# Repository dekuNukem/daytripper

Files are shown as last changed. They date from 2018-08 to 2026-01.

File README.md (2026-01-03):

# Daytripper: Hide-My-Windows Laser Tripwire

[Buy on Tindie](https://www.tindie.com/products/dekuNukem/daytripper-hide-my-windows-laser-tripwire/) | [Official Discord](https://discord.gg/VM4kbnf) | [Getting Started](quick_start_guide.md)

-----

Do you always slack off on your computer and worry about getting busted?

Not anymore because Daytripper is here to save the day!



Daytripper is a laser tripwire that can, upon triggering:

* Hide all your windows
* Lock your computer
* [Execute a custom script](/advanced_usage.md) to do whatever you want!

## Buy Daytripper on Tindie!

I did a small production run, and you can buy them directly on Tindie:

https://www.tindie.com/products/dekuNukem/daytripper

## How it Works

Daytripper comes in two parts: a Transmitter (TX) and a Receiver (RX).

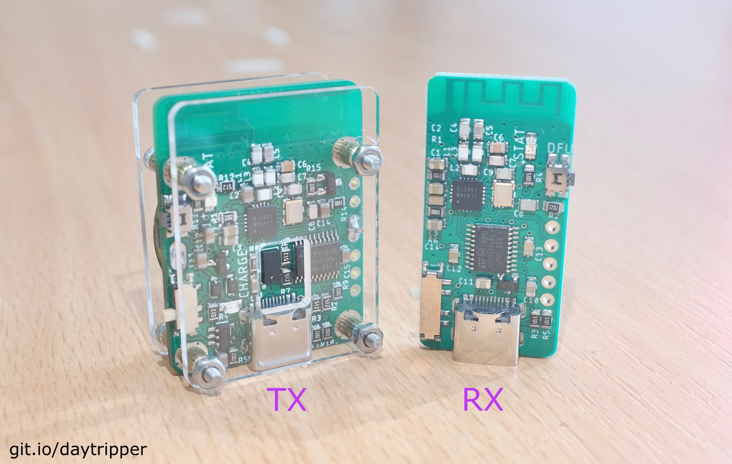
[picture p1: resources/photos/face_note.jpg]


Mount the TX in the path of incoming threat. Plug RX into your computer.

When motion is detected, RX will press `Win + M` and instantly hide what you're doing.

Alternatively, it can also lock your PC or [execute a custom script](/advanced_usage.md).

## Features

Daytripper...

* Can detect motion within 120cm (4 ft).

* Scan rate: 6Hz on battery, 30Hz while powered. Customisable with included software.

* Configurable parameters to suit your particular needs.

* 50-hour battery life, rechargeable via USB-C.

* Works out-of-box with Windows, compatible with all major OSs.

* 100 meter (330 ft) open-air communication range between TX and RX.

* Comes with a magnetic mounting kit.

* See [Quick Start Guide](https://github.com/dekuNukem/daytripper/blob/master/quick_start_guide.md) and [Advanced Usage Guide](https://github.com/dekuNukem/daytripper/blob/master/advanced_usage.md) for more details.

## Getting Started

If you received your Daytripper in kit form, follow this to put it together:

[Kit Assembly Guide](/assembly_guide.md)

For how to use Daytripper, see this:

[Quick Start Guide](/quick_start_guide.md)

For advanced features such as custom actions and adjusting settings, read this:

[Advanced Usage](/advanced_usage.md)

## Specification

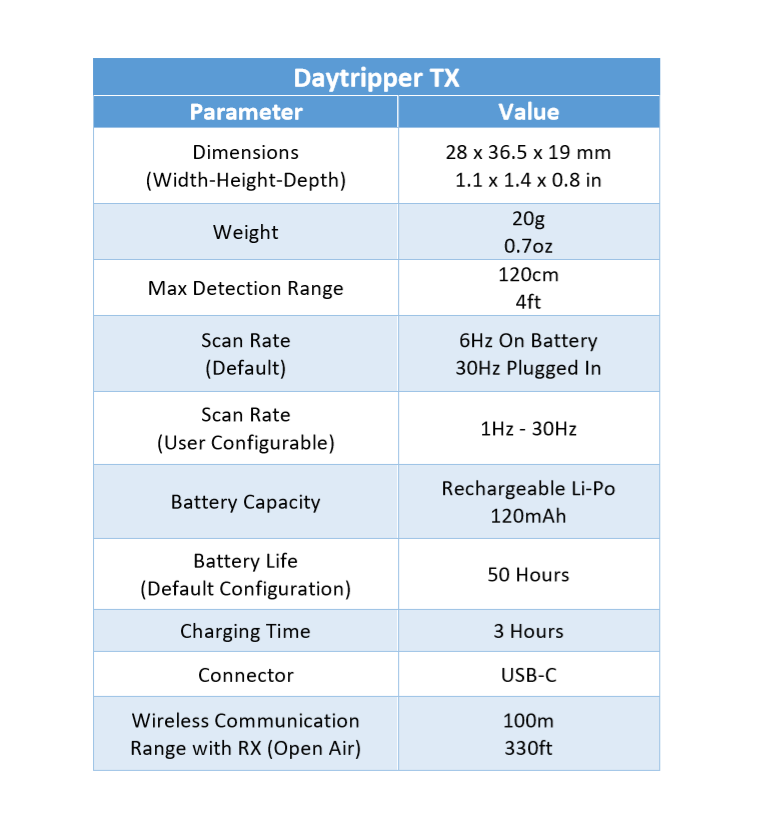
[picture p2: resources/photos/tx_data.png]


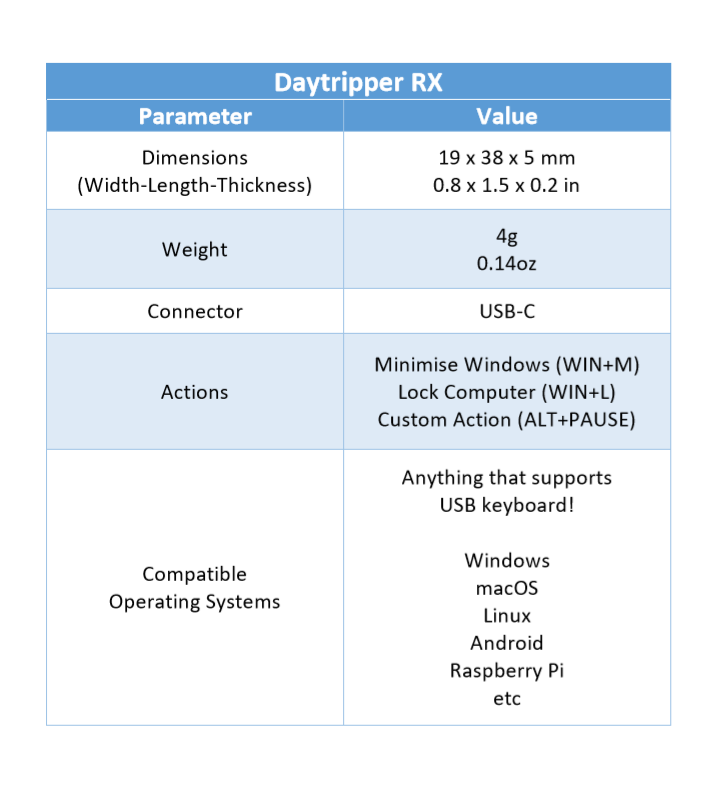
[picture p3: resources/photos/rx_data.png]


## FAQ

### What operating system is supported?

Daytripper works out-of-box with Windows. No driver needed.

It is also compatible with anything that supports USB keyboards, such as Linux, MacOS, Android, and more.

Read [Advanced Usage Guide](/advanced_usage.md) to see how to use it on other systems.

### What is the range of Daytripper?

The laser ToF sensor can detect motion within 120cm (4 ft).

The wireless communication range between TX and RX should be around 100 meters (330 feet) open air. Might be less in indoor environments. 

### Battery life?

Around 50 hours (more than 2 days!) with default configuration.

Can be increased or decreased by adjusting settings.

Rechargeable via USB Type-C connector.

### Can I use it for purposes other than hiding windows?

Yes. It can also lock your computer, or perform a custom action.

See [Advanced Usage Guide](/advanced_usage.md).

## I Want One!

I did a small production run, and you can buy them directly on Tindie:

https://www.tindie.com/products/dekuNukem/daytripper

## Questions or Comments?

Please feel free to [open an issue](https://github.com/dekuNukem/duckypad/issues), ask in the [official Daytripper discord](https://discord.gg/VM4kbnf), DM me on discord `dekuNukem#6998`, or email `dekuNukem`@`gmail`.`com` for inquires.

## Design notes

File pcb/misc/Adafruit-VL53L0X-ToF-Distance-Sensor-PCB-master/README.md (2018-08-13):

# Adafruit-VL53L0X-ToF-Distance-Sensor-PCB
PCB files for the Adafruit VL53L0X ToF Distance Sensor

Format is EagleCAD schematic and board layout

For more details, check out the product page at

  * https://www.adafruit.com/product/3177

Adafruit invests time and resources providing this open source design, 
please support Adafruit and open-source hardware by purchasing 
products from Adafruit!

Designed by Adafruit Industries.  
Creative Commons Attribution, Share-Alike license, check license.txt for more information
All text above must be included in any redistribution

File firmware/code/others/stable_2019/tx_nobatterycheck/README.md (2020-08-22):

This is a slightly modified TX firmware for always-plugged-in applications. 

Changes include:

* 30Hz refresh rate, compared to default 5Hz
* Microcontroller won't enter low-power mode anymore
* Microcontroller doesn't check battery voltage

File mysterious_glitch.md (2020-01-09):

# The Baffling Intermittent Glitch

## Discovery

Recently a few of my customer told me that the daytripper they received didn't work properly after assembled. Once turned on, the LED on the TX unit would breath for a few seconds, then go completely dead and not responding to objects in front of the sensors. 

I initially provided them with free replacements right away, however it did make me wonder how did it happen, since I personally test every single board before mailing them out.

One of the customers told me that the affected TX would work fine on its own as a bare circuit board, but go bad once assembled with front and back plates, which was even more baffling. How could some screws and two acrylic plates affect the functionality of the circuit board?

## Investigation

I put together a handful of TX boards trying to replicate the problem, testing to make sure they work both before and after. I assembled about 20 of them before finally got one that's misbehaving. The board would work fine on its own, but stop working once the upper standoffs were tightened to a certain degree.

I hooked up a debugger to see where it was stuck in the firmware. It appeared to be waiting forever at [checking if a packet transmission is complete](https://github.com/dekuNukem/daytripper/blob/865081e2ba3adbdf7ebfdae3229aa89da2c86ae7/firmware/tx_bss/Src/helpers.c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). Looking deeper into that, the data received from SPI are all `0x0` instead of usual `0x13`.

I didn't think much of it and kept on messing around. At one point I desoldered the battery to see if it would help, and miraculously it did! The TX would work no matter how much the standoffs were tightened. 

Things became clear once I looked at the circuit board more closely. Here is the back of the affected TX board, you can just barely see a scratch mark near the center:

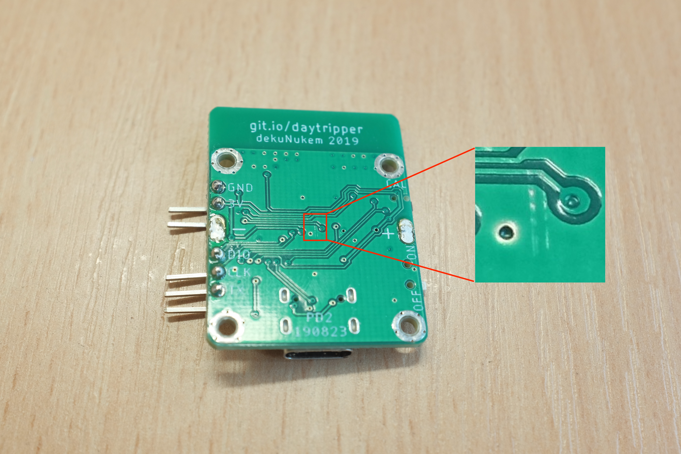
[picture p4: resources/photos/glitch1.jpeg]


What happened was that, on certain batteries, the negative terminal tab sticks out more than others:

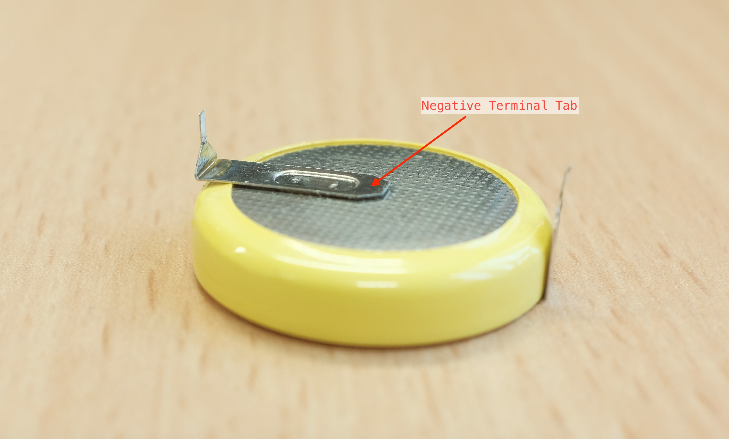
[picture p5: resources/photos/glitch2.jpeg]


As a result, for the majority of the boards, there is an air gap between the bottom of the battery and the circuit board, all is well:

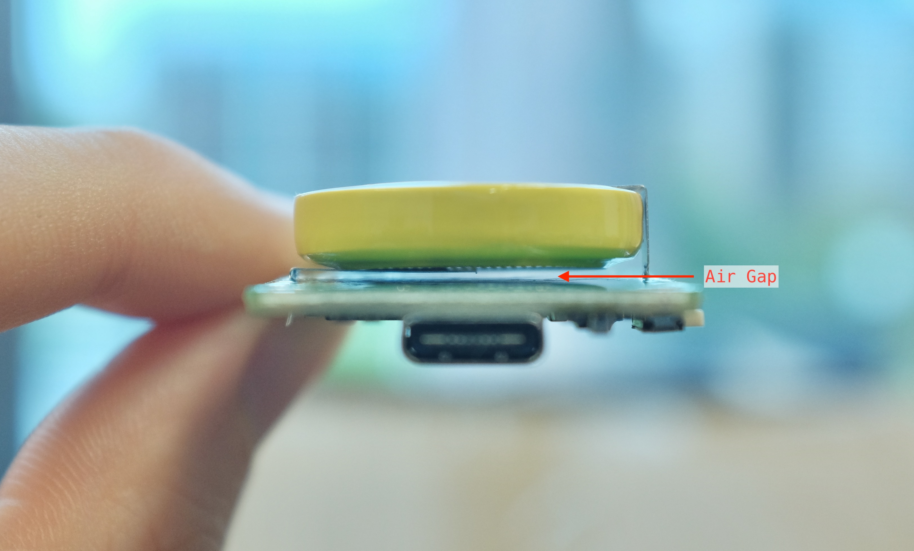
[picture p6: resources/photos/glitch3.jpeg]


But on the affected boards, the protruding battery terminal is very nearly touching the circuit board:

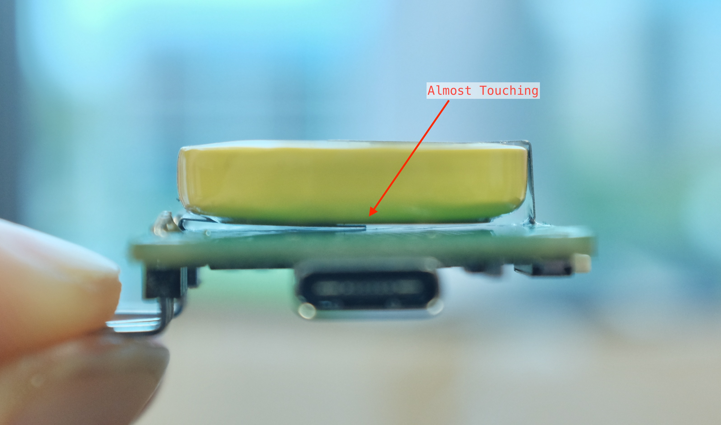
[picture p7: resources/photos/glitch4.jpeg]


Since they were not *actually* touching, everything would work fine when I test the bare circuit board myself. But when installed with fasteners, the back plate would push the terminal into the circuit board, scratching it, and grounding the SPI MISO data line. As a result, the firmware would get `0x0` from SPI, and stuck on waiting for a response.

## Remedy

From now on...

* Insulating materials will be added between the battery and circuit board

* Washers will be used so the back plate is less likely to push against the battery

* Visual inspection will be carried out to spot problem boards before shipping

* Traces will be rerouted away from potentially scratch-prone area in the future production run

## Existing Customers

This problem only affects a very small number of TX boards. If your daytripper is working fine, you don't have to do anything.

If you do encounter a similar problem, there are a number of ways to sort this out:

### Try Fixing It Yourself

* [Follow this guide in reverse](https://github.com/dekuNukem/daytripper/blob/master/assembly_guide.md) and disassemble the TX to bare circuit board.

* Hold it like the above photos, check the gap and see if battery is touching the board

* Try inserting a piece of paper between the two to prevent them from touching. Gently pull the battery up slightly to widen the gap, then slide the paper in.

* If it works, congrats! Feel free to contact me for a partial refund for the trouble.

* If not...

### Contact Me

If you weren't able to fix it yourself, do feel free to contact me with your Tindie order number. I'll be happy to offer you a full refund or mail you another set for free.

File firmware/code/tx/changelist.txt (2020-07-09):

switched to single ADC channel for battery voltage calculation
system clock now 16MHz to allow USB peripheral to function
added rtc sleep function, on-demand delay in stop mode.
reduce power consumption by 15% by putting uC in stop mode while waiting for ToF measurement.

TODO:
re-enable low-battery shutdown
change IWDG timeout prescaler back to 32
add charging detection
comment out printf() in check_battery()

current consumption observations:

sparkfun INA169 works really well
during sleep mode current is negligible
laser and nRF both consume around 20mA when active
negligible current difference between 8MHz and 16MHz clock, most of the time MCU is sleeping anyway.
negligible current on low-battery shutdown

USB initialization works only on fresh start-up
sleeping changes UART baud rate somehow

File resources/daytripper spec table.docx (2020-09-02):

Daytripper TX
Parameter | Value
Dimensions (Width-Height-Depth) | 28 x 36.5 x 19 mm 1.1 x 1.4 x 0.8 in
Weight | 20g 0.7oz
Max Detection Range | 120cm 4ft
Scan Rate (Default) | 6Hz On Battery 30Hz Plugged In
Scan Rate (User Configurable) | 1Hz - 30Hz
Battery Capacity | Rechargeable Li-Po 120mAh
Battery Life (Default Configuration) | 50 Hours
Charging Time | 3 Hours
Connector | USB-C
Wireless Communication Range with RX (Open Air) | 100m 330ft

Daytripper RX
Parameter | Value
Dimensions (Width-Length-Thickness) | 19 x 38 x 5 mm 0.8 x 1.5 x 0.2 in
Weight | 4g 0.14oz
Connector | USB-C
Actions | Minimise Windows (WIN+M) Lock Computer (WIN+L) Custom Action (ALT+PAUSE)
Compatible Operating Systems | Anything that supports USB keyboard! Windows macOS Linux Android Raspberry Pi etc

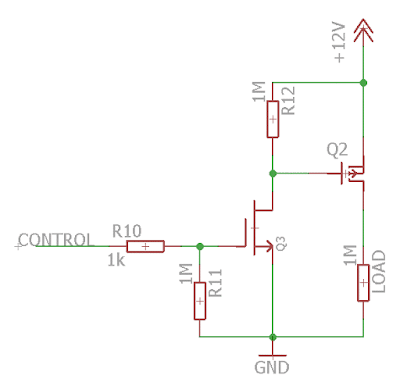
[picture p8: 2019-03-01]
resources/Part-time Electronics Basics FET as switch, part 2_files/pfet-2.png

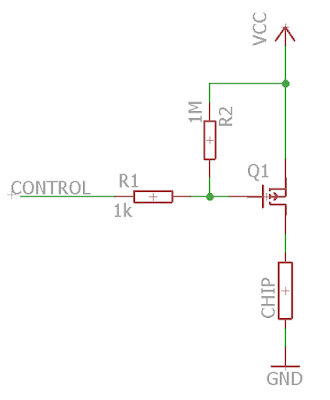
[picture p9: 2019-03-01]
resources/Part-time Electronics Basics FET as switch, part 2_files/pfet-1.png

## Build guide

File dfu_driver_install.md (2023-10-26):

# Installing the STM32 DFU Driver

First, make sure you have followed the procedure of **`holding down the DFU button while plugging in the device`**.

Once plugged in, you can release the button. The lights and screen should stay off.

If nothing shows up in `STM32 DfuSe tool`, you probably need to install a driver.

## Driver Install Instructions

**`Right click`** on the start button, then select `Device Manager`:

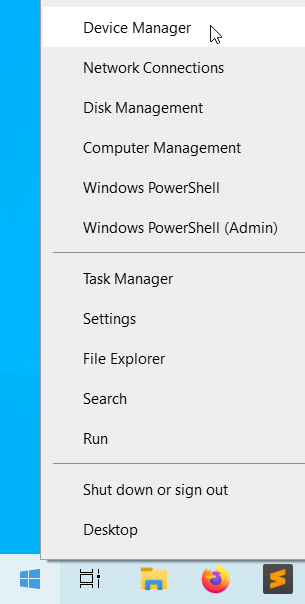
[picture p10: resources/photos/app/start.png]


Expand the node for USB devices. If you see a device with a similar name to **`STM32 Bootloader`**:

Right click, select `Uninstall Device`, check `Delete driver software` box, then press `Uninstall`.

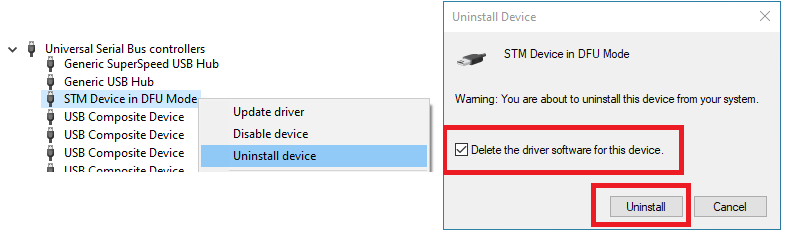
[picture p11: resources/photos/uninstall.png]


Now you should have a **`STM32 BOOTLOADER`** device with yellow triangle.

**`Double click`** on it, select `Update Driver...`, then select `Browse my computer for driver software`

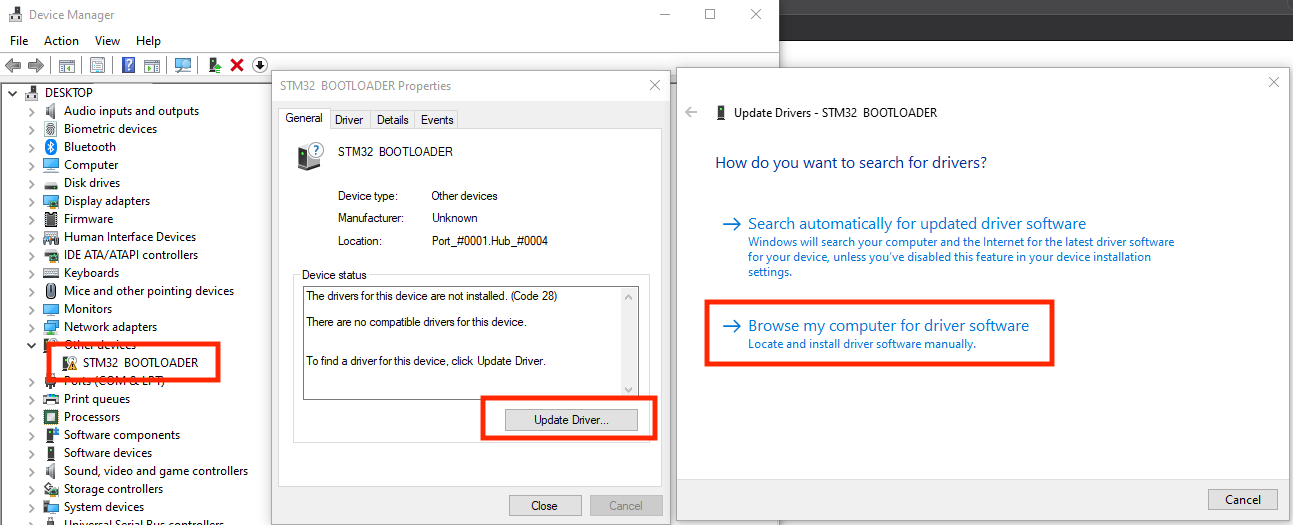
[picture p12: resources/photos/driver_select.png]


Press `Browse...`, and select the entire folder below:

`C:\Program Files (x86)\STMicroelectronics\Software\DfuSe v3.0.6\Bin\Driver\Win10`

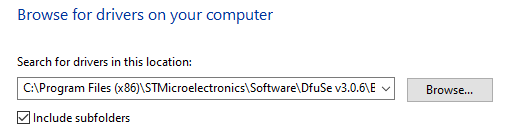
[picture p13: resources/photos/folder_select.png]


Windows should find and install the driver automatically.

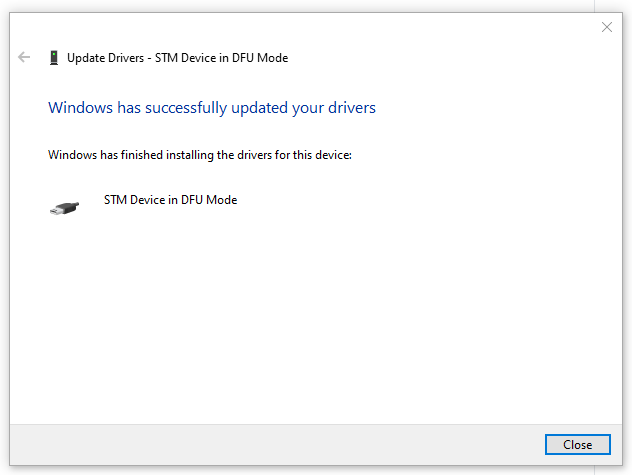
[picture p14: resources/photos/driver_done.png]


After it's done, you can continue the guide as usual.

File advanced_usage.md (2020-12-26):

# Daytripper Advanced Usage Guide

[Buy on Tindie!](https://www.tindie.com/products/dekuNukem/daytripper-hide-my-windows-laser-tripwire/) | [Official Discord](https://discord.gg/VM4kbnf) | [Getting Started](quick_start_guide.md) | [Main Page](/README.md)

-----

If you're not familiar with Daytripper yet, please see the [Quick Start Guide](/quick_start_guide.md) first.

## Table of Contents

[Creating Custom Actions](#custom-actions)

[Adjusting Advanced Parameters](#adjusting-advanced-parameters)

[On-Air Packet Format](#on-air-packet-format)

[Debug Mode](#debug-modes)

[USB Firmware Update](#usb-firmware-updates)

[Trigger Output](#trigger-output)

[Using Multiple Modules](#using-multiple-modules)

## Custom Actions

Instead of hiding windows, you can perform custom actions when TX is triggered.

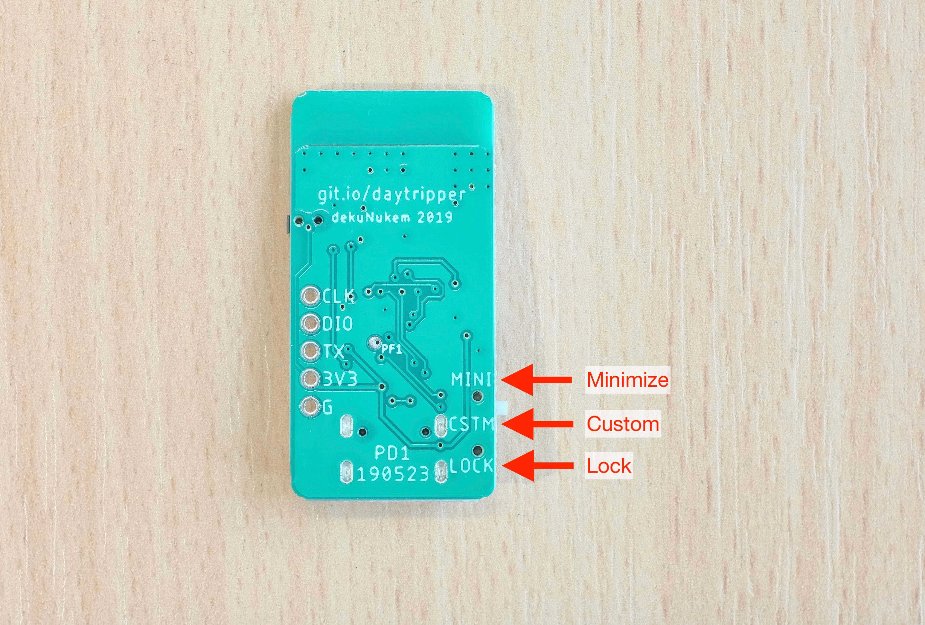
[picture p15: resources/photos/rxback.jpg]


Slide the `Mode Select` Switch on RX to `CUSTOM`, middle position. Now `ALT + PAUSE` will be pressed when TX is triggered. 

This key combo normally doesn't do anything, but you can capture it with a software and then perform your own actions. 

### Windows 

You can use [autohotkey](https://www.autohotkey.com). It is a powerful and free open-source keyboard automation program, where you can write a script to do anything you want when `ALT + PAUSE` is pressed by RX.

Check out the [official tutorials](https://www.autohotkey.com/docs_1.0/Tutorial.htm), and here's a [sample configuration file](resources/AutoHotkey.ahk) upon which you can tinker with. 

### macOS

When you first plug RX into your mac, a window might pop up asking to identify keyboard layout, simply close it.

Go to `System Preferences` -> `Keyboard` -> `Shortcuts` -> `App Shortcuts`:

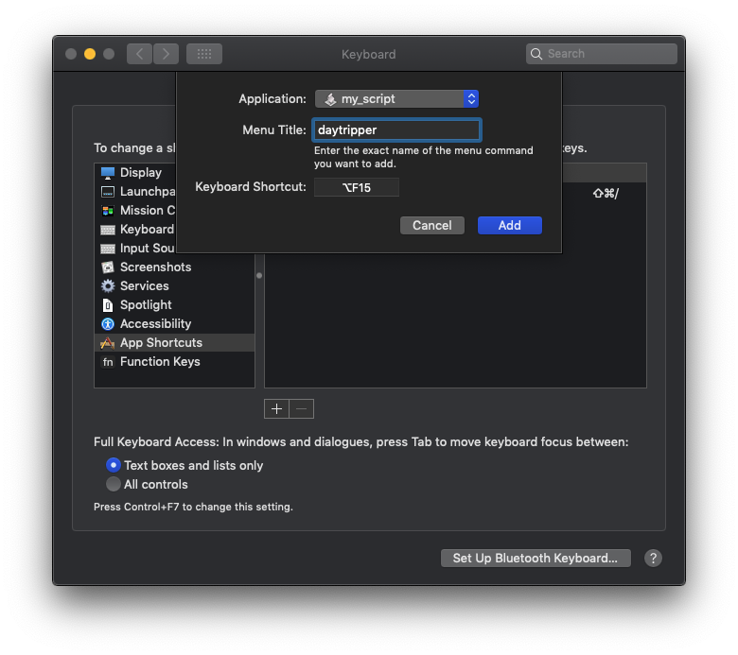
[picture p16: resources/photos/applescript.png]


Click the box to the right of `Keyboard Shortcut`, trigger the TX, and it will fill in the box for you.

You can then add a shortcut to launch an application, or execute an applescript.

For more advanced scripting needs, you can try [bettertouchtool](https://folivora.ai), which can be considered macOS equivalent of autohotkey.

### Android

Believe it or not Daytripper also works on Android!

You can use [Tasker](https://tasker.joaoapps.com) with [Autoinput plugin](https://joaoapps.com/autoinput/).

Here is a tutorial: https://forum.joaoapps.com/index.php?resources/react-to-keys-from-a-real-keyboard.79/

### Linux

Oh I'm sure you'll figure it out 😉

## Adjusting Advanced Parameters

The default settings of Daytripper demonstrates a good balance between accuracy, sensitivity, and battery life. 

However, you can also adjust them to suit your particular needs.

### Update the Firmware

If you purchased your Daytripper before **`Sept 2020`**, you will need to update your TX to the latest firmware. Please do so by following the [USB Firmware Update](#usb-firmware-updates) section below.

### Find the COM Port

**`Right click`** on the start button, then select `Device Manager`:



Make sure the TX is **`TURNED OFF`**, then plug it into your computer with a USB-C cable.

In the `Ports (COM & LPT)` section, A new `USB Serial Device` should appear.



Remember the number! **`COM5`** in this case. Yours might be different.

### Download the Application

[Head here to download the latest release](https://github.com/dekuNukem/daytripper/releases/latest) for Windows and macOS.

* The software is in early stages of development. If you run into any problems, please don't hesitate to [open an issue](https://github.com/dekuNukem/daytripper/issues), ask in the [official Daytripper discord](https://discord.gg/VM4kbnf), DM me on discord `dekuNukem#6998`, or contact me through `dekuNukem`@`gmail`.`com`.

### "Untrusted App" Warnings

When trying to run the app, your system might complain about this software being untrusted. This is because I haven't had the code digitally signed, which costs hundreds of dollars a year.

Please feel free to [review the code](https://github.com/dekuNukem/daytripper/tree/master/pc_software). If you don't trust the app, you can run the `duckypad_config.py` script itself with Python3.

For Windows 10, click `More info` and then `Run anyway`.

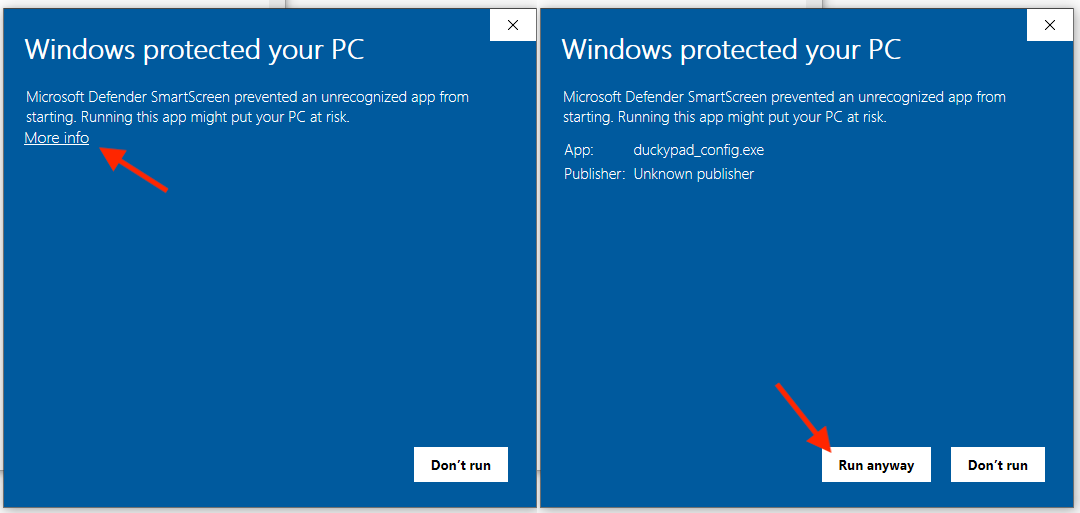
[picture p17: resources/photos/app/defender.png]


For macOS, **`RIGHT CLICK`** on the app and select `Open`. You might have to do it twice.

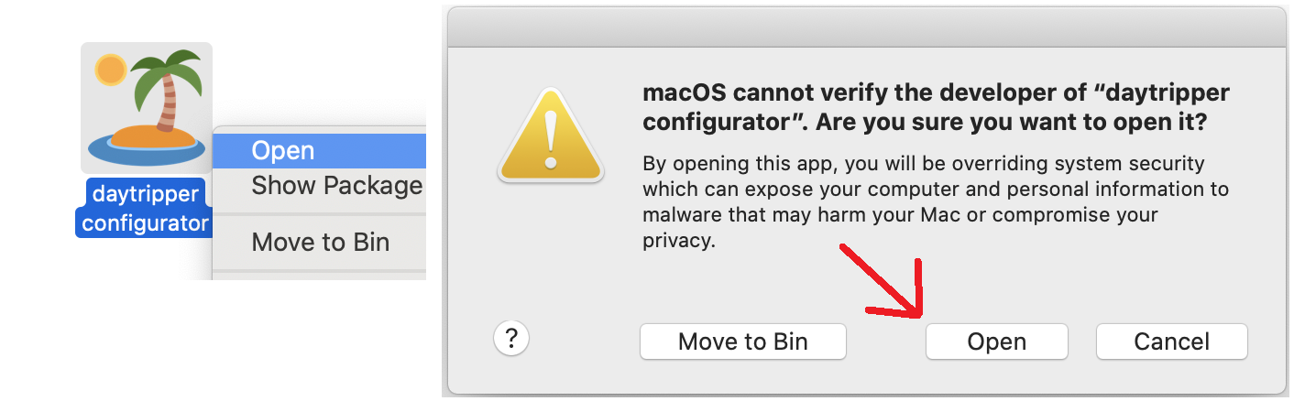
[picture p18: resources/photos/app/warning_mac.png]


After the app has launched, press `Refresh` button, select the COM port with the correct number, and press `Connect`.

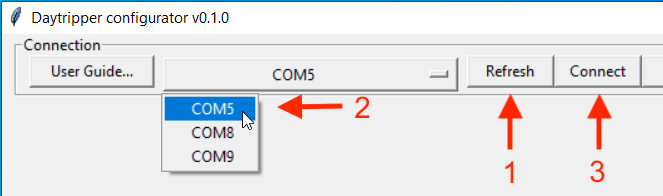
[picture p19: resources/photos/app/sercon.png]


On macOS or Linux, the serial port will have different names, and mostly likely will have the word `usb` in it.

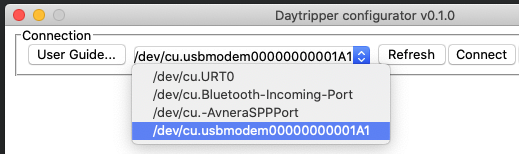
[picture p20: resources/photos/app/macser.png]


Anyway, if connection is successful, a number of options is presented:

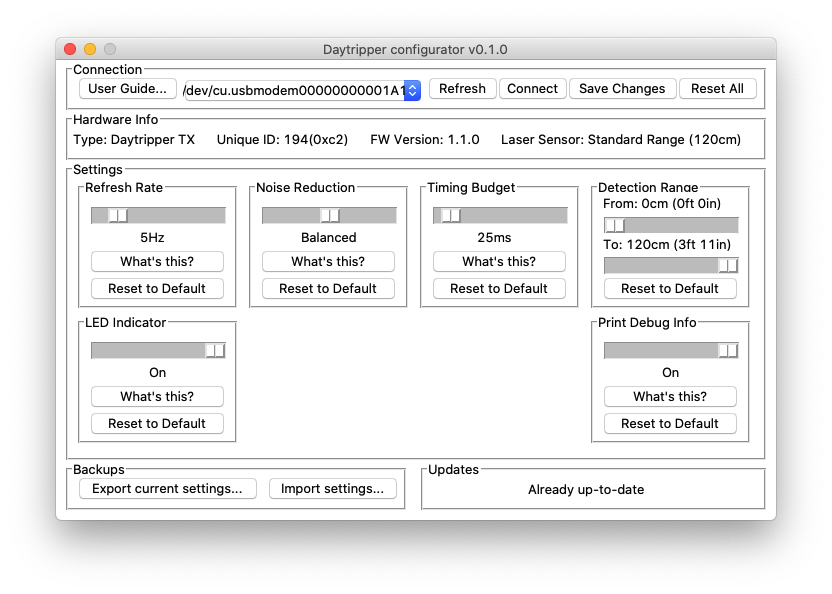
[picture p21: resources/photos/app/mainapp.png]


* Drag the slider to adjust values.

* Click **`What's this?`** to learn about a particular setting.

* To return to default, click **`Reset to Default`** in a section, or **`Reset all`** on top right corner.

* Click **`Save Changes`** to save the current configuration to your Daytripper.

* You can make a backup of your settings with the buttons on lower left corner.

* A description of parameters follows.

### Refresh Rate

How many times per second TX takes a reading **`while on battery`**. Turn it up to make TX more sensitive to faster motions, at the expense of battery life.

Here is a table of approximate Battery Life vs Refresh Rate:

| Refresh Rate (Hz) | Battery Life (Hours) |
|---|---|
| 2 | 100 |
| 6 (Default) | 50 |
| 10 | 30 |
| 15 | 20 |
| 30 | 12 |

Please note that your battery life might be more or less depending on your lighting conditions and number of triggers.

TX will always run at fastest refresh rate (30Hz) when plugged in.

### Noise Reduction

By default TX will take additional readings to prevent false triggers from sensor noise.

If turned off, TX will become **`much more`** sensitive to motion, but might also produce false triggers from time to time.

Turn it off if motion sensitivity is absolutely critical and occasional false triggers is acceptable.

### Timing Budget

Amount of time allocated to the laser sensor to produce a reading.

A larger value gives more accurate measurements, at the expense of reduced battery life and refresh rate.

I suggest leaving it at default for normal operations.

### Detection Range

Adjust the values here if you want Daytripper to only monitor motions within a certain distance range.

### LED Indicator

The blue LED comes on when TX is triggered. You can disable it to make your Daytripper less noticeable.

### Print Debug Info

TX prints some debug messages through its hardware UART. Turning it off might save a tiny bit of battery life.

### Save It!!

Again, don't forget to press **`Save Changes`** button to save the current configuration to your Daytripper.

## On-air Packet Format

Daytripper uses a nRF24L01-compatible chip called Si24R1. It is less expensive, and actually has a higher TX power output, resulting in longer communication range.

Daytripper operates at `channel 115`, `address 0xDA 0xBB 0xED 0xC0 0x0C`.

Data rate is `250kbps`, TX power is `+7dBm`, `Auto Acknowledgment` is used.

Daytripper TX sends 6-byte packets, details below:

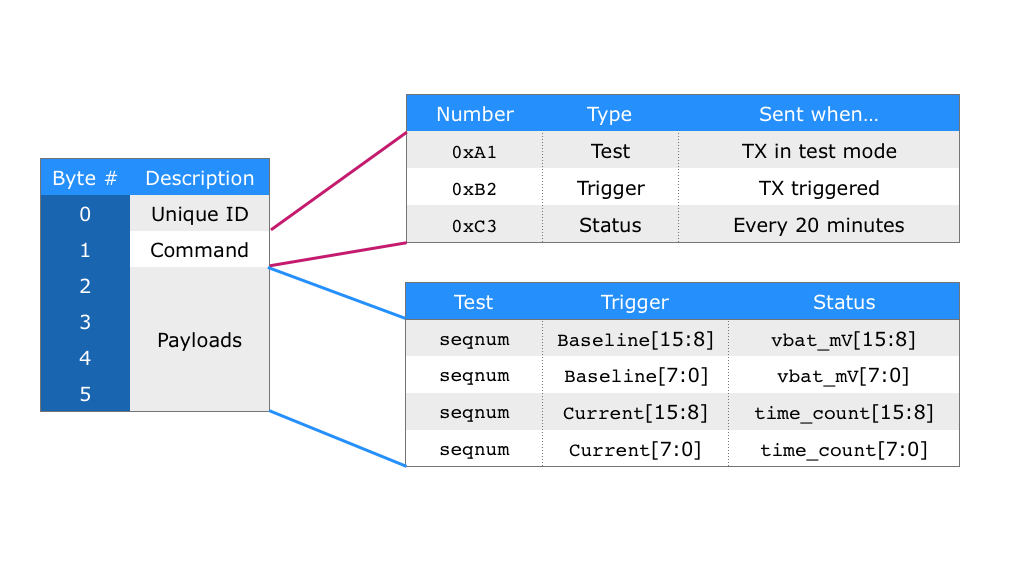
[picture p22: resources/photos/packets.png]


* The first byte (byte 0) is a unique identifier calculated from the microcontroller serial number. 

* Second byte (byte 1) denotes what this packet is about. It can be either a test packet, trigger packet, or status update packet.

* The rest 4 bytes are payloads, their meaning depending on the command type (byte 1).

* For a `Test` packet, the 4 bytes are the same incrementing sequence number repeated 4 times. 

* For a `Trigger` packet, the first two bytes are the baseline reading of the power-up calibration. And the last two bytes are the actual distance reading. Unit in mm.

* For a `status` packet, the first two bytes are the latest battery voltage reading in mV. The last two bytes are the time-since-power-on count, multiply it by 5 to get the number of seconds elapsed since TX power-on.

* The `vbat_mV` is about 300mV lower than the actual battery voltage, due to the diode drop. 

## Debug Modes

There is a user button on both TX and RX board. Usually they are unused:

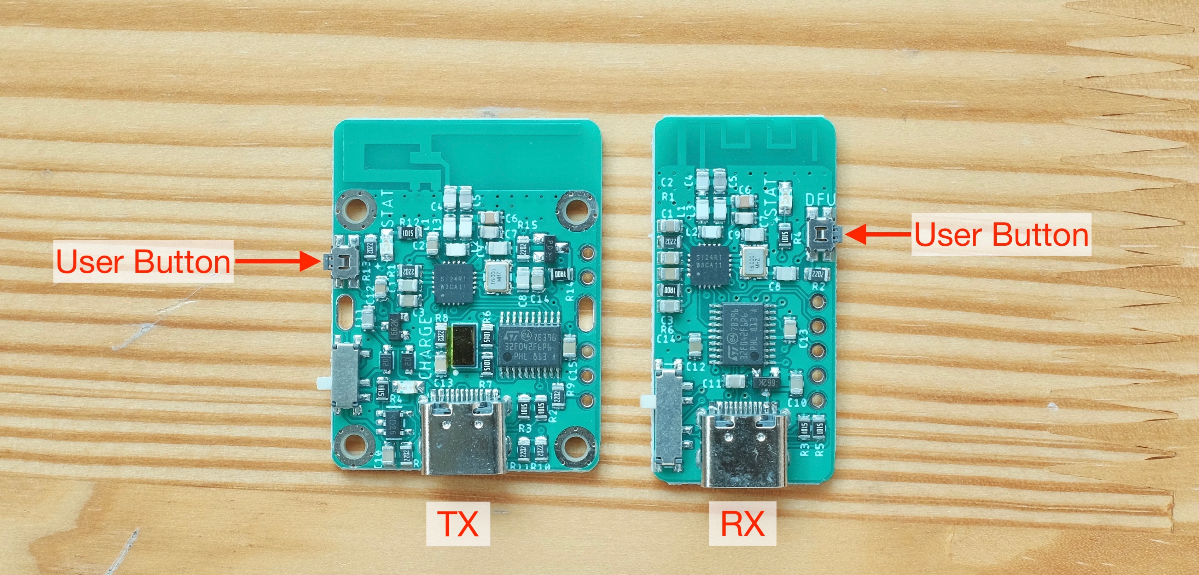
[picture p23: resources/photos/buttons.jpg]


For RX, a press on the button types out some debug messages. Make sure you open a text editor first. If the RX has not received any messages from the TX, the debug values will all be zero.

## USB Firmware Updates

You can update Daytripper's firmware via USB, for bug fixes and and/or new features. 

First, [click me](https://github.com/dekuNukem/daytripper/raw/master/resources/en.stsw-stm32080_stm32_DfuSe.zip) to download and install the `STM32 DfuSe tool` from this repo.

(You can also get it from [the official website](https://www.st.com/en/development-tools/stsw-stm32080.html), but it requires creating an account.)

Locate the user button on the board:



To update firmware:

* Make sure the board is **`TURNED OFF`** and unplugged.

* **Press and hold down the user button** while plugging it into a computer.

* Once it is plugged in, you can release the button.

* If all goes well, the blue LED should stay off.

Now launch the `DfuSeDemo` software:

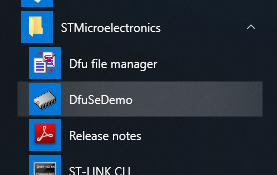
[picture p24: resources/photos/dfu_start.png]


You should see a `STM Device in DFU Mode` in the `Available DUF Devices` section at top left corner.

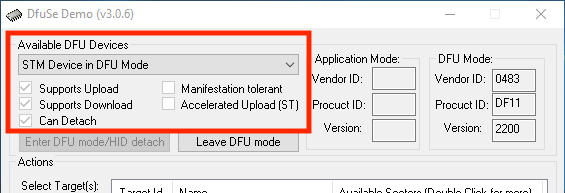
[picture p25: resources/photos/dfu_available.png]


* If nothing shows up, you might need to install a driver. [Click me for details](dfu_driver_install.md)  

Press the `Choose...` button and select a firmware file in `.dfu` format. Make sure it's the correct file!

* [Click me](https://github.com/dekuNukem/daytripper/raw/master/firmware/TX_1.1.2.dfu) for latest TX firmware (1.1.2)

* [Click me](https://github.com/dekuNukem/daytripper/raw/master/firmware/RX_1.0.1.dfu) for latest RX firmware (1.0.1)

* [Click me](/firmware_version_history.md) for older firmwares.

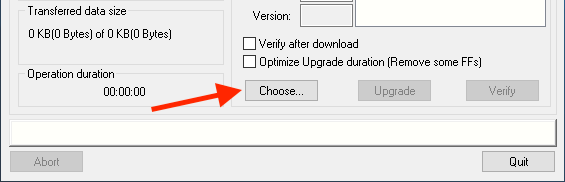
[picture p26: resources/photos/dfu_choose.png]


Press `Upgrade` button to start uploading the new firmware into the microcontroller.

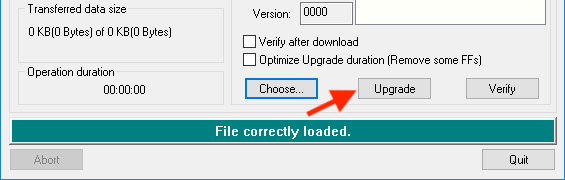
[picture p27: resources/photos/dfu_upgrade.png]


And now the firmware is being updated!

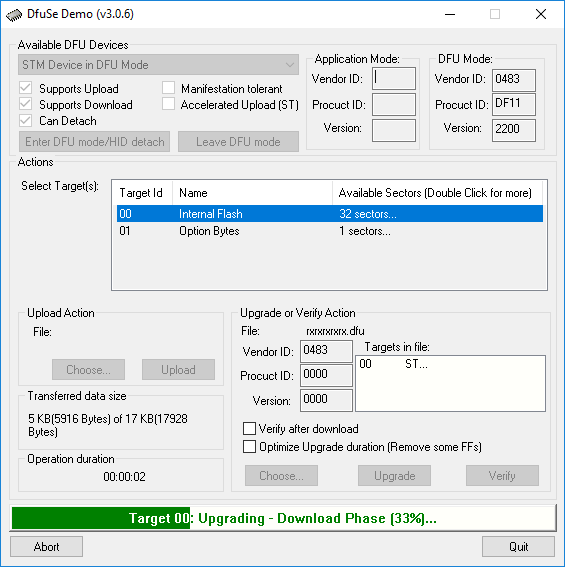
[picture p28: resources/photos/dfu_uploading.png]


It could take anywhere between a few seconds to a few minutes. Try using different USB ports if it is particularly slow. 

After uploading is complete, unplug and turn it back on to start using the new firmware. 

* Your custom settings will be lost after flashing a new firmware, so make sure to set it up again!

-----

If you generated a `.hex` file yourself, you can convert it to a `.dfu` file with the `Dfu file manager` and then upload this way. 

This method is nice for occasional firmware updates, but quite cumbersome if you want to do extensive reprogramming. It's faster to get a ST-Link programmer and use the Keil uVision IDE. [See this guide](https://github.com/dekuNukem/STM32_tutorials) for more information on STM32 developments.

## Trigger Output

There is an **`active-high`** trigger output on RX. This pin will go from GND to 3.3V for **`around 200ms`** when a trigger from TX is received.

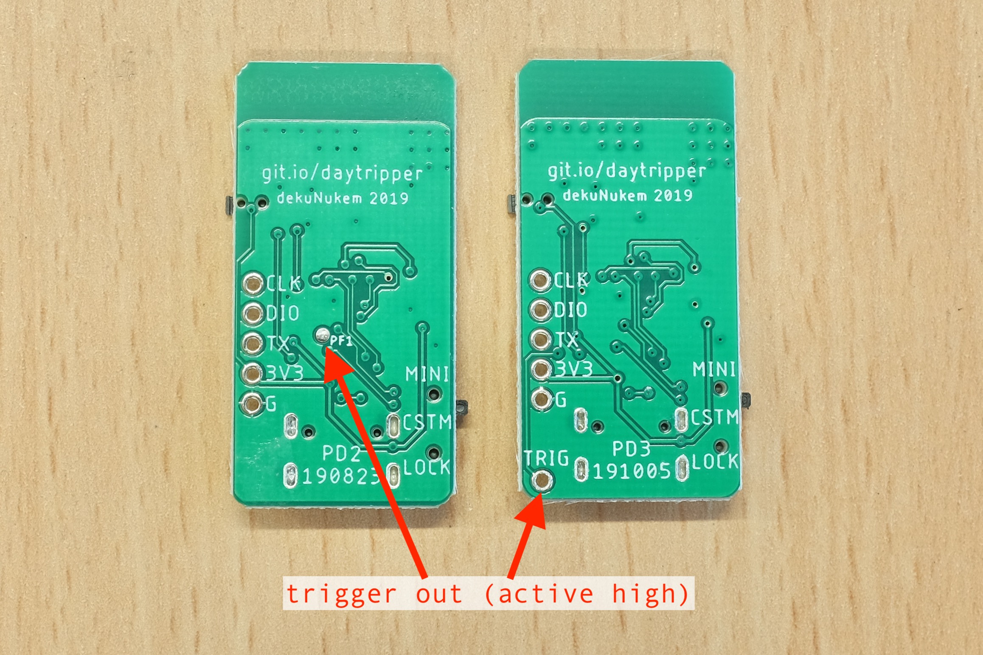
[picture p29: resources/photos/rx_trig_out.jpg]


On earlier production runs, the pin is on a testpad. On the later runs, the pin has its own header hole.

Make sure **everything is on the same GND** when connecting external circuits!

Unfortunately, TX does not have a dedicated trigger out pin due to limited microcontroller pins. However, there is a debug output that prints out some serial data upon triggering at 115200bps, which you can parse.

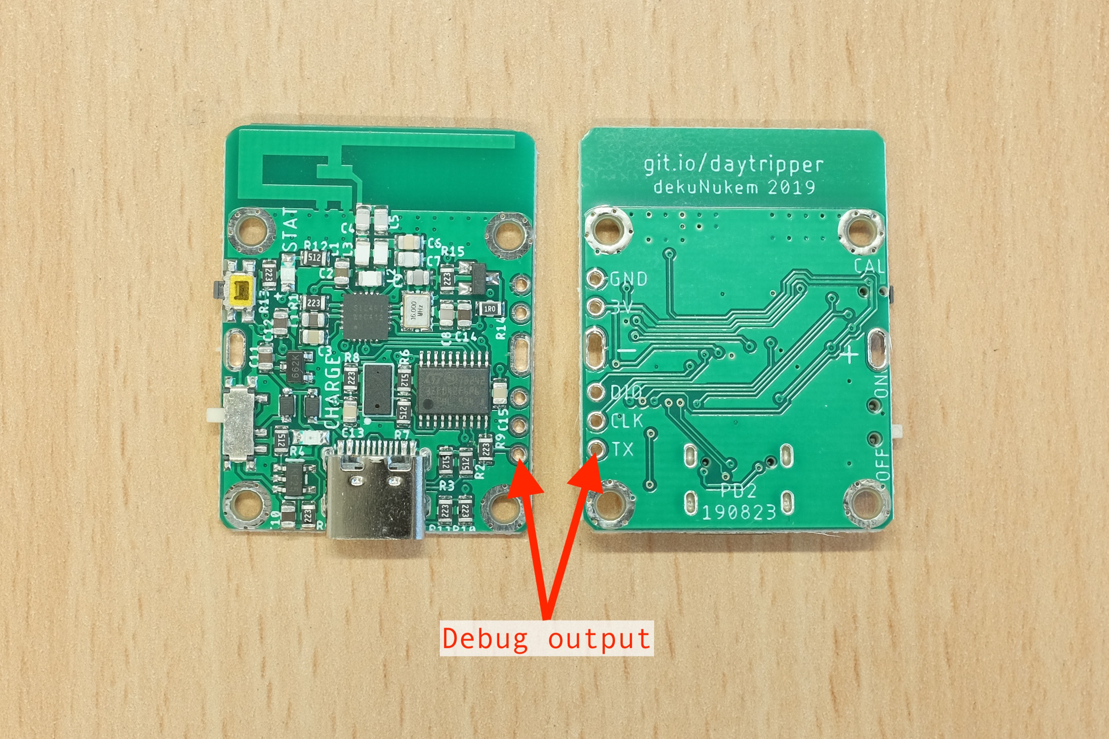
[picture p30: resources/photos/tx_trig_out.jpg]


## Using Multiple Modules

Daytripper wasn't really designed with multiple TX/RX boards in mind. I haven't done any extensive testings on this subject, however most of the time it does seem to work.

### Single RX Multiple TX

In this scenario RX will react when ANY of the multiple TX fires.

### Single TX Multiple RX

Here ALL of RX will react when TX fires.

### Multiple TX Multiple RX

Untested, probably a mess. 

## Questions or Comments?

Please feel free to [open an issue](https://github.com/dekuNukem/duckypad/issues), ask in the [official Daytripper discord](https://discord.gg/VM4kbnf), DM me on discord `dekuNukem#6998`, or email `dekuNukem`@`gmail`.`com` for inquires.

------

[Main Page](/README.md) | [Buy Daytripper](https://www.tindie.com/products/dekuNukem/daytripper)

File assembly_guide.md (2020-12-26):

# Daytripper Kit Assembly Guide

[Buy on Tindie!](https://www.tindie.com/products/dekuNukem/daytripper-hide-my-windows-laser-tripwire/) | [Official Discord](https://discord.gg/VM4kbnf) | [Getting Started](quick_start_guide.md) | [Main Page](/README.md)

-----

Thanks for purchasing Daytripper! Here is a short guide on how to put everything together.

If yours is already assembled, please move on to the [Quick Start Guide](/quick_start_guide.md).

## Recommended Tools

A pliers and a small Phillips-head screwdriver would make tightening the fasteners easier.

However this assembly is perfectly doable with your bare hands, so don't sweat if you don't have them.

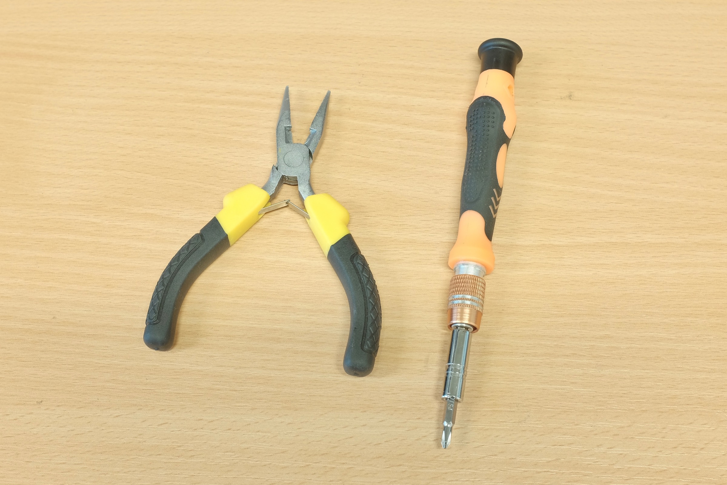
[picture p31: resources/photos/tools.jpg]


## Handling Bare Circuit Boards

When handling the bare circuit board, remember to:

* Wash your hands first

* Always hold the circuit board by its edge

* Don't touch the components

The reason for hand-washing is to reduce the risk of static electricity(SE) on your body zapping the board and damage it, especially in dry weather.

By washing your hands, you release the existing SE through the metal water pipe, your hands are moist to prevent further SE build-up, and your clean hands won't leave greasy fingerprints all over the place, win-win-win!

Of course, your hands can't be dripping wet either, but that's just common sense.

## Mind the Switches!

During assembly, be careful not to accidentally break off the handles of the switches on the two circuit boards:

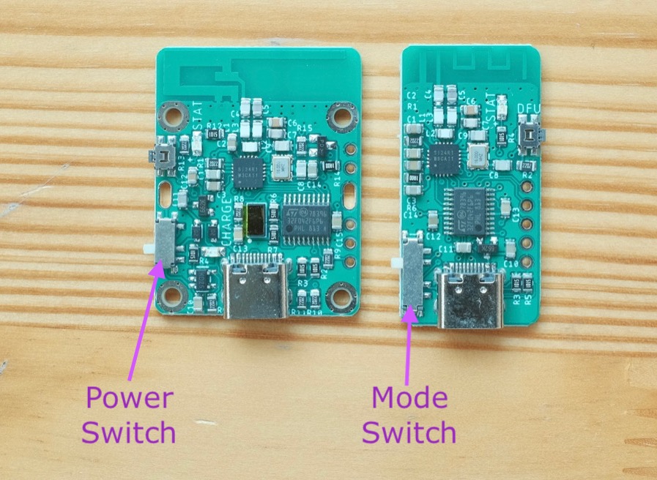
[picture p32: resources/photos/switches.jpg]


## Assembly Steps

You should have the following parts, keep a note of their names as I'm going to refer to them later. 

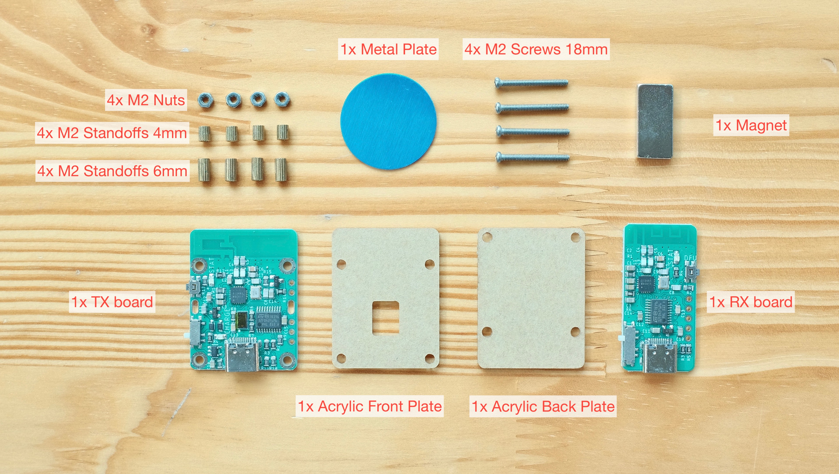
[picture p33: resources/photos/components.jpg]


First off peel off the protective film on the `Acrylic Front and Back plate`. You don't have to do it if you like the unpeeled look. 

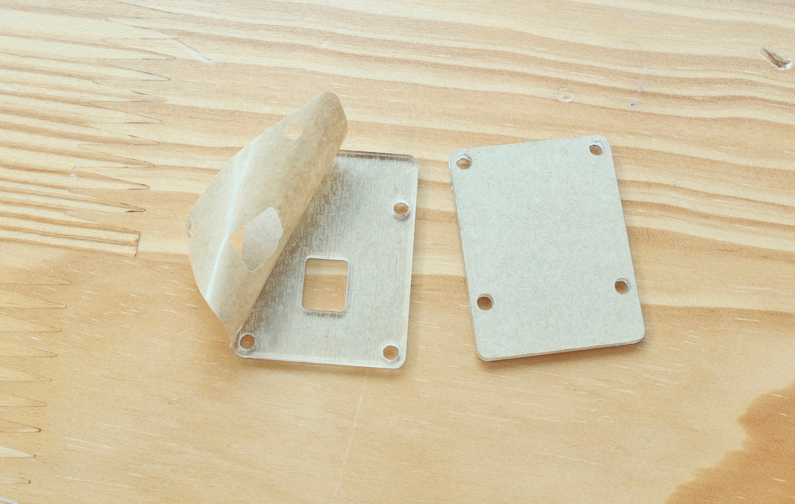
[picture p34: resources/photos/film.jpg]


Gather the `Acrylic Back Plate`, `4x M2 Standoffs 6mm`, and `4x M2 Screws 18mm`.

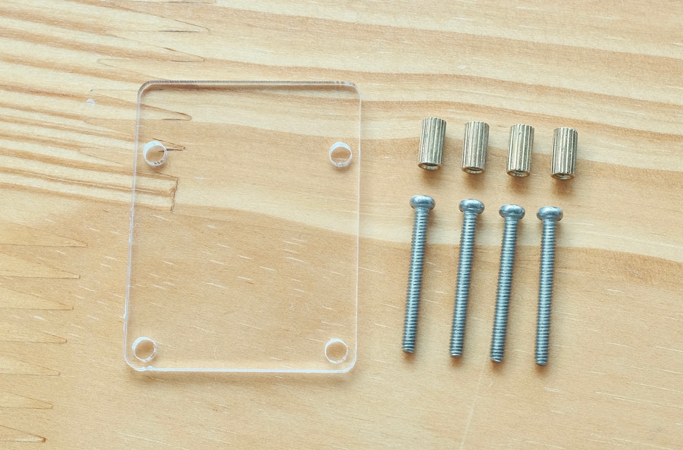
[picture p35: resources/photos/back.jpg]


Thread the screw through the hole, then screw on the standoffs.

Do not overtighten the standoff! Doing so might crack the acrylic plate. Finger-tight is OK, just make sure they're not loose and doesn't rattle.

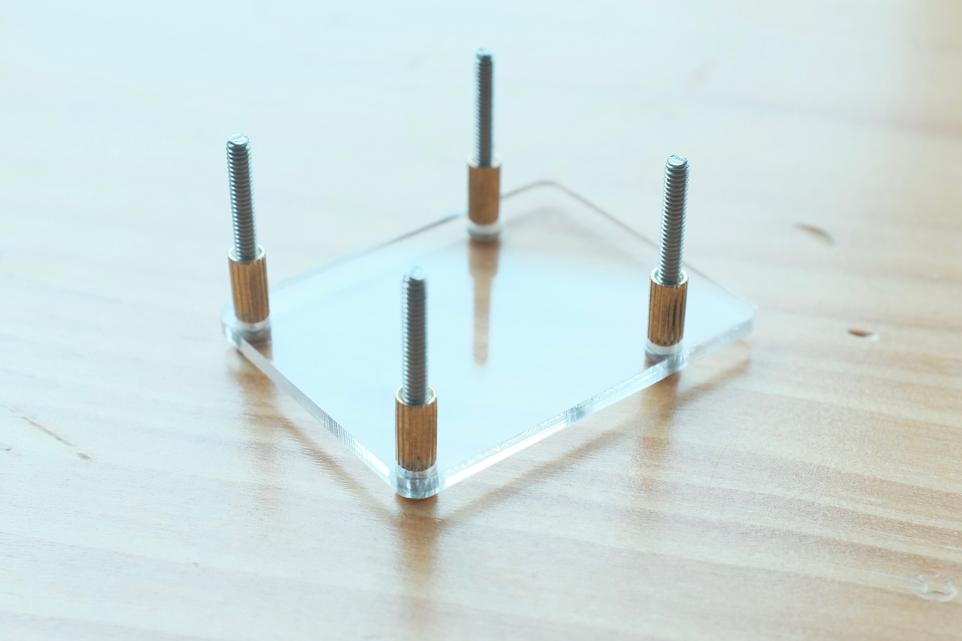
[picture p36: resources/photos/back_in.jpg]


Wash your hands, grab the circuit board by its edge, and install the `TX board` as shown:

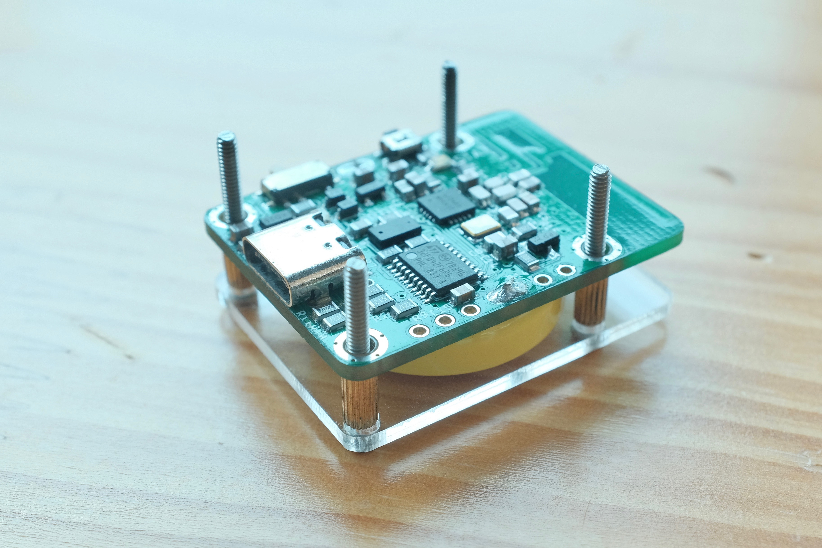
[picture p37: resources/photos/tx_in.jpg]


Screw on the `4x M2 Standoff 4mm`. Moderately tighten.

* If you're using pilers, make sure it doesn't bump into circuit board components while turning!

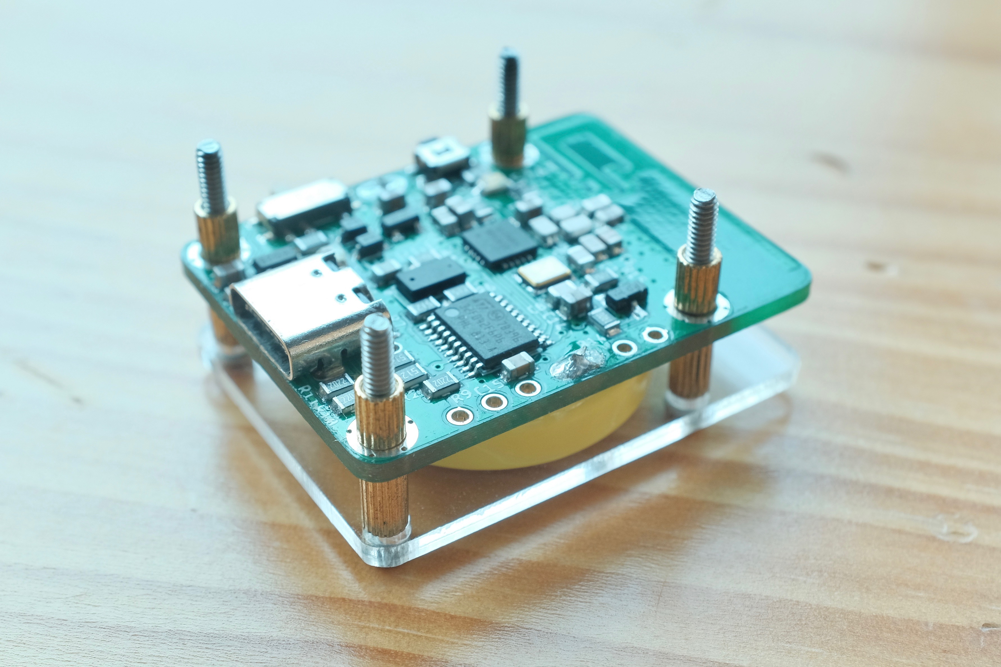
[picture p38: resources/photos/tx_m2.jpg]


Install the `Acrylic Front Plate` as shown. 

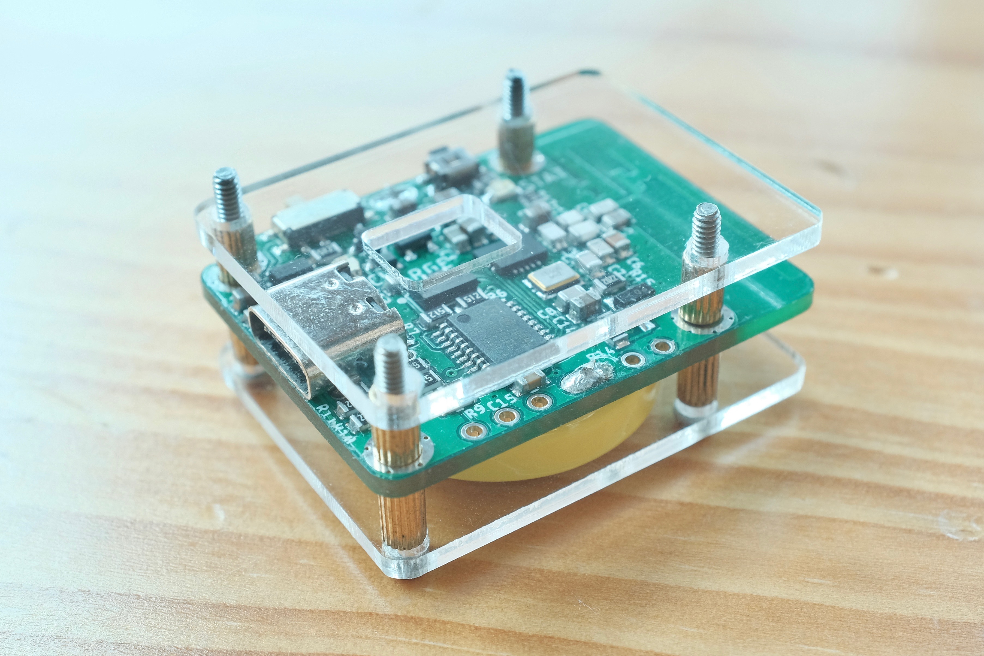
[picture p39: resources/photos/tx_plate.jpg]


Put on the nuts. Again don't overtighten. Might be easier with pilers. 

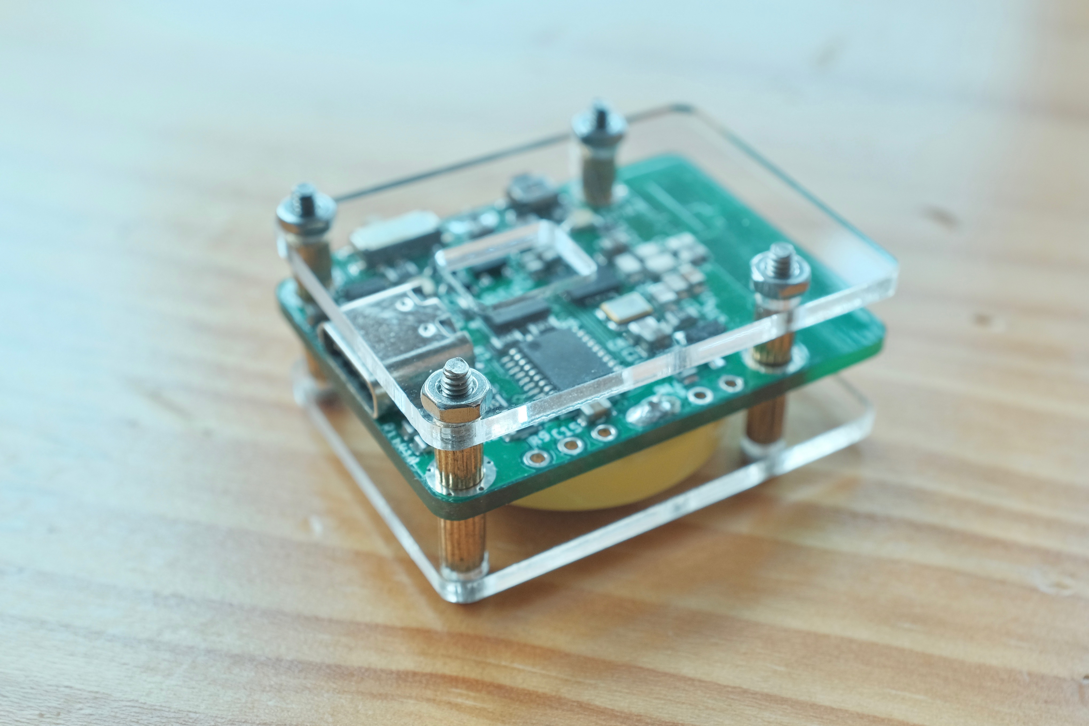
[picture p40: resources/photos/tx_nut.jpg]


Flip it over. Clean the backplate with a dry cloth if dirty.

Peel the metal plate from the white side to expose the adhesives.

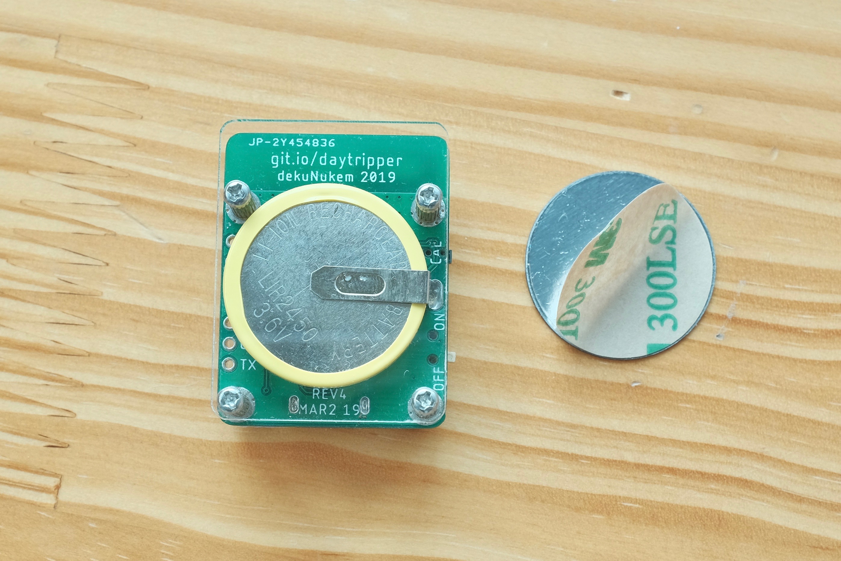
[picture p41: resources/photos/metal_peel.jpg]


Stick the metal plate to the back plate, preferably where the battery is. 

Peel off the blue protective film, and we're done!

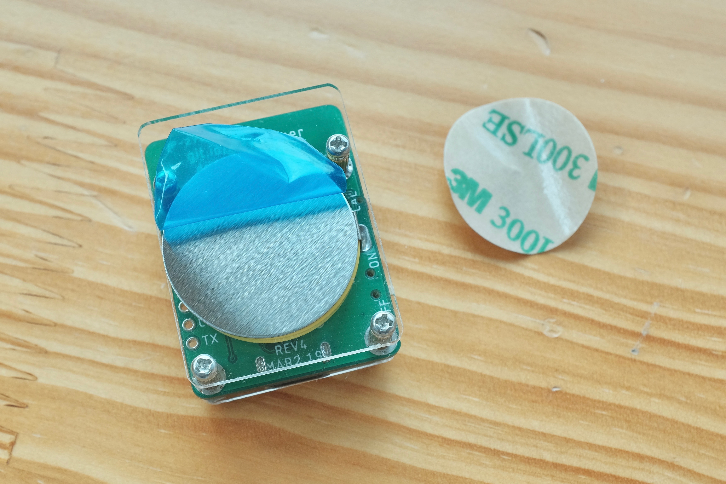
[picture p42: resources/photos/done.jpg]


Now your Daytripper is ready to use! Head over to the [Quick Start Guide](/quick_start_guide.md) to get going.

## Questions or Comments?

Please feel free to [open an issue](https://github.com/dekuNukem/duckypad/issues), ask in the [official Daytripper discord](https://discord.gg/VM4kbnf), DM me on discord `dekuNukem#6998`, or email `dekuNukem`@`gmail`.`com` for inquires.

------

[Main Page](/README.md) | [Buy Daytripper](https://www.tindie.com/products/dekuNukem/daytripper)

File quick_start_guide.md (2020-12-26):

# Daytripper Quick Start Guide

[Buy on Tindie!](https://www.tindie.com/products/dekuNukem/daytripper-hide-my-windows-laser-tripwire/) | [Official Discord](https://discord.gg/VM4kbnf) | [Getting Started](quick_start_guide.md) | [Main Page](/README.md)

------

This guide shows you how to use the Daytripper.

If yours hasn't been assembled yet, please [see this guide to put it together](/assembly_guide.md)

## Getting Started

By now, you should have the assembled transmitter(TX) and receiver(RX) boards.

Please observe the various names that will be referred to later:

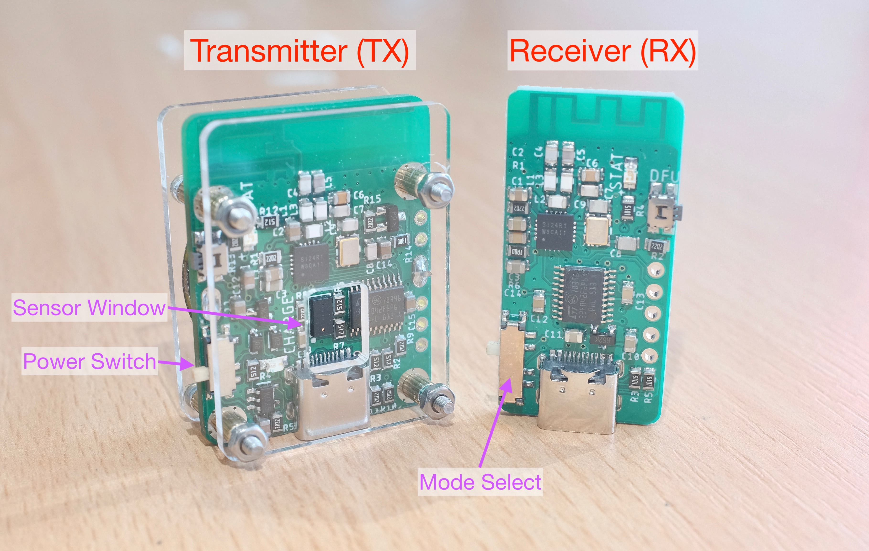
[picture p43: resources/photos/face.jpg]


Your RX board should have a translucent protective cover, don't remove it!

Plug the RX into your computer. Its blue LED should start breathing then go dim, and your PC should recognize it as an USB keyboard.

Sometimes the system will install a driver, wait for it to finish.

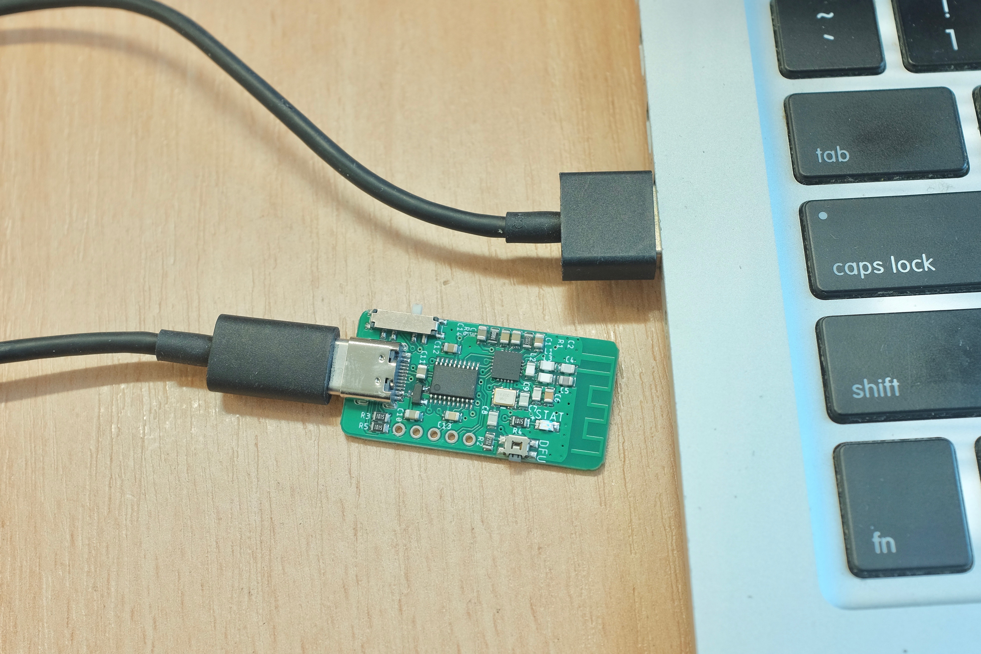
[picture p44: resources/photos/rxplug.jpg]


Put the TX flat on the table. Turn it on (gently!) using the power switch.

The blue LED should start breathing, as the laser sensor gets a baseline distance reading.

Daytripper is triggered when further readings deviate too much from this initial baseline.

The blue LED should eventually go out, that means TX is armed and ready. 

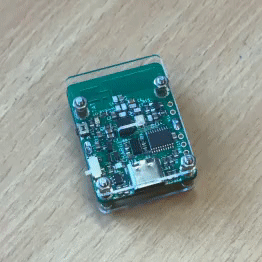
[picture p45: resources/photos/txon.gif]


Now put your hand in front of the sensor window, all your windows should be instantly minimized.



That's pretty much the gist of it! However please do keep reading for more important information.

## Mounting options

Now you know how Daytripper works, time to mount it at a desired location.

If you're trying to detect someone walking by, you can mount it to a wall using the included magnet.

* Simply tape the magnet to the wall, then you can attach and detach the TX with ease.

If you can find a metal surface, it's even easier:



To detect a door opening, simply put it on the ground so the door opens into it.

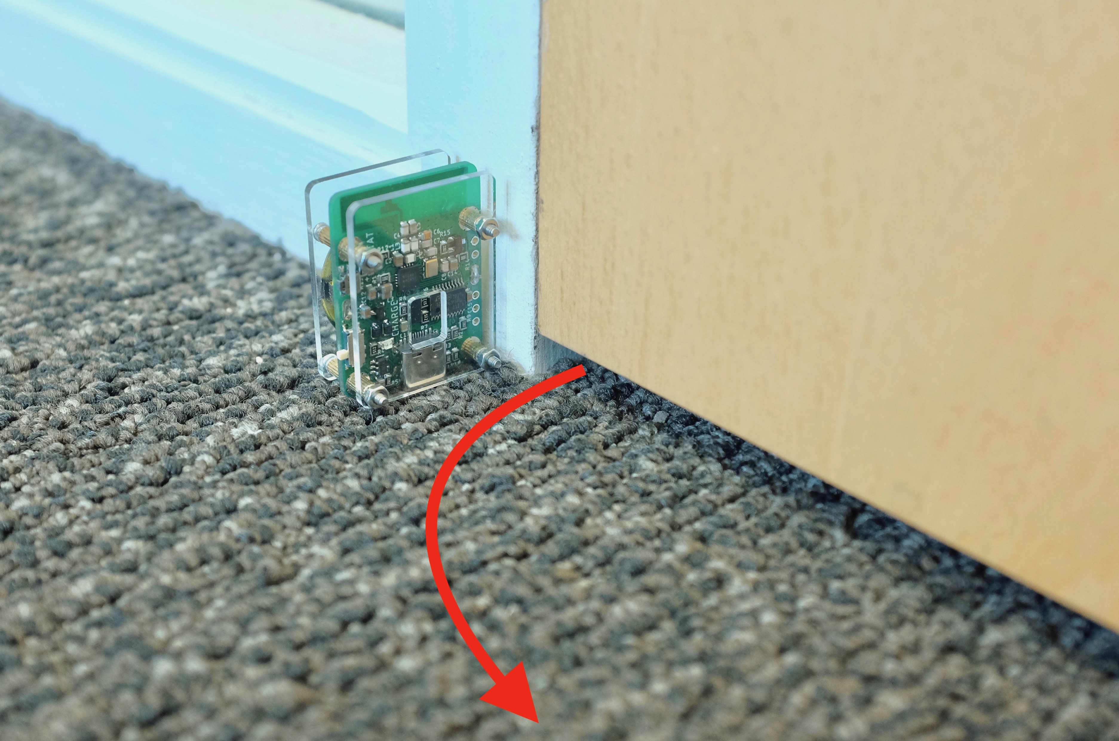
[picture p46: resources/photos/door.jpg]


Those are just two suggestions, you can get as creative as you want!

## Test It Out!

It is very important that you **`TEST YOUR SETUP THOROUGHLY BEFORE USING IT FOR REAL!`**

A couple of key areas to note:

### Mounting Location

* Make sure the location provide adequate coverage for potential threats.

* You can conceal the TX if you want, just leave the sensor window clear, and don't touch the components on the circuit board.

### Power-On Order

* Always turn on the TX **`AFTER`** you finish mounting it, so the initial calibration won't get messed up by your hand.

### Motion Sensitivity

* Approach the TX like your potential threats would, does TX trigger consistently?

* If yes, congrats! You're all set.

* If not, you can turn up the refresh rate to make TX more sensitive to motion, at the cost of battery life.

* You can also leave TX plugged in at all times, in which case it will operate at the fastest refresh rate.

* To see how, **`finish reading this guide first`**, then head to the [Advanced Usage Guide](/advanced_usage.md).

### Your Applications

* Try it out with the application you're trying to hide!

* By default, RX will press `WIN + M` when triggered. This works with almost all desktop apps.

* However, it might not work with certain fullscreen games.

* If so, try switching your game to `borderless fullscreen` in graphic settings, if available.

* If all else fails, move the `Mode Select` switch to `LOCK` so RX will lock your computer instead.



* There is also a `Custom` option for executing custom commands, but that's for [advanced usages](/advanced_usage.md).

## Good to Know

Daytripper works by monitoring distance changes with an eye-safe laser sensor. As a result, there are some important information to keep in mind: 

* The laser works between 2cm to 120cm (0.8 to 47 inches), so make sure the motion happens within this range. 

* Daytripper works best in indoor conditions. Harsh ambient lighting such as direct sunlight might overwhelm the laser and affect detection range and sensitivity. 

* By default, the laser sensor scans at 6 times per second (Hz) while on battery power. It is automatically increased to 30Hz (fastest) when powered by USB.

* You can adjust a number of advanced parameters to suit your particular needs. Please see [this guide](/advanced_usage.md) for details.

* The transmission range between TX and RX is around 100 meters (330 feet) in open air. Although it is likely to be shorter in indoor environments with walls and other wireless interferences.

* The battery on TX should last around 50 hours with default configuration. You can recharge it using a USB Type-C cable.

* Don't touch the components on the circuit board with your bare hands, especially the laser sensor!

* Daytripper is most sensitive if the laser can be bounced straight back from the subject instead of at an angle.

* Certain materials might absorb the laser instead of reflecting it back, affecting performance. Those materials tends to be very deep black in color with a soft texture. 

## Troubleshooting

Both TX and RX have a blue status LED. The meanings are detailed in tables below. 

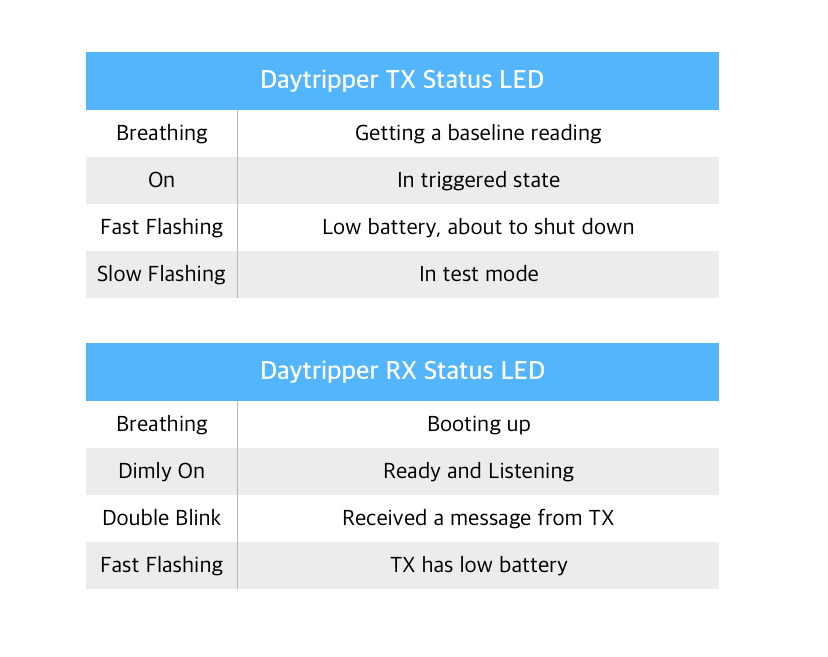
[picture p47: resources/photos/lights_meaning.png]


TX boards also have a yellow LED, which comes on when the battery is charging.

## Advanced Usages

Once you're familiar with how Daytripper works, you can take a look at the [Advanced Usage Guide](/advanced_usage.md) for some additional features that might be of interest.

## Disclaimers

Although I have spent a lot of time on this project, I cannot guarantee its functionality in every condition.

This is not a safety device, do not use it for safety critical situations. 

I am not responsible for the consequences of using this device. Use it at your own risk. 

## Questions or Comments?

Please feel free to [open an issue](https://github.com/dekuNukem/duckypad/issues), ask in the [official Daytripper discord](https://discord.gg/VM4kbnf), DM me on discord `dekuNukem#6998`, or email `dekuNukem`@`gmail`.`com` for inquires.

------

[Main Page](/README.md) | [Buy Daytripper](https://www.tindie.com/products/dekuNukem/daytripper)

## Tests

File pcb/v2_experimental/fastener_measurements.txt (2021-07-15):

ALL FASTENERS ARE SIZE M2
listed from top to bottom

regular battery (LIR2450):

10mm flathead screw
4mm standoff
6mm standoff
2.8mm screw

big battery (LIR2477):
10mm flathead screw
4mm standoff
9mm standoff
2.8mm screw

if using pilers, make sure don't touch the positive battery terminal!

VL53L1X sensor, protective film peel opening face left! (towards power switch)

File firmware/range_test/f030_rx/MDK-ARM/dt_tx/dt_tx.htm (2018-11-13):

# Static Call Graph for image dt_tx\dt_tx.axf

#<CALLGRAPH># ARM Linker, 5060750: Last Updated: Thu Nov 08 18:05:31 2018

### Maximum Stack Usage = 196 bytes + Unknown(Cycles, Untraceable Function Pointers)

### Call chain for Maximum Stack Depth:

main ⇒ SystemClock_Config ⇒ HAL_RCC_ClockConfig ⇒ HAL_RCC_GetSysClockFreq ⇒ __aeabi_uidivmod

### Mutually Recursive functions

- ADC1_IRQHandler ⇒ ADC1_IRQHandler
- HardFault_Handler ⇒ HardFault_Handler

### Function Pointers

- ADC1_IRQHandler from startup_stm32f030x6.o(.text) referenced from startup_stm32f030x6.o(RESET)
- DMA1_Channel1_IRQHandler from startup_stm32f030x6.o(.text) referenced from startup_stm32f030x6.o(RESET)
- DMA1_Channel2_3_IRQHandler from startup_stm32f030x6.o(.text) referenced from startup_stm32f030x6.o(RESET)
- DMA1_Channel4_5_IRQHandler from startup_stm32f030x6.o(.text) referenced from startup_stm32f030x6.o(RESET)
- EXTI0_1_IRQHandler from startup_stm32f030x6.o(.text) referenced from startup_stm32f030x6.o(RESET)
- EXTI2_3_IRQHandler from startup_stm32f030x6.o(.text) referenced from startup_stm32f030x6.o(RESET)
- EXTI4_15_IRQHandler from startup_stm32f030x6.o(.text) referenced from startup_stm32f030x6.o(RESET)
- FLASH_IRQHandler from startup_stm32f030x6.o(.text) referenced from startup_stm32f030x6.o(RESET)
- HardFault_Handler from stm32f0xx_it.o(i.HardFault_Handler) referenced from startup_stm32f030x6.o(RESET)
- I2C1_IRQHandler from startup_stm32f030x6.o(.text) referenced from startup_stm32f030x6.o(RESET)
- NMI_Handler from stm32f0xx_it.o(i.NMI_Handler) referenced from startup_stm32f030x6.o(RESET)
- PendSV_Handler from stm32f0xx_it.o(i.PendSV_Handler) referenced from startup_stm32f030x6.o(RESET)
- RCC_IRQHandler from startup_stm32f030x6.o(.text) referenced from startup_stm32f030x6.o(RESET)
- RTC_IRQHandler from startup_stm32f030x6.o(.text) referenced from startup_stm32f030x6.o(RESET)
- Reset_Handler from startup_stm32f030x6.o(.text) referenced from startup_stm32f030x6.o(RESET)
- SPI1_IRQHandler from startup_stm32f030x6.o(.text) referenced from startup_stm32f030x6.o(RESET)
- SVC_Handler from stm32f0xx_it.o(i.SVC_Handler) referenced from startup_stm32f030x6.o(RESET)
- SysTick_Handler from stm32f0xx_it.o(i.SysTick_Handler) referenced from startup_stm32f030x6.o(RESET)
- SystemInit from system_stm32f0xx.o(i.SystemInit) referenced from startup_stm32f030x6.o(.text)
- TIM14_IRQHandler from startup_stm32f030x6.o(.text) referenced from startup_stm32f030x6.o(RESET)
- TIM16_IRQHandler from startup_stm32f030x6.o(.text) referenced from startup_stm32f030x6.o(RESET)
- TIM17_IRQHandler from startup_stm32f030x6.o(.text) referenced from startup_stm32f030x6.o(RESET)
- TIM1_BRK_UP_TRG_COM_IRQHandler from startup_stm32f030x6.o(.text) referenced from startup_stm32f030x6.o(RESET)
- TIM1_CC_IRQHandler from startup_stm32f030x6.o(.text) referenced from startup_stm32f030x6.o(RESET)
- TIM3_IRQHandler from startup_stm32f030x6.o(.text) referenced from startup_stm32f030x6.o(RESET)
- USART1_IRQHandler from startup_stm32f030x6.o(.text) referenced from startup_stm32f030x6.o(RESET)
- WWDG_IRQHandler from startup_stm32f030x6.o(.text) referenced from startup_stm32f030x6.o(RESET)
- __main from entry.o(.ARM.Collect$$$$00000000) referenced from startup_stm32f030x6.o(.text)
- fputc from main.o(i.fputc) referenced from printf8.o(i.__0printf$8)
- main from main.o(i.main) referenced from entry9a.o(.ARM.Collect$$$$0000000B)

### Global Symbols

__main (Thumb, 0 bytes, Stack size unknown bytes, entry.o(.ARM.Collect$$$$00000000))
[Address Reference Count : 1]

- startup_stm32f030x6.o(.text)

_main_stk (Thumb, 0 bytes, Stack size unknown bytes, entry2.o(.ARM.Collect$$$$00000001))

_main_scatterload (Thumb, 0 bytes, Stack size unknown bytes, entry5.o(.ARM.Collect$$$$00000004))

[Calls]

- >> __scatterload

__main_after_scatterload (Thumb, 0 bytes, Stack size unknown bytes, entry5.o(.ARM.Collect$$$$00000004))

[Called By]

- >> __scatterload

_main_clock (Thumb, 0 bytes, Stack size unknown bytes, entry7b.o(.ARM.Collect$$$$00000008))

_main_cpp_init (Thumb, 0 bytes, Stack size unknown bytes, entry8b.o(.ARM.Collect$$$$0000000A))

_main_init (Thumb, 0 bytes, Stack size unknown bytes, entry9a.o(.ARM.Collect$$$$0000000B))

__rt_final_cpp (Thumb, 0 bytes, Stack size unknown bytes, entry10a.o(.ARM.Collect$$$$0000000D))

__rt_final_exit (Thumb, 0 bytes, Stack size unknown bytes, entry11a.o(.ARM.Collect$$$$0000000F))

Reset_Handler (Thumb, 8 bytes, Stack size 0 bytes, startup_stm32f030x6.o(.text))
[Address Reference Count : 1]

- startup_stm32f030x6.o(RESET)

ADC1_IRQHandler (Thumb, 0 bytes, Stack size 0 bytes, startup_stm32f030x6.o(.text))

[Calls]

- >> ADC1_IRQHandler

[Called By]

- >> ADC1_IRQHandler

[Address Reference Count : 1]

- startup_stm32f030x6.o(RESET)

DMA1_Channel1_IRQHandler (Thumb, 0 bytes, Stack size 0 bytes, startup_stm32f030x6.o(.text))
[Address Reference Count : 1]

- startup_stm32f030x6.o(RESET)

DMA1_Channel2_3_IRQHandler (Thumb, 0 bytes, Stack size 0 bytes, startup_stm32f030x6.o(.text))
[Address Reference Count : 1]

- startup_stm32f030x6.o(RESET)

DMA1_Channel4_5_IRQHandler (Thumb, 0 bytes, Stack size 0 bytes, startup_stm32f030x6.o(.text))
[Address Reference Count : 1]

- startup_stm32f030x6.o(RESET)

EXTI0_1_IRQHandler (Thumb, 0 bytes, Stack size 0 bytes, startup_stm32f030x6.o(.text))
[Address Reference Count : 1]

- startup_stm32f030x6.o(RESET)

EXTI2_3_IRQHandler (Thumb, 0 bytes, Stack size 0 bytes, startup_stm32f030x6.o(.text))
[Address Reference Count : 1]

- startup_stm32f030x6.o(RESET)

EXTI4_15_IRQHandler (Thumb, 0 bytes, Stack size 0 bytes, startup_stm32f030x6.o(.text))
[Address Reference Count : 1]

- startup_stm32f030x6.o(RESET)

FLASH_IRQHandler (Thumb, 0 bytes, Stack size 0 bytes, startup_stm32f030x6.o(.text))
[Address Reference Count : 1]

- startup_stm32f030x6.o(RESET)

I2C1_IRQHandler (Thumb, 0 bytes, Stack size 0 bytes, startup_stm32f030x6.o(.text))
[Address Reference Count : 1]

- startup_stm32f030x6.o(RESET)

RCC_IRQHandler (Thumb, 0 bytes, Stack size 0 bytes, startup_stm32f030x6.o(.text))
[Address Reference Count : 1]

- startup_stm32f030x6.o(RESET)

RTC_IRQHandler (Thumb, 0 bytes, Stack size 0 bytes, startup_stm32f030x6.o(.text))
[Address Reference Count : 1]

- startup_stm32f030x6.o(RESET)

SPI1_IRQHandler (Thumb, 0 bytes, Stack size 0 bytes, startup_stm32f030x6.o(.text))
[Address Reference Count : 1]

- startup_stm32f030x6.o(RESET)

TIM14_IRQHandler (Thumb, 0 bytes, Stack size 0 bytes, startup_stm32f030x6.o(.text))
[Address Reference Count : 1]

- startup_stm32f030x6.o(RESET)

TIM16_IRQHandler (Thumb, 0 bytes, Stack size 0 bytes, startup_stm32f030x6.o(.text))
[Address Reference Count : 1]

- startup_stm32f030x6.o(RESET)

TIM17_IRQHandler (Thumb, 0 bytes, Stack size 0 bytes, startup_stm32f030x6.o(.text))
[Address Reference Count : 1]

- startup_stm32f030x6.o(RESET)

TIM1_BRK_UP_TRG_COM_IRQHandler (Thumb, 0 bytes, Stack size 0 bytes, startup_stm32f030x6.o(.text))
[Address Reference Count : 1]

- startup_stm32f030x6.o(RESET)

TIM1_CC_IRQHandler (Thumb, 0 bytes, Stack size 0 bytes, startup_stm32f030x6.o(.text))
[Address Reference Count : 1]

- startup_stm32f030x6.o(RESET)

TIM3_IRQHandler (Thumb, 0 bytes, Stack size 0 bytes, startup_stm32f030x6.o(.text))
[Address Reference Count : 1]

- startup_stm32f030x6.o(RESET)

USART1_IRQHandler (Thumb, 0 bytes, Stack size 0 bytes, startup_stm32f030x6.o(.text))
[Address Reference Count : 1]

- startup_stm32f030x6.o(RESET)

WWDG_IRQHandler (Thumb, 0 bytes, Stack size 0 bytes, startup_stm32f030x6.o(.text))
[Address Reference Count : 1]

- startup_stm32f030x6.o(RESET)

__aeabi_uidiv (Thumb, 0 bytes, Stack size 12 bytes, uidiv.o(.text), UNUSED)

__aeabi_uidivmod (Thumb, 44 bytes, Stack size 12 bytes, uidiv.o(.text))

[Stack]

- Max Depth = 12
- Call Chain = __aeabi_uidivmod

[Called By]

- >> SystemClock_Config
- >> HAL_InitTick
- >> HAL_RCC_GetSysClockFreq
- >> UART_SetConfig

__aeabi_llsr (Thumb, 34 bytes, Stack size 8 bytes, llushr.o(.text), UNUSED)

[Called By]

- >> __aeabi_uldivmod

_ll_ushift_r (Thumb, 0 bytes, Stack size 8 bytes, llushr.o(.text), UNUSED)

__aeabi_uldivmod (Thumb, 96 bytes, Stack size 48 bytes, uldiv.o(.text), UNUSED)

[Calls]

- >> __aeabi_llsl
- >> __aeabi_llsr

[Called By]

- >> _printf_core

__scatterload (Thumb, 28 bytes, Stack size 0 bytes, init.o(.text))

[Calls]

- >> __main_after_scatterload

[Called By]

- >> _main_scatterload

__scatterload_rt2 (Thumb, 0 bytes, Stack size 0 bytes, init.o(.text), UNUSED)

__aeabi_llsl (Thumb, 32 bytes, Stack size 8 bytes, llshl.o(.text), UNUSED)

[Called By]

- >> __aeabi_uldivmod

_ll_shift_l (Thumb, 0 bytes, Stack size 8 bytes, llshl.o(.text), UNUSED)

HAL_GPIO_Init (Thumb, 302 bytes, Stack size 24 bytes, stm32f0xx_hal_gpio.o(i.HAL_GPIO_Init))

[Stack]

- Max Depth = 24
- Call Chain = HAL_GPIO_Init

[Called By]

- >> HAL_UART_MspInit
- >> HAL_SPI_MspInit
- >> HAL_I2C_MspInit
- >> main

HAL_GPIO_WritePin (Thumb, 12 bytes, Stack size 0 bytes, stm32f0xx_hal_gpio.o(i.HAL_GPIO_WritePin))

[Called By]

- >> main
- >> nrf24_csn_digitalWrite
- >> nrf24_ce_digitalWrite

HAL_GetTick (Thumb, 6 bytes, Stack size 0 bytes, stm32f0xx_hal.o(i.HAL_GetTick))

[Called By]

- >> HAL_UART_Transmit
- >> HAL_RCC_OscConfig
- >> HAL_RCC_ClockConfig
- >> HAL_RCCEx_PeriphCLKConfig
- >> HAL_SPI_TransmitReceive
- >> SPI_WaitFlagStateUntilTimeout
- >> SPI_WaitFifoStateUntilTimeout
- >> UART_WaitOnFlagUntilTimeout

HAL_I2CEx_ConfigAnalogFilter (Thumb, 74 bytes, Stack size 16 bytes, stm32f0xx_hal_i2c_ex.o(i.HAL_I2CEx_ConfigAnalogFilter))

[Stack]

- Max Depth = 16
- Call Chain = HAL_I2CEx_ConfigAnalogFilter

[Called By]

- >> MX_I2C1_Init

HAL_I2CEx_ConfigDigitalFilter (Thumb, 72 bytes, Stack size 16 bytes, stm32f0xx_hal_i2c_ex.o(i.HAL_I2CEx_ConfigDigitalFilter))

[Stack]

- Max Depth = 16
- Call Chain = HAL_I2CEx_ConfigDigitalFilter

[Called By]

- >> MX_I2C1_Init

HAL_I2C_Init (Thumb, 176 bytes, Stack size 16 bytes, stm32f0xx_hal_i2c.o(i.HAL_I2C_Init))

[Stack]

- Max Depth = 72
- Call Chain = HAL_I2C_Init ⇒ HAL_I2C_MspInit ⇒ HAL_GPIO_Init

[Calls]

- >> HAL_I2C_MspInit

[Called By]

- >> MX_I2C1_Init

HAL_I2C_MspInit (Thumb, 66 bytes, Stack size 32 bytes, stm32f0xx_hal_msp.o(i.HAL_I2C_MspInit))

[Stack]

- Max Depth = 56
- Call Chain = HAL_I2C_MspInit ⇒ HAL_GPIO_Init

[Calls]

- >> HAL_GPIO_Init

[Called By]

- >> HAL_I2C_Init

HAL_IncTick (Thumb, 10 bytes, Stack size 0 bytes, stm32f0xx_hal.o(i.HAL_IncTick))

[Called By]

- >> SysTick_Handler

HAL_Init (Thumb, 26 bytes, Stack size 8 bytes, stm32f0xx_hal.o(i.HAL_Init))

[Stack]

- Max Depth = 28
- Call Chain = HAL_Init ⇒ HAL_InitTick ⇒ __aeabi_uidivmod

[Calls]

- >> HAL_MspInit
- >> HAL_InitTick

[Called By]

- >> main

HAL_InitTick (Thumb, 34 bytes, Stack size 8 bytes, stm32f0xx_hal.o(i.HAL_InitTick))

[Stack]

- Max Depth = 20
- Call Chain = HAL_InitTick ⇒ __aeabi_uidivmod

[Calls]

- >> HAL_SYSTICK_Config
- >> HAL_RCC_GetHCLKFreq
- >> HAL_NVIC_SetPriority
- >> __aeabi_uidivmod

[Called By]

- >> HAL_RCC_ClockConfig
- >> HAL_Init

HAL_MspInit (Thumb, 64 bytes, Stack size 8 bytes, stm32f0xx_hal_msp.o(i.HAL_MspInit))

[Stack]

- Max Depth = 16
- Call Chain = HAL_MspInit ⇒ HAL_NVIC_SetPriority

[Calls]

- >> HAL_NVIC_SetPriority

[Called By]

- >> HAL_Init

HAL_NVIC_SetPriority (Thumb, 8 bytes, Stack size 8 bytes, stm32f0xx_hal_cortex.o(i.HAL_NVIC_SetPriority))

[Stack]

- Max Depth = 8
- Call Chain = HAL_NVIC_SetPriority

[Calls]

- >> NVIC_SetPriority

[Called By]

- >> HAL_MspInit
- >> SystemClock_Config
- >> HAL_InitTick

HAL_RCCEx_PeriphCLKConfig (Thumb, 218 bytes, Stack size 24 bytes, stm32f0xx_hal_rcc_ex.o(i.HAL_RCCEx_PeriphCLKConfig))

[Stack]

- Max Depth = 24
- Call Chain = HAL_RCCEx_PeriphCLKConfig

[Calls]

- >> HAL_GetTick

[Called By]

- >> SystemClock_Config

HAL_RCC_ClockConfig (Thumb, 280 bytes, Stack size 24 bytes, stm32f0xx_hal_rcc.o(i.HAL_RCC_ClockConfig))

[Stack]

- Max Depth = 76
- Call Chain = HAL_RCC_ClockConfig ⇒ HAL_RCC_GetSysClockFreq ⇒ __aeabi_uidivmod

[Calls]

- >> HAL_GetTick
- >> HAL_InitTick
- >> HAL_RCC_GetSysClockFreq

[Called By]

- >> SystemClock_Config

HAL_RCC_GetHCLKFreq (Thumb, 6 bytes, Stack size 0 bytes, stm32f0xx_hal_rcc.o(i.HAL_RCC_GetHCLKFreq))

[Called By]

- >> SystemClock_Config
- >> HAL_InitTick

HAL_RCC_GetPCLK1Freq (Thumb, 20 bytes, Stack size 0 bytes, stm32f0xx_hal_rcc.o(i.HAL_RCC_GetPCLK1Freq))

[Called By]

- >> UART_SetConfig

HAL_RCC_GetSysClockFreq (Thumb, 76 bytes, Stack size 40 bytes, stm32f0xx_hal_rcc.o(i.HAL_RCC_GetSysClockFreq))

[Stack]

- Max Depth = 52
- Call Chain = HAL_RCC_GetSysClockFreq ⇒ __aeabi_uidivmod

[Calls]

- >> __aeabi_uidivmod

[Called By]

- >> HAL_RCC_ClockConfig
- >> UART_SetConfig

HAL_RCC_OscConfig (Thumb, 840 bytes, Stack size 32 bytes, stm32f0xx_hal_rcc.o(i.HAL_RCC_OscConfig))

[Stack]

- Max Depth = 32
- Call Chain = HAL_RCC_OscConfig

[Calls]

- >> HAL_GetTick

[Called By]

- >> SystemClock_Config

HAL_SPI_Init (Thumb, 184 bytes, Stack size 24 bytes, stm32f0xx_hal_spi.o(i.HAL_SPI_Init))

[Stack]

- Max Depth = 80
- Call Chain = HAL_SPI_Init ⇒ HAL_SPI_MspInit ⇒ HAL_GPIO_Init

[Calls]

- >> HAL_SPI_MspInit

[Called By]

- >> MX_SPI1_Init

HAL_SPI_MspInit (Thumb, 60 bytes, Stack size 32 bytes, stm32f0xx_hal_msp.o(i.HAL_SPI_MspInit))

[Stack]

- Max Depth = 56
- Call Chain = HAL_SPI_MspInit ⇒ HAL_GPIO_Init

[Calls]

- >> HAL_GPIO_Init

[Called By]

- >> HAL_SPI_Init

HAL_SPI_TransmitReceive (Thumb, 584 bytes, Stack size 48 bytes, stm32f0xx_hal_spi.o(i.HAL_SPI_TransmitReceive))

[Stack]

- Max Depth = 96
- Call Chain = HAL_SPI_TransmitReceive ⇒ SPI_EndRxTxTransaction ⇒ SPI_WaitFlagStateUntilTimeout

[Calls]

- >> SPI_EndRxTxTransaction
- >> HAL_GetTick

[Called By]

- >> spi_transfer

HAL_SYSTICK_CLKSourceConfig (Thumb, 20 bytes, Stack size 0 bytes, stm32f0xx_hal_cortex.o(i.HAL_SYSTICK_CLKSourceConfig))

[Called By]

- >> SystemClock_Config

HAL_SYSTICK_Callback (Thumb, 2 bytes, Stack size 0 bytes, stm32f0xx_hal_cortex.o(i.HAL_SYSTICK_Callback))

[Called By]

- >> HAL_SYSTICK_IRQHandler

HAL_SYSTICK_Config (Thumb, 38 bytes, Stack size 8 bytes, stm32f0xx_hal_cortex.o(i.HAL_SYSTICK_Config))

[Stack]

- Max Depth = 8
- Call Chain = HAL_SYSTICK_Config

[Calls]

- >> NVIC_SetPriority

[Called By]

- >> SystemClock_Config
- >> HAL_InitTick

HAL_SYSTICK_IRQHandler (Thumb, 8 bytes, Stack size 8 bytes, stm32f0xx_hal_cortex.o(i.HAL_SYSTICK_IRQHandler))

[Stack]

- Max Depth = 8
- Call Chain = HAL_SYSTICK_IRQHandler

[Calls]

- >> HAL_SYSTICK_Callback

[Called By]

- >> SysTick_Handler

HAL_UART_Init (Thumb, 108 bytes, Stack size 16 bytes, stm32f0xx_hal_uart.o(i.HAL_UART_Init))

[Stack]

- Max Depth = 92
- Call Chain = HAL_UART_Init ⇒ UART_SetConfig ⇒ HAL_RCC_GetSysClockFreq ⇒ __aeabi_uidivmod

[Calls]

- >> HAL_UART_MspInit
- >> UART_SetConfig
- >> UART_CheckIdleState
- >> UART_AdvFeatureConfig

[Called By]

- >> MX_USART1_UART_Init

HAL_UART_MspInit (Thumb, 64 bytes, Stack size 32 bytes, stm32f0xx_hal_msp.o(i.HAL_UART_MspInit))

[Stack]

- Max Depth = 56
- Call Chain = HAL_UART_MspInit ⇒ HAL_GPIO_Init

[Calls]

- >> HAL_GPIO_Init

[Called By]

- >> HAL_UART_Init

HAL_UART_Transmit (Thumb, 200 bytes, Stack size 48 bytes, stm32f0xx_hal_uart.o(i.HAL_UART_Transmit))

[Stack]

- Max Depth = 88
- Call Chain = HAL_UART_Transmit ⇒ UART_WaitOnFlagUntilTimeout

[Calls]

- >> HAL_GetTick
- >> UART_WaitOnFlagUntilTimeout

[Called By]

- >> fputc

HardFault_Handler (Thumb, 2 bytes, Stack size 0 bytes, stm32f0xx_it.o(i.HardFault_Handler))

[Calls]

- >> HardFault_Handler

[Called By]

- >> HardFault_Handler

[Address Reference Count : 1]

- startup_stm32f030x6.o(RESET)

NMI_Handler (Thumb, 2 bytes, Stack size 0 bytes, stm32f0xx_it.o(i.NMI_Handler))
[Address Reference Count : 1]

- startup_stm32f030x6.o(RESET)

PendSV_Handler (Thumb, 2 bytes, Stack size 0 bytes, stm32f0xx_it.o(i.PendSV_Handler))
[Address Reference Count : 1]

- startup_stm32f030x6.o(RESET)

SVC_Handler (Thumb, 2 bytes, Stack size 0 bytes, stm32f0xx_it.o(i.SVC_Handler))
[Address Reference Count : 1]

- startup_stm32f030x6.o(RESET)

SysTick_Handler (Thumb, 12 bytes, Stack size 8 bytes, stm32f0xx_it.o(i.SysTick_Handler))

[Stack]

- Max Depth = 16
- Call Chain = SysTick_Handler ⇒ HAL_SYSTICK_IRQHandler

[Calls]

- >> HAL_SYSTICK_IRQHandler
- >> HAL_IncTick

[Address Reference Count : 1]

- startup_stm32f030x6.o(RESET)

SystemClock_Config (Thumb, 122 bytes, Stack size 96 bytes, main.o(i.SystemClock_Config))

[Stack]

- Max Depth = 172
- Call Chain = SystemClock_Config ⇒ HAL_RCC_ClockConfig ⇒ HAL_RCC_GetSysClockFreq ⇒ __aeabi_uidivmod

[Calls]

- >> HAL_SYSTICK_Config
- >> HAL_SYSTICK_CLKSourceConfig
- >> HAL_RCC_OscConfig
- >> HAL_RCC_GetHCLKFreq
- >> HAL_RCC_ClockConfig
- >> HAL_RCCEx_PeriphCLKConfig
- >> HAL_NVIC_SetPriority
- >> __aeabi_uidivmod

[Called By]

- >> main

SystemInit (Thumb, 78 bytes, Stack size 0 bytes, system_stm32f0xx.o(i.SystemInit))
[Address Reference Count : 1]

- startup_stm32f030x6.o(.text)

UART_AdvFeatureConfig (Thumb, 202 bytes, Stack size 8 bytes, stm32f0xx_hal_uart.o(i.UART_AdvFeatureConfig))

[Stack]

- Max Depth = 8
- Call Chain = UART_AdvFeatureConfig

[Called By]

- >> HAL_UART_Init

UART_CheckIdleState (Thumb, 18 bytes, Stack size 0 bytes, stm32f0xx_hal_uart.o(i.UART_CheckIdleState))

[Called By]

- >> HAL_UART_Init

UART_SetConfig (Thumb, 258 bytes, Stack size 24 bytes, stm32f0xx_hal_uart.o(i.UART_SetConfig))

[Stack]

- Max Depth = 76
- Call Chain = UART_SetConfig ⇒ HAL_RCC_GetSysClockFreq ⇒ __aeabi_uidivmod

[Calls]

- >> HAL_RCC_GetSysClockFreq
- >> HAL_RCC_GetPCLK1Freq
- >> __aeabi_uidivmod

[Called By]

- >> HAL_UART_Init

UART_WaitOnFlagUntilTimeout (Thumb, 98 bytes, Stack size 40 bytes, stm32f0xx_hal_uart.o(i.UART_WaitOnFlagUntilTimeout))

[Stack]

- Max Depth = 40
- Call Chain = UART_WaitOnFlagUntilTimeout

[Calls]

- >> HAL_GetTick

[Called By]

- >> HAL_UART_Transmit

__0printf$8 (Thumb, 24 bytes, Stack size 24 bytes, printf8.o(i.__0printf$8), UNUSED)

[Calls]

- >> _printf_core

__1printf$8 (Thumb, 0 bytes, Stack size 24 bytes, printf8.o(i.__0printf$8), UNUSED)

__2printf (Thumb, 0 bytes, Stack size 24 bytes, printf8.o(i.__0printf$8))

[Stack]

- Max Depth = 24
- Call Chain = __2printf

[Called By]

- >> main

__scatterload_copy (Thumb, 14 bytes, Stack size unknown bytes, handlers.o(i.__scatterload_copy), UNUSED)

__scatterload_null (Thumb, 2 bytes, Stack size unknown bytes, handlers.o(i.__scatterload_null), UNUSED)

__scatterload_zeroinit (Thumb, 14 bytes, Stack size unknown bytes, handlers.o(i.__scatterload_zeroinit), UNUSED)

fputc (Thumb, 18 bytes, Stack size 16 bytes, main.o(i.fputc))

[Stack]

- Max Depth = 104
- Call Chain = fputc ⇒ HAL_UART_Transmit ⇒ UART_WaitOnFlagUntilTimeout

[Calls]

- >> HAL_UART_Transmit

[Address Reference Count : 1]

- printf8.o(i.__0printf$8)

main (Thumb, 178 bytes, Stack size 24 bytes, main.o(i.main))

[Stack]

- Max Depth = 196
- Call Chain = main ⇒ SystemClock_Config ⇒ HAL_RCC_ClockConfig ⇒ HAL_RCC_GetSysClockFreq ⇒ __aeabi_uidivmod

[Calls]

- >> HAL_Init
- >> HAL_GPIO_Init
- >> SystemClock_Config
- >> MX_USART1_UART_Init
- >> MX_SPI1_Init
- >> MX_I2C1_Init
- >> HAL_GPIO_WritePin
- >> nrf24_tx_address
- >> nrf24_rx_address
- >> nrf24_init
- >> nrf24_getData
- >> nrf24_dataReady
- >> nrf24_config
- >> __2printf

[Address Reference Count : 1]

- entry9a.o(.ARM.Collect$$$$0000000B)

nrf24_ce_digitalWrite (Thumb, 26 bytes, Stack size 8 bytes, radiopinfunctions.o(i.nrf24_ce_digitalWrite))

[Stack]

- Max Depth = 8
- Call Chain = nrf24_ce_digitalWrite

[Calls]

- >> HAL_GPIO_WritePin

[Called By]

- >> nrf24_rx_address
- >> nrf24_powerUpRx
- >> nrf24_init

nrf24_config (Thumb, 116 bytes, Stack size 8 bytes, nrf24.o(i.nrf24_config))

[Stack]

- Max Depth = 144
- Call Chain = nrf24_config ⇒ nrf24_powerUpRx ⇒ nrf24_configRegister ⇒ spi_transfer ⇒ HAL_SPI_TransmitReceive ⇒ SPI_EndRxTxTransaction ⇒ SPI_WaitFlagStateUntilTimeout

[Calls]

- >> nrf24_powerUpRx
- >> nrf24_configRegister

[Called By]

- >> main

nrf24_configRegister (Thumb, 36 bytes, Stack size 16 bytes, nrf24.o(i.nrf24_configRegister))

[Stack]

- Max Depth = 128
- Call Chain = nrf24_configRegister ⇒ spi_transfer ⇒ HAL_SPI_TransmitReceive ⇒ SPI_EndRxTxTransaction ⇒ SPI_WaitFlagStateUntilTimeout

[Calls]

- >> nrf24_csn_digitalWrite
- >> spi_transfer

[Called By]

- >> nrf24_powerUpRx
- >> nrf24_getData
- >> nrf24_config

nrf24_csn_digitalWrite (Thumb, 26 bytes, Stack size 8 bytes, radiopinfunctions.o(i.nrf24_csn_digitalWrite))

[Stack]

- Max Depth = 8
- Call Chain = nrf24_csn_digitalWrite

[Calls]

- >> HAL_GPIO_WritePin

[Called By]

- >> nrf24_writeRegister
- >> nrf24_readRegister
- >> nrf24_powerUpRx
- >> nrf24_init
- >> nrf24_getStatus
- >> nrf24_getData
- >> nrf24_configRegister

nrf24_dataReady (Thumb, 26 bytes, Stack size 8 bytes, nrf24.o(i.nrf24_dataReady))

[Stack]

- Max Depth = 168
- Call Chain = nrf24_dataReady ⇒ nrf24_rxFifoEmpty ⇒ nrf24_readRegister ⇒ nrf24_transferSync ⇒ spi_transfer ⇒ HAL_SPI_TransmitReceive ⇒ SPI_EndRxTxTransaction ⇒ SPI_WaitFlagStateUntilTimeout

[Calls]

- >> nrf24_rxFifoEmpty
- >> nrf24_getStatus

[Called By]

- >> main

nrf24_getData (Thumb, 44 bytes, Stack size 8 bytes, nrf24.o(i.nrf24_getData))

[Stack]

- Max Depth = 144
- Call Chain = nrf24_getData ⇒ nrf24_transferSync ⇒ spi_transfer ⇒ HAL_SPI_TransmitReceive ⇒ SPI_EndRxTxTransaction ⇒ SPI_WaitFlagStateUntilTimeout

[Calls]

- >> nrf24_csn_digitalWrite
- >> spi_transfer
- >> nrf24_transferSync
- >> nrf24_configRegister

[Called By]

- >> main

nrf24_getStatus (Thumb, 26 bytes, Stack size 8 bytes, nrf24.o(i.nrf24_getStatus))

[Stack]

- Max Depth = 120
- Call Chain = nrf24_getStatus ⇒ spi_transfer ⇒ HAL_SPI_TransmitReceive ⇒ SPI_EndRxTxTransaction ⇒ SPI_WaitFlagStateUntilTimeout

[Calls]

- >> nrf24_csn_digitalWrite
- >> spi_transfer

[Called By]

- >> nrf24_dataReady

nrf24_init (Thumb, 16 bytes, Stack size 8 bytes, nrf24.o(i.nrf24_init))

[Stack]

- Max Depth = 16
- Call Chain = nrf24_init ⇒ nrf24_csn_digitalWrite

[Calls]

- >> nrf24_csn_digitalWrite
- >> nrf24_ce_digitalWrite

[Called By]

- >> main

nrf24_powerUpRx (Thumb, 50 bytes, Stack size 8 bytes, nrf24.o(i.nrf24_powerUpRx))

[Stack]

- Max Depth = 136
- Call Chain = nrf24_powerUpRx ⇒ nrf24_configRegister ⇒ spi_transfer ⇒ HAL_SPI_TransmitReceive ⇒ SPI_EndRxTxTransaction ⇒ SPI_WaitFlagStateUntilTimeout

[Calls]

- >> nrf24_csn_digitalWrite
- >> nrf24_ce_digitalWrite
- >> spi_transfer
- >> nrf24_configRegister

[Called By]

- >> nrf24_config

nrf24_readRegister (Thumb, 40 bytes, Stack size 16 bytes, nrf24.o(i.nrf24_readRegister))

[Stack]

- Max Depth = 152
- Call Chain = nrf24_readRegister ⇒ nrf24_transferSync ⇒ spi_transfer ⇒ HAL_SPI_TransmitReceive ⇒ SPI_EndRxTxTransaction ⇒ SPI_WaitFlagStateUntilTimeout

[Calls]

- >> nrf24_csn_digitalWrite
- >> spi_transfer
- >> nrf24_transferSync

[Called By]

- >> nrf24_rxFifoEmpty

nrf24_rxFifoEmpty (Thumb, 22 bytes, Stack size 8 bytes, nrf24.o(i.nrf24_rxFifoEmpty))

[Stack]

- Max Depth = 160
- Call Chain = nrf24_rxFifoEmpty ⇒ nrf24_readRegister ⇒ nrf24_transferSync ⇒ spi_transfer ⇒ HAL_SPI_TransmitReceive ⇒ SPI_EndRxTxTransaction ⇒ SPI_WaitFlagStateUntilTimeout

[Calls]

- >> nrf24_readRegister

[Called By]

- >> nrf24_dataReady

nrf24_rx_address (Thumb, 28 bytes, Stack size 8 bytes, nrf24.o(i.nrf24_rx_address))

[Stack]

- Max Depth = 152
- Call Chain = nrf24_rx_address ⇒ nrf24_writeRegister ⇒ nrf24_transmitSync ⇒ spi_transfer ⇒ HAL_SPI_TransmitReceive ⇒ SPI_EndRxTxTransaction ⇒ SPI_WaitFlagStateUntilTimeout

[Calls]

- >> nrf24_ce_digitalWrite
- >> nrf24_writeRegister

[Called By]

- >> main

nrf24_transferSync (Thumb, 30 bytes, Stack size 24 bytes, nrf24.o(i.nrf24_transferSync))

[Stack]

- Max Depth = 136
- Call Chain = nrf24_transferSync ⇒ spi_transfer ⇒ HAL_SPI_TransmitReceive ⇒ SPI_EndRxTxTransaction ⇒ SPI_WaitFlagStateUntilTimeout

[Calls]

- >> spi_transfer

[Called By]

- >> nrf24_readRegister
- >> nrf24_getData
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

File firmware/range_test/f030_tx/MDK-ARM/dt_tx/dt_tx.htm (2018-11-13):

# Static Call Graph for image dt_tx\dt_tx.axf

#<CALLGRAPH># ARM Linker, 5060750: Last Updated: Thu Nov 08 17:42:48 2018

### Maximum Stack Usage = 196 bytes + Unknown(Cycles, Untraceable Function Pointers)

### Call chain for Maximum Stack Depth:

main ⇒ SystemClock_Config ⇒ HAL_RCC_ClockConfig ⇒ HAL_RCC_GetSysClockFreq ⇒ __aeabi_uidivmod

### Mutually Recursive functions

- ADC1_IRQHandler ⇒ ADC1_IRQHandler
- HardFault_Handler ⇒ HardFault_Handler

### Function Pointers

- ADC1_IRQHandler from startup_stm32f030x6.o(.text) referenced from startup_stm32f030x6.o(RESET)
- DMA1_Channel1_IRQHandler from startup_stm32f030x6.o(.text) referenced from startup_stm32f030x6.o(RESET)
- DMA1_Channel2_3_IRQHandler from startup_stm32f030x6.o(.text) referenced from startup_stm32f030x6.o(RESET)
- DMA1_Channel4_5_IRQHandler from startup_stm32f030x6.o(.text) referenced from startup_stm32f030x6.o(RESET)
- EXTI0_1_IRQHandler from startup_stm32f030x6.o(.text) referenced from startup_stm32f030x6.o(RESET)
- EXTI2_3_IRQHandler from startup_stm32f030x6.o(.text) referenced from startup_stm32f030x6.o(RESET)
- EXTI4_15_IRQHandler from startup_stm32f030x6.o(.text) referenced from startup_stm32f030x6.o(RESET)
- FLASH_IRQHandler from startup_stm32f030x6.o(.text) referenced from startup_stm32f030x6.o(RESET)
- HardFault_Handler from stm32f0xx_it.o(i.HardFault_Handler) referenced from startup_stm32f030x6.o(RESET)
- I2C1_IRQHandler from startup_stm32f030x6.o(.text) referenced from startup_stm32f030x6.o(RESET)
- NMI_Handler from stm32f0xx_it.o(i.NMI_Handler) referenced from startup_stm32f030x6.o(RESET)
- PendSV_Handler from stm32f0xx_it.o(i.PendSV_Handler) referenced from startup_stm32f030x6.o(RESET)
- RCC_IRQHandler from startup_stm32f030x6.o(.text) referenced from startup_stm32f030x6.o(RESET)
- RTC_IRQHandler from startup_stm32f030x6.o(.text) referenced from startup_stm32f030x6.o(RESET)
- Reset_Handler from startup_stm32f030x6.o(.text) referenced from startup_stm32f030x6.o(RESET)
- SPI1_IRQHandler from startup_stm32f030x6.o(.text) referenced from startup_stm32f030x6.o(RESET)
- SVC_Handler from stm32f0xx_it.o(i.SVC_Handler) referenced from startup_stm32f030x6.o(RESET)
- SysTick_Handler from stm32f0xx_it.o(i.SysTick_Handler) referenced from startup_stm32f030x6.o(RESET)
- SystemInit from system_stm32f0xx.o(i.SystemInit) referenced from startup_stm32f030x6.o(.text)
- TIM14_IRQHandler from startup_stm32f030x6.o(.text) referenced from startup_stm32f030x6.o(RESET)
- TIM16_IRQHandler from startup_stm32f030x6.o(.text) referenced from startup_stm32f030x6.o(RESET)
- TIM17_IRQHandler from startup_stm32f030x6.o(.text) referenced from startup_stm32f030x6.o(RESET)
- TIM1_BRK_UP_TRG_COM_IRQHandler from startup_stm32f030x6.o(.text) referenced from startup_stm32f030x6.o(RESET)
- TIM1_CC_IRQHandler from startup_stm32f030x6.o(.text) referenced from startup_stm32f030x6.o(RESET)
- TIM3_IRQHandler from startup_stm32f030x6.o(.text) referenced from startup_stm32f030x6.o(RESET)
- USART1_IRQHandler from startup_stm32f030x6.o(.text) referenced from startup_stm32f030x6.o(RESET)
- WWDG_IRQHandler from startup_stm32f030x6.o(.text) referenced from startup_stm32f030x6.o(RESET)
- __main from entry.o(.ARM.Collect$$$$00000000) referenced from startup_stm32f030x6.o(.text)
- fputc from main.o(i.fputc) referenced from printf1.o(i.__0printf$1)
- main from main.o(i.main) referenced from entry9a.o(.ARM.Collect$$$$0000000B)

### Global Symbols

__main (Thumb, 0 bytes, Stack size unknown bytes, entry.o(.ARM.Collect$$$$00000000))
[Address Reference Count : 1]

- startup_stm32f030x6.o(.text)

_main_stk (Thumb, 0 bytes, Stack size unknown bytes, entry2.o(.ARM.Collect$$$$00000001))

_main_scatterload (Thumb, 0 bytes, Stack size unknown bytes, entry5.o(.ARM.Collect$$$$00000004))

[Calls]

- >> __scatterload

__main_after_scatterload (Thumb, 0 bytes, Stack size unknown bytes, entry5.o(.ARM.Collect$$$$00000004))

[Called By]

- >> __scatterload

_main_clock (Thumb, 0 bytes, Stack size unknown bytes, entry7b.o(.ARM.Collect$$$$00000008))

_main_cpp_init (Thumb, 0 bytes, Stack size unknown bytes, entry8b.o(.ARM.Collect$$$$0000000A))

_main_init (Thumb, 0 bytes, Stack size unknown bytes, entry9a.o(.ARM.Collect$$$$0000000B))

__rt_final_cpp (Thumb, 0 bytes, Stack size unknown bytes, entry10a.o(.ARM.Collect$$$$0000000D))

__rt_final_exit (Thumb, 0 bytes, Stack size unknown bytes, entry11a.o(.ARM.Collect$$$$0000000F))

Reset_Handler (Thumb, 8 bytes, Stack size 0 bytes, startup_stm32f030x6.o(.text))
[Address Reference Count : 1]

- startup_stm32f030x6.o(RESET)

ADC1_IRQHandler (Thumb, 0 bytes, Stack size 0 bytes, startup_stm32f030x6.o(.text))

[Calls]

- >> ADC1_IRQHandler

[Called By]

- >> ADC1_IRQHandler

[Address Reference Count : 1]

- startup_stm32f030x6.o(RESET)

DMA1_Channel1_IRQHandler (Thumb, 0 bytes, Stack size 0 bytes, startup_stm32f030x6.o(.text))
[Address Reference Count : 1]

- startup_stm32f030x6.o(RESET)

DMA1_Channel2_3_IRQHandler (Thumb, 0 bytes, Stack size 0 bytes, startup_stm32f030x6.o(.text))
[Address Reference Count : 1]

- startup_stm32f030x6.o(RESET)

DMA1_Channel4_5_IRQHandler (Thumb, 0 bytes, Stack size 0 bytes, startup_stm32f030x6.o(.text))
[Address Reference Count : 1]

- startup_stm32f030x6.o(RESET)

EXTI0_1_IRQHandler (Thumb, 0 bytes, Stack size 0 bytes, startup_stm32f030x6.o(.text))
[Address Reference Count : 1]

- startup_stm32f030x6.o(RESET)

EXTI2_3_IRQHandler (Thumb, 0 bytes, Stack size 0 bytes, startup_stm32f030x6.o(.text))
[Address Reference Count : 1]

- startup_stm32f030x6.o(RESET)

EXTI4_15_IRQHandler (Thumb, 0 bytes, Stack size 0 bytes, startup_stm32f030x6.o(.text))
[Address Reference Count : 1]

- startup_stm32f030x6.o(RESET)

FLASH_IRQHandler (Thumb, 0 bytes, Stack size 0 bytes, startup_stm32f030x6.o(.text))
[Address Reference Count : 1]

- startup_stm32f030x6.o(RESET)

I2C1_IRQHandler (Thumb, 0 bytes, Stack size 0 bytes, startup_stm32f030x6.o(.text))
[Address Reference Count : 1]

- startup_stm32f030x6.o(RESET)

RCC_IRQHandler (Thumb, 0 bytes, Stack size 0 bytes, startup_stm32f030x6.o(.text))
[Address Reference Count : 1]

- startup_stm32f030x6.o(RESET)

RTC_IRQHandler (Thumb, 0 bytes, Stack size 0 bytes, startup_stm32f030x6.o(.text))
[Address Reference Count : 1]

- startup_stm32f030x6.o(RESET)

SPI1_IRQHandler (Thumb, 0 bytes, Stack size 0 bytes, startup_stm32f030x6.o(.text))
[Address Reference Count : 1]

- startup_stm32f030x6.o(RESET)

TIM14_IRQHandler (Thumb, 0 bytes, Stack size 0 bytes, startup_stm32f030x6.o(.text))
[Address Reference Count : 1]

- startup_stm32f030x6.o(RESET)

TIM16_IRQHandler (Thumb, 0 bytes, Stack size 0 bytes, startup_stm32f030x6.o(.text))
[Address Reference Count : 1]

- startup_stm32f030x6.o(RESET)

TIM17_IRQHandler (Thumb, 0 bytes, Stack size 0 bytes, startup_stm32f030x6.o(.text))
[Address Reference Count : 1]

- startup_stm32f030x6.o(RESET)

TIM1_BRK_UP_TRG_COM_IRQHandler (Thumb, 0 bytes, Stack size 0 bytes, startup_stm32f030x6.o(.text))
[Address Reference Count : 1]

- startup_stm32f030x6.o(RESET)

TIM1_CC_IRQHandler (Thumb, 0 bytes, Stack size 0 bytes, startup_stm32f030x6.o(.text))
[Address Reference Count : 1]

- startup_stm32f030x6.o(RESET)

TIM3_IRQHandler (Thumb, 0 bytes, Stack size 0 bytes, startup_stm32f030x6.o(.text))
[Address Reference Count : 1]

- startup_stm32f030x6.o(RESET)

USART1_IRQHandler (Thumb, 0 bytes, Stack size 0 bytes, startup_stm32f030x6.o(.text))
[Address Reference Count : 1]

- startup_stm32f030x6.o(RESET)

WWDG_IRQHandler (Thumb, 0 bytes, Stack size 0 bytes, startup_stm32f030x6.o(.text))
[Address Reference Count : 1]

- startup_stm32f030x6.o(RESET)

__aeabi_uidiv (Thumb, 0 bytes, Stack size 12 bytes, uidiv.o(.text), UNUSED)

__aeabi_uidivmod (Thumb, 44 bytes, Stack size 12 bytes, uidiv.o(.text))

[Stack]

- Max Depth = 12
- Call Chain = __aeabi_uidivmod

[Called By]

- >> main
- >> SystemClock_Config
- >> HAL_InitTick
- >> HAL_RCC_GetSysClockFreq
- >> UART_SetConfig
- >> _printf_core

__scatterload (Thumb, 28 bytes, Stack size 0 bytes, init.o(.text))

[Calls]

- >> __main_after_scatterload

[Called By]

- >> _main_scatterload

__scatterload_rt2 (Thumb, 0 bytes, Stack size 0 bytes, init.o(.text), UNUSED)

HAL_Delay (Thumb, 28 bytes, Stack size 16 bytes, stm32f0xx_hal.o(i.HAL_Delay))

[Stack]

- Max Depth = 16
- Call Chain = HAL_Delay

[Calls]

- >> HAL_GetTick

[Called By]

- >> main

HAL_GPIO_Init (Thumb, 302 bytes, Stack size 24 bytes, stm32f0xx_hal_gpio.o(i.HAL_GPIO_Init))

[Stack]

- Max Depth = 24
- Call Chain = HAL_GPIO_Init

[Called By]

- >> HAL_UART_MspInit
- >> HAL_SPI_MspInit
- >> HAL_I2C_MspInit
- >> main

HAL_GPIO_WritePin (Thumb, 12 bytes, Stack size 0 bytes, stm32f0xx_hal_gpio.o(i.HAL_GPIO_WritePin))

[Called By]

- >> main
- >> nrf24_csn_digitalWrite
- >> nrf24_ce_digitalWrite

HAL_GetTick (Thumb, 6 bytes, Stack size 0 bytes, stm32f0xx_hal.o(i.HAL_GetTick))

[Called By]

- >> HAL_UART_Transmit
- >> HAL_RCC_OscConfig
- >> HAL_RCC_ClockConfig
- >> HAL_RCCEx_PeriphCLKConfig
- >> HAL_Delay
- >> HAL_SPI_TransmitReceive
- >> SPI_WaitFlagStateUntilTimeout
- >> SPI_WaitFifoStateUntilTimeout
- >> UART_WaitOnFlagUntilTimeout

HAL_I2CEx_ConfigAnalogFilter (Thumb, 74 bytes, Stack size 16 bytes, stm32f0xx_hal_i2c_ex.o(i.HAL_I2CEx_ConfigAnalogFilter))

[Stack]

- Max Depth = 16
- Call Chain = HAL_I2CEx_ConfigAnalogFilter

[Called By]

- >> MX_I2C1_Init

HAL_I2CEx_ConfigDigitalFilter (Thumb, 72 bytes, Stack size 16 bytes, stm32f0xx_hal_i2c_ex.o(i.HAL_I2CEx_ConfigDigitalFilter))

[Stack]

- Max Depth = 16
- Call Chain = HAL_I2CEx_ConfigDigitalFilter

[Called By]

- >> MX_I2C1_Init

HAL_I2C_Init (Thumb, 176 bytes, Stack size 16 bytes, stm32f0xx_hal_i2c.o(i.HAL_I2C_Init))

[Stack]

- Max Depth = 72
- Call Chain = HAL_I2C_Init ⇒ HAL_I2C_MspInit ⇒ HAL_GPIO_Init

[Calls]

- >> HAL_I2C_MspInit

[Called By]

- >> MX_I2C1_Init

HAL_I2C_MspInit (Thumb, 66 bytes, Stack size 32 bytes, stm32f0xx_hal_msp.o(i.HAL_I2C_MspInit))

[Stack]

- Max Depth = 56
- Call Chain = HAL_I2C_MspInit ⇒ HAL_GPIO_Init

[Calls]

- >> HAL_GPIO_Init

[Called By]

- >> HAL_I2C_Init

HAL_IncTick (Thumb, 10 bytes, Stack size 0 bytes, stm32f0xx_hal.o(i.HAL_IncTick))

[Called By]

- >> SysTick_Handler

HAL_Init (Thumb, 26 bytes, Stack size 8 bytes, stm32f0xx_hal.o(i.HAL_Init))

[Stack]

- Max Depth = 28
- Call Chain = HAL_Init ⇒ HAL_InitTick ⇒ __aeabi_uidivmod

[Calls]

- >> HAL_MspInit
- >> HAL_InitTick

[Called By]

- >> main

HAL_InitTick (Thumb, 34 bytes, Stack size 8 bytes, stm32f0xx_hal.o(i.HAL_InitTick))

[Stack]

- Max Depth = 20
- Call Chain = HAL_InitTick ⇒ __aeabi_uidivmod

[Calls]

- >> HAL_SYSTICK_Config
- >> HAL_RCC_GetHCLKFreq
- >> HAL_NVIC_SetPriority
- >> __aeabi_uidivmod

[Called By]

- >> HAL_RCC_ClockConfig
- >> HAL_Init

HAL_MspInit (Thumb, 64 bytes, Stack size 8 bytes, stm32f0xx_hal_msp.o(i.HAL_MspInit))

[Stack]

- Max Depth = 16
- Call Chain = HAL_MspInit ⇒ HAL_NVIC_SetPriority

[Calls]

- >> HAL_NVIC_SetPriority

[Called By]

- >> HAL_Init

HAL_NVIC_SetPriority (Thumb, 8 bytes, Stack size 8 bytes, stm32f0xx_hal_cortex.o(i.HAL_NVIC_SetPriority))

[Stack]

- Max Depth = 8
- Call Chain = HAL_NVIC_SetPriority

[Calls]

- >> NVIC_SetPriority

[Called By]

- >> HAL_MspInit
- >> SystemClock_Config
- >> HAL_InitTick

HAL_RCCEx_PeriphCLKConfig (Thumb, 218 bytes, Stack size 24 bytes, stm32f0xx_hal_rcc_ex.o(i.HAL_RCCEx_PeriphCLKConfig))

[Stack]

- Max Depth = 24
- Call Chain = HAL_RCCEx_PeriphCLKConfig

[Calls]

- >> HAL_GetTick

[Called By]

- >> SystemClock_Config

HAL_RCC_ClockConfig (Thumb, 280 bytes, Stack size 24 bytes, stm32f0xx_hal_rcc.o(i.HAL_RCC_ClockConfig))

[Stack]

- Max Depth = 76
- Call Chain = HAL_RCC_ClockConfig ⇒ HAL_RCC_GetSysClockFreq ⇒ __aeabi_uidivmod

[Calls]

- >> HAL_GetTick
- >> HAL_InitTick
- >> HAL_RCC_GetSysClockFreq

[Called By]

- >> SystemClock_Config

HAL_RCC_GetHCLKFreq (Thumb, 6 bytes, Stack size 0 bytes, stm32f0xx_hal_rcc.o(i.HAL_RCC_GetHCLKFreq))

[Called By]

- >> SystemClock_Config
- >> HAL_InitTick

HAL_RCC_GetPCLK1Freq (Thumb, 20 bytes, Stack size 0 bytes, stm32f0xx_hal_rcc.o(i.HAL_RCC_GetPCLK1Freq))

[Called By]

- >> UART_SetConfig

HAL_RCC_GetSysClockFreq (Thumb, 76 bytes, Stack size 40 bytes, stm32f0xx_hal_rcc.o(i.HAL_RCC_GetSysClockFreq))

[Stack]

- Max Depth = 52
- Call Chain = HAL_RCC_GetSysClockFreq ⇒ __aeabi_uidivmod

[Calls]

- >> __aeabi_uidivmod

[Called By]

- >> HAL_RCC_ClockConfig
- >> UART_SetConfig

HAL_RCC_OscConfig (Thumb, 840 bytes, Stack size 32 bytes, stm32f0xx_hal_rcc.o(i.HAL_RCC_OscConfig))

[Stack]

- Max Depth = 32
- Call Chain = HAL_RCC_OscConfig

[Calls]

- >> HAL_GetTick

[Called By]

- >> SystemClock_Config

HAL_SPI_Init (Thumb, 184 bytes, Stack size 24 bytes, stm32f0xx_hal_spi.o(i.HAL_SPI_Init))

[Stack]

- Max Depth = 80
- Call Chain = HAL_SPI_Init ⇒ HAL_SPI_MspInit ⇒ HAL_GPIO_Init

[Calls]

- >> HAL_SPI_MspInit

[Called By]

- >> MX_SPI1_Init

HAL_SPI_MspInit (Thumb, 60 bytes, Stack size 32 bytes, stm32f0xx_hal_msp.o(i.HAL_SPI_MspInit))

[Stack]

- Max Depth = 56
- Call Chain = HAL_SPI_MspInit ⇒ HAL_GPIO_Init

[Calls]

- >> HAL_GPIO_Init

[Called By]

- >> HAL_SPI_Init

HAL_SPI_TransmitReceive (Thumb, 584 bytes, Stack size 48 bytes, stm32f0xx_hal_spi.o(i.HAL_SPI_TransmitReceive))

[Stack]

- Max Depth = 96
- Call Chain = HAL_SPI_TransmitReceive ⇒ SPI_EndRxTxTransaction ⇒ SPI_WaitFlagStateUntilTimeout

[Calls]

- >> SPI_EndRxTxTransaction
- >> HAL_GetTick

[Called By]

- >> spi_transfer

HAL_SYSTICK_CLKSourceConfig (Thumb, 20 bytes, Stack size 0 bytes, stm32f0xx_hal_cortex.o(i.HAL_SYSTICK_CLKSourceConfig))

[Called By]

- >> SystemClock_Config

HAL_SYSTICK_Callback (Thumb, 2 bytes, Stack size 0 bytes, stm32f0xx_hal_cortex.o(i.HAL_SYSTICK_Callback))

[Called By]

- >> HAL_SYSTICK_IRQHandler

HAL_SYSTICK_Config (Thumb, 38 bytes, Stack size 8 bytes, stm32f0xx_hal_cortex.o(i.HAL_SYSTICK_Config))

[Stack]

- Max Depth = 8
- Call Chain = HAL_SYSTICK_Config

[Calls]

- >> NVIC_SetPriority

[Called By]

- >> SystemClock_Config
- >> HAL_InitTick

HAL_SYSTICK_IRQHandler (Thumb, 8 bytes, Stack size 8 bytes, stm32f0xx_hal_cortex.o(i.HAL_SYSTICK_IRQHandler))

[Stack]

- Max Depth = 8
- Call Chain = HAL_SYSTICK_IRQHandler

[Calls]

- >> HAL_SYSTICK_Callback

[Called By]

- >> SysTick_Handler

HAL_UART_Init (Thumb, 108 bytes, Stack size 16 bytes, stm32f0xx_hal_uart.o(i.HAL_UART_Init))

[Stack]

- Max Depth = 92
- Call Chain = HAL_UART_Init ⇒ UART_SetConfig ⇒ HAL_RCC_GetSysClockFreq ⇒ __aeabi_uidivmod

[Calls]

- >> HAL_UART_MspInit
- >> UART_AdvFeatureConfig
- >> UART_SetConfig
- >> UART_CheckIdleState

[Called By]

- >> MX_USART1_UART_Init

HAL_UART_MspInit (Thumb, 64 bytes, Stack size 32 bytes, stm32f0xx_hal_msp.o(i.HAL_UART_MspInit))

[Stack]

- Max Depth = 56
- Call Chain = HAL_UART_MspInit ⇒ HAL_GPIO_Init

[Calls]

- >> HAL_GPIO_Init

[Called By]

- >> HAL_UART_Init

HAL_UART_Transmit (Thumb, 200 bytes, Stack size 48 bytes, stm32f0xx_hal_uart.o(i.HAL_UART_Transmit))

[Stack]

- Max Depth = 88
- Call Chain = HAL_UART_Transmit ⇒ UART_WaitOnFlagUntilTimeout

[Calls]

- >> HAL_GetTick
- >> UART_WaitOnFlagUntilTimeout

[Called By]

- >> fputc

HardFault_Handler (Thumb, 2 bytes, Stack size 0 bytes, stm32f0xx_it.o(i.HardFault_Handler))

[Calls]

- >> HardFault_Handler

[Called By]

- >> HardFault_Handler

[Address Reference Count : 1]

- startup_stm32f030x6.o(RESET)

NMI_Handler (Thumb, 2 bytes, Stack size 0 bytes, stm32f0xx_it.o(i.NMI_Handler))
[Address Reference Count : 1]

- startup_stm32f030x6.o(RESET)

PendSV_Handler (Thumb, 2 bytes, Stack size 0 bytes, stm32f0xx_it.o(i.PendSV_Handler))
[Address Reference Count : 1]

- startup_stm32f030x6.o(RESET)

SVC_Handler (Thumb, 2 bytes, Stack size 0 bytes, stm32f0xx_it.o(i.SVC_Handler))
[Address Reference Count : 1]
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

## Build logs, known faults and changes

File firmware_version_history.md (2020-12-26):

# Daytripper Firmware History

[Buy on Tindie!](https://www.tindie.com/products/dekuNukem/daytripper-hide-my-windows-laser-tripwire/) | [Official Discord](https://discord.gg/VM4kbnf) | [Getting Started](quick_start_guide.md) | [Main Page](/README.md)

------

## TX

### 1.1.2

Bugfix, 4 September 2020. [Download Here](https://github.com/dekuNukem/daytripper/raw/master/firmware/TX_1.1.2.dfu)

**`FIXED`**

* Removed test mode and user button functions to free up flash memory space.

### 1.1.1

Bugfix, 30 August 2020. [Download Here](https://github.com/dekuNukem/daytripper/raw/master/firmware/TX_1.1.1.dfu)

**`FIXED`**

* More stable voltage monitoring for low-battery shutdown.

### 1.1.0

Major update, 27 August 2020. [Download Here](https://github.com/dekuNukem/daytripper/raw/master/firmware/TX_1.1.0.dfu)

**`NEW`**

* Added support for custom configuration via companion PC app.

* Adjustable refresh rate, noise reduction, timing budget, detection range, trigger LED, and debug output.

* See [Advanced Usage Guide](/advanced_usage.md) for usage.

* Reduced power consumption. Up to 10 extra hours of battery life on default settings.

### 1.0.0

Initial Release, Sept 2019. [Download Here](https://github.com/dekuNukem/daytripper/raw/master/firmware/TX_1.0.0.dfu)

## RX

### 1.0.1

Minor Fix. Sept 2020. [Download Here](https://github.com/dekuNukem/daytripper/raw/master/firmware/RX_1.0.1.dfu)

**`FIXED`**

* Updated copyright year.

* RX blue LED now keep blinking when TX has low battery.

* Debug print now notifies user if nothing has been received.

### 1.0.0

Initial Release, Sept 2019. [Download Here](https://github.com/dekuNukem/daytripper/raw/master/firmware/RX_1.0.0.dfu)

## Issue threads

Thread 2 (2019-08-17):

Included cable didn't work

Notenoughnamespace, 2019-08-17:
Product works perfectly, but not with the included USB cable.

Tried across different PCs and only thought to try a different cable so I could say that I had - turns out the product was working perfectly. So worth testing with care.

dekuNukem, 2019-08-17:
Well that was unexpected, sorry about the issue. Please contact me on Tindie and I'll give you a refund of the cable.

Closed 2019-08-18.

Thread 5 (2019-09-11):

Question: What is the expected latency from Tx to Rx? Similar to a wireless keyboard?

davydka, 2019-09-11:

dekuNukem, 2019-09-11:
I haven't measured it myself, but sources indicate the TX to RX latency should be around 2ms.

https://forum.pjrc.com/threads/42711-Teensy-3-2-with-NRF24L01

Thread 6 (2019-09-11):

How to open the PCB files?

hiphonezhang, 2019-09-11:
I use the allegro 16.6 and eagle 9.5.0，but can‘t open.

dekuNukem, 2019-09-11:
The PCB file was made using Eagle. You can download it here:

https://www.autodesk.com/products/eagle/free-download

This project is within the limits of the free version, so you don't have to pay anything.

hiphonezhang, 2019-09-11:
Thank you for your reply，Maybe the PCB file I downloaded is wrong，I  download it again and open it successfully.

Closed 2019-09-11.

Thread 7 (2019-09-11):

Any plans to release the schematics/parts list?

casconed, 2019-09-11:

dekuNukem, 2019-09-11:
The schematic is the Eagle `.sch` files in the `pcb` folder, and part list can be generated from that.  Here's a tutorial:

https://www.autodesk.com/products/eagle/blog/creating-bom-pcb-manufacturing-basics-2/

casconed, 2019-09-11:
awesome, sorry - should have taken a more comprehensive look before opening an issue!

Closed 2019-09-11.

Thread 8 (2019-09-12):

Interested in making these my control my lights

dude2k5, 2019-09-12:
I've always needed something like this, there was no tech or sensor or signal that would detect when someone walked into rooms. Can you keep these plugged in so they are on at all times? Im going to try one in my bedroom, when i walk in, hopefully i can run a script that will turn on a wemo light. Then turn it off when i walk out. If it works, this would be AMAZING. Very very cool project.

nh2, 2019-09-14:
Interested in that too. Thanks for answering the "keep plugged in" question, that was also my first one.

Second, can you use (and purchase) multiple TX with a single RX, so that you can use one RX "base station" to handle multiple doors?

dekuNukem, 2019-09-14:
I touched upon this topic in [advanced usage guide](https://github.com/dekuNukem/daytripper/blob/master/advanced_usage.md#using-multiple-modules) .

Basically, daytripper wasn't really designed with multiple TX or RX in mind, so I didn't to much testing. However Single RX multiple TX does seem to work, and RX will respond with ANY TX triggers.

nh2, 2019-09-15:
Thanks! When one of multipe TX triggers, can the RX figure out which one it was?

dekuNukem, 2019-09-15:
At the moment no. RX will do the same thing if any of the multiple TX triggers.

However, each TX does include a unique ID in its [on-air-packet](https://github.com/dekuNukem/daytripper/blob/master/advanced_usage.md#on-air-packet-format). So if you're willing to do a bit programming, it is completely possible to assign different actions to different TXs.

TX also prints out debug information in its debug serial harder, so that's another way to tell.

nh2, 2019-09-15:
> However, each TX does include a unique ID in its [on-air-packet](https://github.com/dekuNukem/daytripper/blob/master/advanced_usage.md#on-air-packet-format). So if you're willing to do a bit programming

That's great, that'll do.

I've ordered one just now to try it out.

dekuNukem, 2019-09-15:
Thanks, the relevant code is [around here](https://github.com/dekuNukem/daytripper/blob/3fa12687489bfb83d95f485eb91f7c48078b31e9/firmware/rx/Src/main.c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) in the RX firmware. `received_data[0]` is the unique ID, you can check that and do your stuff.

If you're unfamiliar with STM32 dev, I have wrote [a tutorial](https://github.com/dekuNukem/STM32_tutorials) about it too.

nh2, 2019-09-15:
Good stuff, very appreaciated!

That's how modern hardware should work: Easy to order, easy to modify for your needs. :+1:

Slomo17, 2019-10-30:
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

I have a simmilar project, which may be possible with the daytripper.
For years i wanted to build something, that pauses the movie i am watching when i leave the room, and resumes it when i am back (i use kodi as a media center on a raspberry pi). The main problem here is if there are more than just me in the room and another person leaves the room it would resume the movie. So i would need something that can detect the direction of the person crossing the laser, for which i would need two lasers. With the ID you mention it may be possible for me to use two TX und figure out which one got activated first to determin the direction

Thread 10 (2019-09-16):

Electronic components

ViktorDomnikov, 2019-09-16:
Hello.
What Electronic components did you use in this project?
Resistors? Capacitors? etc.
I see tags C11, C12, R2, but I don't know what capacitor.
Please tell me where I can find this information.
Thank you.

dekuNukem, 2019-09-16:
All the details are in the board and schematic files in the [pcb folder](https://github.com/dekuNukem/daytripper/tree/master/pcb). They were made using Eagle, which can be [download it here](https://www.autodesk.com/products/eagle/free-download).

Closed 2019-09-16.

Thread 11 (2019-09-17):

About firmware

oniyakun, 2019-09-17:
I'm ordered some STM32f6p6 chips and try to writing the firmware `rx.hex` and `tx.hex` into it, but the firmware is much much larger than the chip capacity then I cannot write the firmware. plz help me, what should I do?

dekuNukem, 2019-09-17:
The chip that both TX and RX uses is STM32F042F6P6, so first make sure the chip is correct.

Then if you have the boards assembled, you can upload their firmware through USB DFU, which is described here:

https://github.com/dekuNukem/daytripper/blob/master/advanced_usage.md#usb-firmware-updates

oniyakun, 2019-09-17:
Oh so u means I could upload the firmware by using the USB DFU software even the chip is empty? I'm worry about that cloud I using USB DFU to upload the firmware into an empty chip, huge thanx!

oniyakun, 2019-09-17:
And there is any changed component in the PCB files since the last time u upload?

dekuNukem, 2019-09-17:
I havent made any changes to the components on the PCB. And yes USB DFU works even when the chip is empty :)

oniyakun, 2019-09-17:
Got it, thx a lot!

Closed 2019-09-17.

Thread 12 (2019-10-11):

How much is the power consumption of the TX?

JassyL, 2019-10-11:
Does it have a sleep mode?Or it always working at normal mode, that will cost a lot of electricity. Have you test the current when TX is working?
I have a thought to build a low-power consumption TX terminal，with STM32L0 series and low-power Bluetooth module

JassyL, 2019-10-11:
Alright ,may be the only way is to increase the battery capacity?

Closed 2020-05-22.

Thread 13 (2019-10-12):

About TX

oniyakun, 2019-10-12:
Im already success put all components on the TX&RX board just like your's and flash the firmware via USB DFU.

RX looks working fine, the stats led first get blink and into dim, when press user button it typed out the debug messages. So far look nice.

But TX I think it had some issues, the stats led always breath and never stop, also RX did not received data from the TX. I tried press user button over 2 secs into test mode, but the led just go out, also didnt receive any data. I dont know whats wrong about Im doing, all components look got nice soldering and works good, pls help me, huge thx!

dekuNukem, 2020-03-27:
Hi oniyakun:

I did discover an issue with the early production boards, such as the one you have.

I have [written about it here](https://github.com/dekuNukem/daytripper/blob/master/mysterious_glitch.md). Fortunately it is easily fixable, so feel free to give it a try.

I do apologise about the delay in response, I must have missed it.

Best Regards,

Allen

Closed 2020-08-30.

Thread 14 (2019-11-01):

About schematic diagram

ZSIRS, 2019-11-01:
Why is it that after downloading the project,  the schematic diagram shows the memory size,  but it is blank when opened with Altium Designer2019? Thank you ever so much!

dekuNukem, 2019-11-01:
I used Autodesk Eagle for the PCB design. You can download it here:

https://www.autodesk.com/products/eagle/free-download

Closed 2020-02-09.

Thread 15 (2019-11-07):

TX unit not working

cgoodman1976, 2019-11-07:
Hello, no matter what I try, the TX unit appears to not function. I press the button expecting a message to be sent to the RX unit and it does not register. I've charged the TX unit for about 2 hours and the amber light goes off. When I turn on the unit it blinks 6 times and then goes off. If I wave my hand after the blinking has turned off , it doesnt send a signal to the RX unit.

When I press the button on the RX , I get a prompt back like this:

transmitter ID: 0x0
baseline: 0mm
latest trigger: 0mm
input voltage: 0mV
power-on time: 0 minutes

I'm using a Mac Book Pro 15" 2017 edition. I also have access to a Windows 10 box as well. Both have the same issue with the RX unit.

Please help.

dekuNukem, 2019-11-07:
Hi:

I'm really sorry about this issue, it was discovered recently and rather caught me off guard.

I wrote a short article, including how to fix it. Please take a look here:

https://github.com/dekuNukem/daytripper/blob/master/mysterious_glitch.md

If you do manage to fix it, let me know your Tindie order number and I'll give you a partial refund for the trouble. And if that didn't work, I'll mail you a new one for free.

cgoodman1976, 2019-11-08:
howdy! I did the instructions as you suggested and all is well. The unit is
working as expected.

Thanks!

-cg

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

dekuNukem, 2019-11-08:
Great! I'll ask Tindie to give you a partial refund for the trouble. You should get it within 48 hours.

varenc, 2020-03-27:
@dekuNukem I'd humbly recommend you make the glitch doc a bit easier to find. Maybe a link on the readme or in quick start guide?

I spent some time looking through the advanced doc and recent issues before I found it.  I suspect #18 has the same problem but it doesn't look like they found the mysterious glitch doc.  Thanks for documenting it so thoroughly!  Super interesting how such a subtle thing can cause issues.

ringnex1, 2020-04-08:
hey varenc did your rx start working again because I had that problem but my tx worked fine if you did can help me with it

varenc, 2020-04-09:
so I think my RX was actually working fine all along. How do you know your TX is working correctly?  Are you sure you don't have the battery contact problem that's [documented here](https://github.com/dekuNukem/daytripper/blob/master/mysterious_glitch.md)?

The RX's debug button seems to return all zeros if it's never paired/seen the TX so if you're seeing all zeros that doesn't necessarily mean the issue is with the RX.  Could be that TX is not transmitting correctly (what happened with me), or could mean that the RX for some reason isn't able to correctly receive anything, but based on my limited experience my guess is it's an TX transmission issue.

I open PR #19 to make a tiny note of this in the advanced usage guide.

Closed 2019-11-08.

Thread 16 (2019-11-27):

Disable Blue LED

PCBuildr, 2019-11-27:
Is there a way to disable the blue LED light on the TX when the sensor is triggered? This is a great piece of equipment for hiding computer windows from prying eyes, however, if one were setting up the TX in a darkened hallway, for instance, the blue LED light illuminating when someone passed by could easily draw unwanted attention to itself, which in turn could raise suspicions about its function and create more issues than it solves. Yes, the light does serve a useful function in its capacity to relay its status to the user, but wouldn't some kind of "stealth" mode during actual operation help to strengthen its usefulness.

dekuNukem, 2019-11-28:
Like you said, I do feel that the LED is useful for indicating what the TX is doing. Without it there's no way to see if it's triggering correctly, or if it's working at all.

I can indeed write you a custom firmware for you to disable the LED, but there would be no easy way to switch between normal and "stealth" mode. A simpler solution would be just cover it with a piece of black tape, faster and easier to undo.

geek-slt, 2019-11-29:
I would like to present to you one of my ideas. We are now using this to monitor pedestrians to trigger the computer to perform corresponding actions. We can imitate this model to make a privacy-protected hardware, that is, the sensor is placed in front of the computer to continuously monitor whether the person is at the table If you do n’t take action at the moment, if you ca n’t detect anyone, trigger the lock screen to prevent personal computer information from being leaked. Do you think this is feasible?

------------------&nbsp;原始邮件&nbsp;------------------
发件人:&nbsp;"dekuNukem"<notifications@github.com&gt;;
发送时间:&nbsp;2019年11月29日(星期五) 凌晨3:29
收件人:&nbsp;"dekuNukem/daytripper"<daytripper@noreply.github.com&gt;;
抄送:&nbsp;"Subscribed"<subscribed@noreply.github.com&gt;;
主题:&nbsp;Re: [dekuNukem/daytripper] Disable Blue LED (#16)

Like you said, I do feel that the LED is useful for indicating what the TX is doing. Without it there's no way to see if it's triggering correctly, or if it's working at all.

I can indeed write you a custom firmware for you to disable the LED, but there would be no easy way to switch between normal and "stealth" mode. A simpler solution would be just cover it with a piece of black tape, faster and easier to undo.

—
You are receiving this because you are subscribed to this thread.
Reply to this email directly, view it on GitHub, or unsubscribe.

dekuNukem, 2019-12-11:
ah, so basically perform an action at the end of trigger instead at the beginning. I'll spend a few days working on it, probably having the RX press a different key combo.

monophthongal, 2019-12-18:
Seconding the request for a way to disable the blue LED...

The Daytripper device is fantastic, but hard to explain the presence of if someone asks - so it would be much more useful if it didn't attract attention to itself.

> Like you said, I do feel that the LED is useful for indicating what the TX is doing. Without it there's no way to see if it's triggering correctly, or if it's working at all.

For my use case, I'm OK with this since I can still test it by waving a hand in front of it and seeing if the windows are minimized as expected. The device has been 100% reliable for me so far, so that would be enough to tell me whether it's still on and functioning.

Also, the light on the TX could still flash a few times when first turned on - this would give you an initial indicator that everything is OK.

> A simpler solution would be just cover it with a piece of black tape, faster and easier to undo.

I tried this but there is still a lot of light leaking past the tape.

dekuNukem, 2019-12-18:
yeah that make sense. I have created a new TX firmware that disables the LED after initial calibration. The new firmware and the instructions can be found in the "USB Firmware Updates" section of this guide:

https://github.com/dekuNukem/daytripper/blob/master/advanced_usage.md#usb-firmware-updates

monophthongal, 2020-01-06:
Had a chance to test the new firmware yesterday - works great! Thanks for adding it.

Closed 2020-01-09.

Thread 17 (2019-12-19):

Having two close by

kcc1982, 2019-12-19:
I got my coworker one since I thought they were on different frequencies but it turns out we are locking each other's computers. Is there a way to have two of these in the same cube farm.

dekuNukem, 2019-12-19:
By default all daytrippers are on the same adress, so they will trigger each other if there are more than one.

I wrote you a custom firmware that uses a different address. Flash them on one of the TX/RX pairs, and they'll talk on a different address, allowing you to use two sets at the same time without interference.

Download the firmware here:

https://cdn.discordapp.com/attachments/514708977498587148/657235124378664980/alt_addr.zip

and refer to "USB firmware updates" section of [this guide ](https://github.com/dekuNukem/daytripper/blob/master/advanced_usage.md#usb-firmware-updates) to see how to upload it.

kcc1982, 2019-12-29:
It worked. Thank you very much

On Dec 19, 2019 10:01 AM, dekuNukem <notifications@github.com> wrote:

By default all daytrippers are on the same adress, so they will trigger each other if there are more than one.

I wrote you a custom firmware that uses a different address. Flash them on one of the TX/RX pairs, and they'll talk on a different address, allowing you to use two sets at the same time without interference.

Download the firmware here:

https://cdn.discordapp.com/attachments/514708977498587148/657235124378664980/alt_addr.zip

and refer to "USB firmware updates" section of this guide <https://github.com/dekuNukem/daytripper/blob/master/advanced_usage.md#usb-firmware-updates> to see how to upload it.

—
You are receiving this because you authored the thread.
Reply to this email directly, view it on GitHub<https://github.com/dekuNukem/daytripper/issues/17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>, or unsubscribe<https://github.com/notifications/unsubscribe-auth/AADXPJX5HD6KDDHTVSAMVK3QZOEENANCNFSM4J5H5Y3Q>.

Closed 2020-01-02.

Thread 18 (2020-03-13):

broken rx

ringnex1, 2020-03-13:
So im on my second rx because my first one had an error and now this one has the same error when i click the user button it says this
transmitter ID: 0x0
baseline: 0mm
latest trigger: 0mm
input voltage: 0mV
power-on time: 0 minutes
and it doesnt to  anything when i trip off the tx plz help

varenc, 2020-03-27:
just got out my daytripper again and I'm seeing the same behavior.  I had things working fine a few months ago. What does it mean if all these values are zero?  TX also having issue it seems.

One guess: Could this be because the static ram has been reset after being untouched for many months? Assuming the SRAM is kept alive/powered when these are being used regularly?  Could a firmware reprogram help solve this?

varenc, 2020-03-27:
actually nvm, my issue is almost certainly this issue: https://github.com/dekuNukem/daytripper/blob/master/mysterious_glitch.md

the 0 values on the rx are a red herring I suspect. My tx's battery is definitely touching the board

ringnex1, 2020-03-27:
Hey so I don't think my tx is the issue because I don't have the battery issue and also do you know if my new set might have got lost in shipping because it's not here yet
Sent from Yahoo Mail on Android

  On Fri, Mar 27, 2020 at 2:18 AM, Chris Varenhorst<notifications@github.com> wrote:

just got out my daytripper again and I'm seeing the same behavior. I had things working fine a few months ago. What does it mean if all these values are zero? TX also having issue it seems.

One guess: Could this be because the static ram has been reset after being untouched for many months? Assuming the SRAM is kept alive/powered when these are being used regularly? Could a firmware reprogram help solve this?

—
You are receiving this because you authored the thread.
Reply to this email directly, view it on GitHub, or unsubscribe.

Closed 2020-05-22.

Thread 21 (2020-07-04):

RX not receiving signal

nicolasnsuy, 2020-07-04:
Hi, i been not able to use my sensors for a while both TX and RX were working fine, now the RX turn on the blue light breathing and then go dim.

The TX turns on ok and the blue light turns on when you you trigger the sensor.

The pc is not making any action and if i press de debug button on RX doesn't show receiving any package from the TX.

I already try updating the firmware but they still doing the same.

Any idea of what can be happening?

Thank you!

dekuNukem, 2020-07-04:
Hi There! It sounds like a issue that was discovered in early-production run models. Please take a look at [this guide](https://github.com/dekuNukem/daytripper/blob/master/mysterious_glitch.md) and see if it helps. I do apologise if for the inconvience.

nicolasnsuy, 2020-07-05:
Thank you for your response.

I already follow all steps but with out any luck, the TX has a Air gap but still not working.

Is there anything else i can try?

Thanks!

dekuNukem, 2020-07-05:
Can you tell me your Tindie order number? I'll look into it.

nicolasnsuy, 2020-07-05:
Sure, Order Number: 174290.

Thank you!

dekuNukem, 2020-07-05:
Great! I'm happy to sort this one out for you. Please check your email.

Closed 2020-07-05.

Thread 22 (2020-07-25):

Not recording keystrokes anymore

Saeijou, 2020-07-25:
Hello!

I really love your product, but now I encountered an issue.

I used it for a couple month with my Macbook Pro and in unison with BTT it worked amazingly!

Recently I went back to windows, and no dice.
It installed the "keyboard", but I can't get it to anything, no matter what mode I chose.

The lights are working as described and even if I trigger it, the receiver flashes in acknowledgement of receiving the message - yet windows does nothing.

I connected it to my macbook again, and also there it is not working anymore.
It is not recording the keystroke - even if I want to create a new script.

Did I break it by using it cross-OS? Any explanation?

dekuNukem, 2020-07-25:
Hi Saejiou:

Make sure the mode select switch is in the right place, if it is in `custom` it will press ALT+PAUSE which doesnt seem to do anything at all.

You can also try flashing the firmware again and see if it helps. You can find the instruction for both in [this guide](https://github.com/dekuNukem/daytripper/blob/master/advanced_usage.md).

Let me know how it goes!

Allen

Saeijou, 2020-07-25:
Thank you!

Interesting enough, it doesn't recognize the device it seems. I can't select "STM Device in DFU Mode"
The LED is off when I plug it in as described. (it is on if I plug it in normally)

dekuNukem, 2020-07-25:
This looks like something wrong with the physical USB port, the data isnt getting through. check that it is clean and undamaged. maybe try a different cable too.

Saeijou, 2020-07-26:
Splendid! It was the cable - i exchanged it for a shorter one when I switched computers.

Thank you so much!

Closed 2020-07-26.

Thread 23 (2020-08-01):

Hi, I was wondering, did you print these circuit boards by yourself?

linleo10, 2020-08-01:
Hi, I was wondering, did you print these circuit boards by yourself?

dekuNukem, 2020-09-10:
For prototypes, i designed the circuit boards, had them made, and reflow soldered all the components. This went on for a few iterations until it is ready for production.

For production, I use a PCB fab house, who use professional pick-and-place machine to assemble all my boards.

robvoi, 2021-03-16:
Didn't want to open a new issue - but have a question.

What finish do you use for your PCBs?
OSP, HASL, ENIG?

Thanks a lot

Closed 2020-09-13.

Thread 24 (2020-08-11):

the difference between the photo and the bom

irongu, 2020-08-11:
i find out that in the photo you use stm32f042f6p6 in both board, but in bom, it's STM32F042F4 and STM32F030F4, should i follow the photo or the bom?

dekuNukem, 2020-08-11:
they should be both STM32F042F6P6, the BOM might have been from an eariler prototype stage. I'll update it later today.

Closed 2020-08-11.

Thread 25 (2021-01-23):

import firmware into Stem32CubeIDE or System Workbench

robvoi, 2021-01-23:
Hi.
I would like to make a small change to the firmware. (3rd option not a custom option but alt+F4) First time with stm32 though.
I am struggling to import the project into STM32CubeIDE. Can you give me a hint on how to correctly import?

Depending on the method I try I either end up with the build option greyed out or with a compile error (result too big for chip memory).

When I import as "existing STMCube file" and replace src&inc I end up with:

c:\st\stm32cubeide_1.5.1\stm32cubeide\plugins\com.st.stm32cube.ide.mcu.externaltools.gnu-tools-for-stm32.7-2018-q2-update.win32_1.5.0.202011040924\tools\arm-none-eabi\bin\ld.exe: rx.elf section `.text' will not fit in region `FLASH'
c:\st\stm32cubeide_1.5.1\stm32cubeide\plugins\com.st.stm32cube.ide.mcu.externaltools.gnu-tools-for-stm32.7-2018-q2-update.win32_1.5.0.202011040924\tools\arm-none-eabi\bin\ld.exe: region `FLASH' overflowed by 8204 bytes
collect2.exe: error: ld returned 1 exit status
make: *** [makefile:60: rx.elf] Error 1
"make -j8 all" terminated with exit code 2. Build might be incomplete.

I don't get what I am doing wrong - any help would be appreciated.

robvoi, 2021-01-23:
Think I solved it with Keil IDE. Close it for now.

Closed 2021-01-23.

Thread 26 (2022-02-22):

question on having the PCB manufactured

robvoi, 2022-02-22:
I have a general question.

Is there an initial flashing with a programmer needed before flashing via USB works - in case the device gets produced based on the schematics provided?

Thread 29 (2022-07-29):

Dvorak layout windows lock unsupported?

wasp604, 2022-07-29:
The "lock" feature presses windows + L in order to lock windows, but if the keyboard layout is changed, say, to Dvorak, this functionality breaks. Is there a way to get it to press windows + L while using Dvorak?

Or am I going to have to use autohotkey to script it to the custom function? I would really appreciate being able to swap between these functions with a hardware switch instead of changing an autohotkey script.

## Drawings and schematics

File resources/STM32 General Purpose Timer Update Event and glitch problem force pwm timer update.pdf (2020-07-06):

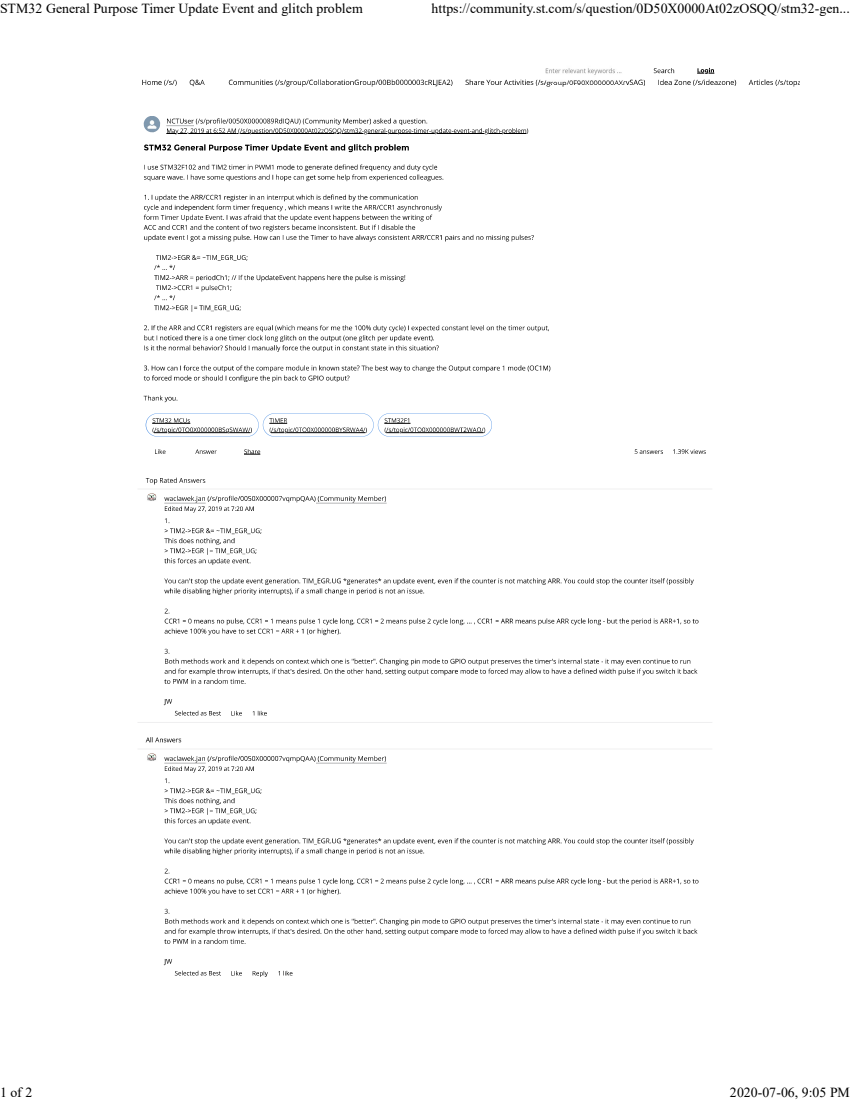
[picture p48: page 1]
STM32 General Purpose Timer Update Event and glitch problem; https://community.st.com/s/question/0D50X0000At02zOSQQ/stm32-gen...

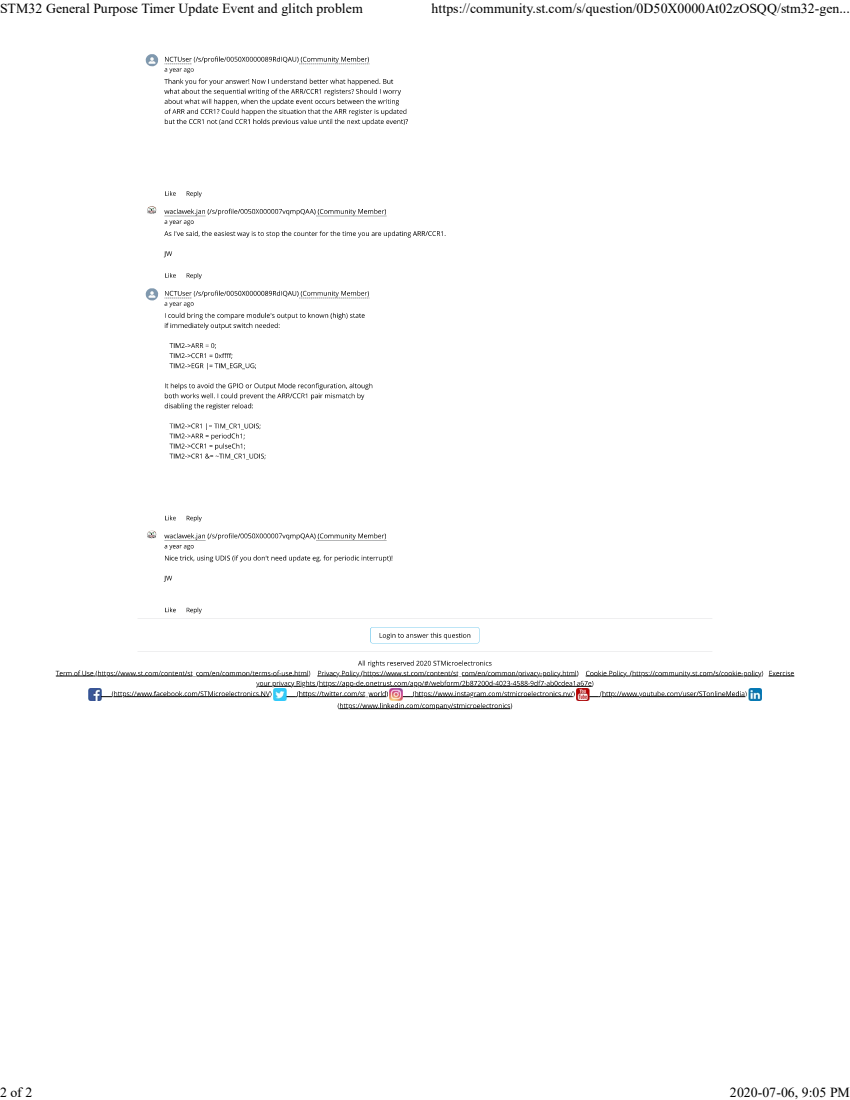
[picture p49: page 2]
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

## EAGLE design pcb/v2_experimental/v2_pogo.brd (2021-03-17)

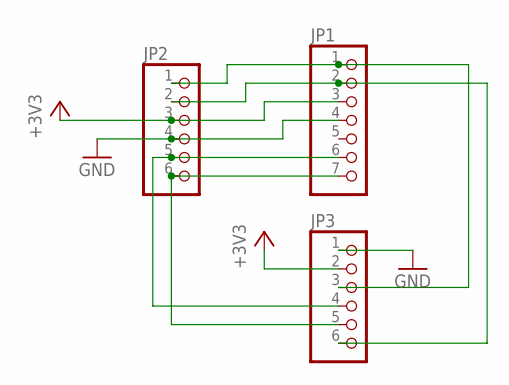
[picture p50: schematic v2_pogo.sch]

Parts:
JP1: PINHD-1X7; 1X07
JP2, JP3: PINHD-1X6; 1X06

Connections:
+3V3: JP1.3, JP2.3, JP3.2
GND: JP1.4, JP2.4, JP3.1
unnamed: JP1.7, JP2.6, JP3.5
unnamed: JP1.6, JP2.5, JP3.4
unnamed: JP1.2, JP2.2, JP3.6
unnamed: JP1.1, JP2.1, JP3.3

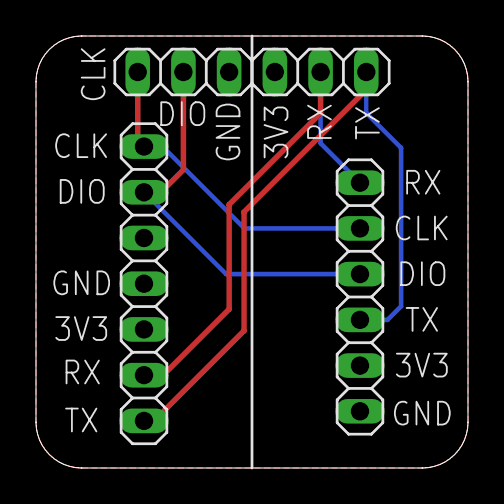
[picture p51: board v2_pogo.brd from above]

Board: 2 copper layers, 24.0 x 24.0 mm, 3 parts (0 on the bottom side), 6 nets.

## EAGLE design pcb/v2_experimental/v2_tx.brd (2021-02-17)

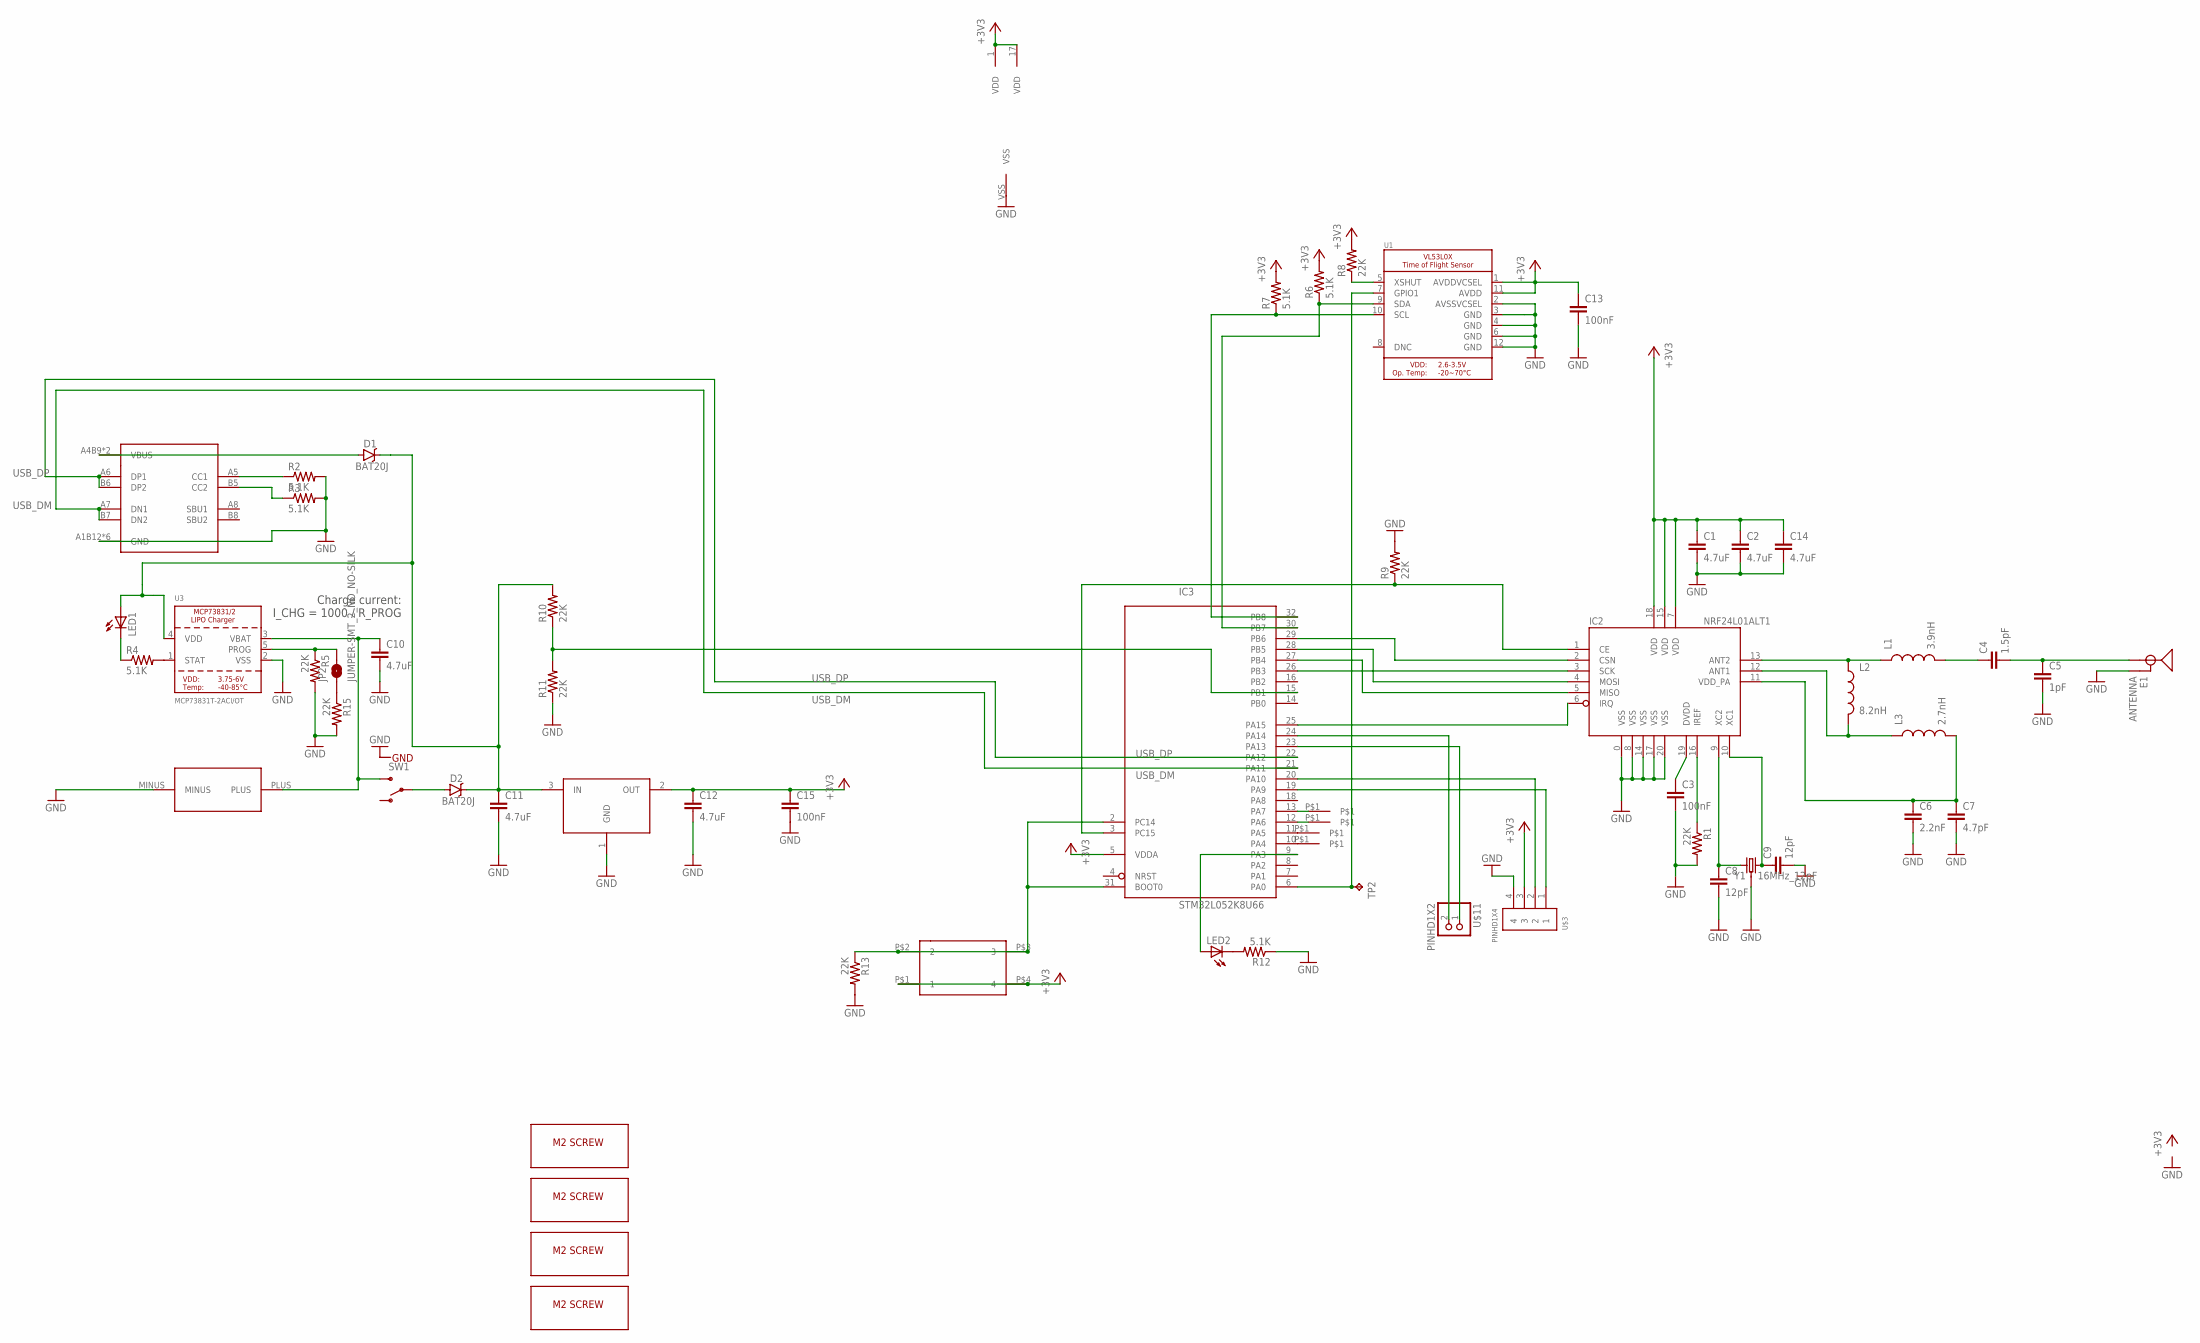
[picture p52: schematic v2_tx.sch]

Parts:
C1, C2, C10, C11, C12, C14: 4.7uF; 0805
C3, C13, C15: 100nF; 0805
C4: 1.5pF; 0805
C5: 1pF; 0805
C6: 2.2nF; 0805
C7: 4.7pF; 0805
C8, C9: 12pF; 0805
D1, D2: BAT20J; SOD-323
E1: ANTENNA; TRACE_ANTENNA_2.4GHZ_25.7MM_TUNED
IC2: NRF24L01ALT1; QFN20_ALT1
IC3: STM32L052K8U66; UFQFPN32
JP2: JUMPER-SMT_2_NO_NO-SILK; SMT-JUMPER_2_NO_NO-SILK
L1: 3.9nH; 0805
L2: 8.2nH; 0805
L3: 2.7nH; 0805
LED1, LED2: LEDCHIP-LED0805; CHIP-LED0805
R1, R5, R8, R9, R10, R11, R13, R15: 22K; 0805
R2, R3, R4, R6, R7, R12: 5.1K; 0805
SW1: SWITCH-SPDTTDFGDFG; SWITCH-SPST-SMD-A
SW2: 324_SW324_SWITCH_FOOT_HOLE; 342_SWICH_FOOT_HOLE
TP2: TPTP10R; TP10R
U1: VL53L0X; LGA12_ST
U2: USBC_16P; USBC_16P_FOOT
U3: MCP73831T-2ACI/OT; SOT23-5
U4: XC6206_DEV; SOT23R_INFINEON
U$1, U$12, U$13, U$14: M2_SCREW_DEV; M2_SCREW_FOOT
U$2: HOT_SWAP_COIN_BAT; COIN_BAT_HOTSWAP_SOCKET
U$3: PINHD1X4; 1X04-CLEANBIG
U$4, U$5, U$6, U$7: TESTPAD
U$11: PINHD1X2; 1X02
Y1: 16MHz_12pF; CRYSTAL-SMD-3.2X2.5MM

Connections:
+3V3: C1.1, C2.1, C12.1, C13.1, C14.1, C15.1, IC2.7 (VDD), IC2.15 (VDD), IC2.18 (VDD), IC3.1 (VDD), IC3.5 (VDDA), IC3.17 (VDD), R6.2, R7.2, R8.2, SW2.P$1 (1), SW2.P$4 (4), U1.1 (AVDDVCSEL), U1.11 (AVDD), U4.2 (OUT), U$3.3
GND: C1.2, C2.2, C3.2, C5.2, C6.2, C7.2, C8.2, C9.2, C10.2, C11.2, C12.2, C13.2, C14.2, C15.2, E1.GND, E1.GND2 (GND), IC2.0 (VSS), IC2.8 (VSS), IC2.14 (VSS), IC2.17 (VSS), IC2.20 (VSS), IC3.VSS, R1.2, R2.2, R3.2, R5.2, R9.2, R11.1, R12.1, R13.2, R15.2, SW1.G1 (GND), SW1.G2 (GND), SW1.G3 (GND), SW1.G4 (GND), U1.2 (AVSSVCSEL), U1.3 (GND), U1.4 (GND), U1.6 (GND), U1.12 (GND), U2.A1B12 (GND), U2.B11A12 (GND), U2.P$13 (GND), U2.P$14 (GND), U2.P$15 (GND), U2.P$16 (GND), U3.2 (VSS), U4.1 (GND), U$2.MINUS, U$3.4, Y1.2 (3), Y1.4 (3)
unnamed: C3.1, IC2.19 (DVDD)
unnamed: IC2.16 (IREF), R1.1
unnamed: IC2.13 (ANT2), L1.1, L2.1
unnamed: C4.1, L1.2
unnamed: C4.2, C5.1, E1.ANT (SIGNAL)
unnamed: IC2.12 (ANT1), L2.2, L3.1
unnamed: C8.1, IC2.9 (XC2), Y1.1
unnamed: C6.1, C7.1, IC2.11 (VDD_PA), L3.2
unnamed: C9.1, IC2.10 (XC1), Y1.3 (2)
unnamed: R3.1, U2.B5 (CC2)
unnamed: R2.1, U2.A5 (CC1)
unnamed: LED1.C, R4.1
unnamed: R4.2, U3.1 (STAT)
unnamed: IC2.4 (MOSI), IC3.28 (PB5)
unnamed: IC2.5 (MISO), IC3.27 (PB4)
unnamed: IC2.3 (SCK), IC3.26 (PB3)
unnamed: JP2.2, R5.1, U3.5 (PROG)
unnamed: IC3.24 (PA14), U$11.2
unnamed: D2.A, SW1.2
unnamed: IC2.2 (CSN), IC3.29 (PB6)
unnamed: IC2.1 (CE), IC3.3 (PC15), R9.1
unnamed: IC2.6 (IRQ), IC3.25 (PA15)
unnamed: IC3.9 (PA3), LED2.A
unnamed: R8.1, U1.5 (XSHUT)
unnamed: C10.1, SW1.3 (S), U3.3 (VBAT), U$2.PLUS
unnamed: D1.A, U2.A4B9 (VBUS), U2.B4A9 (VBUS)
unnamed: C11.1, D1.C, D2.C, LED1.A, R10.2, U3.4 (VDD), U4.3 (IN)
unnamed: LED2.C, R12.2
unnamed: IC3.23 (PA13), U$11.1
unnamed: IC3.2 (PC14), IC3.31 (BOOT0), R13.1, SW2.P$2 (2), SW2.P$3 (3)
unnamed: IC3.20 (PA10), U$3.2
unnamed: IC3.19 (PA9), U$3.1
unnamed: IC3.10 (PA4), U$5.P$1
unnamed: IC3.11 (PA5), U$4.P$1
unnamed: IC3.15 (PB1), R10.1, R11.2
unnamed: IC3.6 (PA0), TP2.TP, U1.7 (GPIO1)
unnamed: IC3.12 (PA6), U$7.P$1
unnamed: JP2.1, R15.1
unnamed: IC3.32 (PB8), R7.1, U1.10 (SCL)
unnamed: IC3.30 (PB7), R6.1, U1.9 (SDA)
unnamed: IC3.13 (PA7), U$6.P$1
USB_DM: IC3.21 (PA11), U2.A7 (DN1), U2.B7 (DN2)
USB_DP: IC3.22 (PA12), U2.A6 (DP1), U2.B6 (DP2)

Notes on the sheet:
Charge current: I_CHG = 1000 / R_PROG

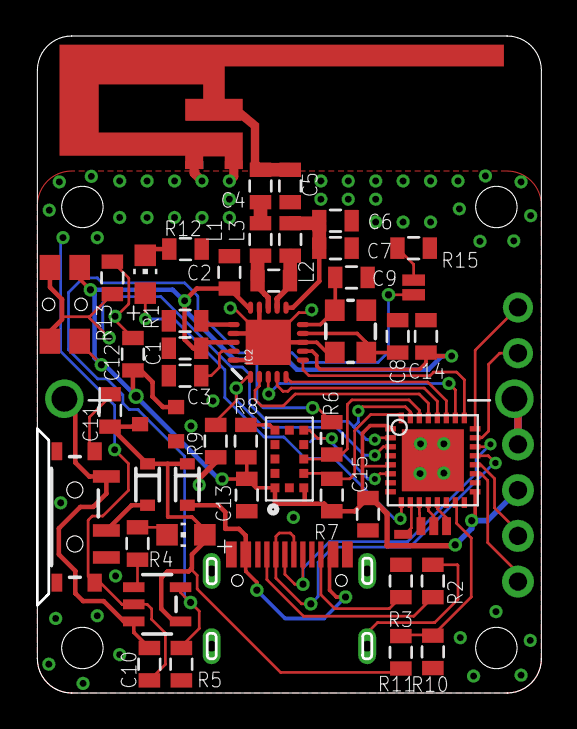
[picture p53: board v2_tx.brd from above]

Board: 2 copper layers, 28.0 x 36.5 mm, 59 parts (1 on the bottom side), 45 nets.

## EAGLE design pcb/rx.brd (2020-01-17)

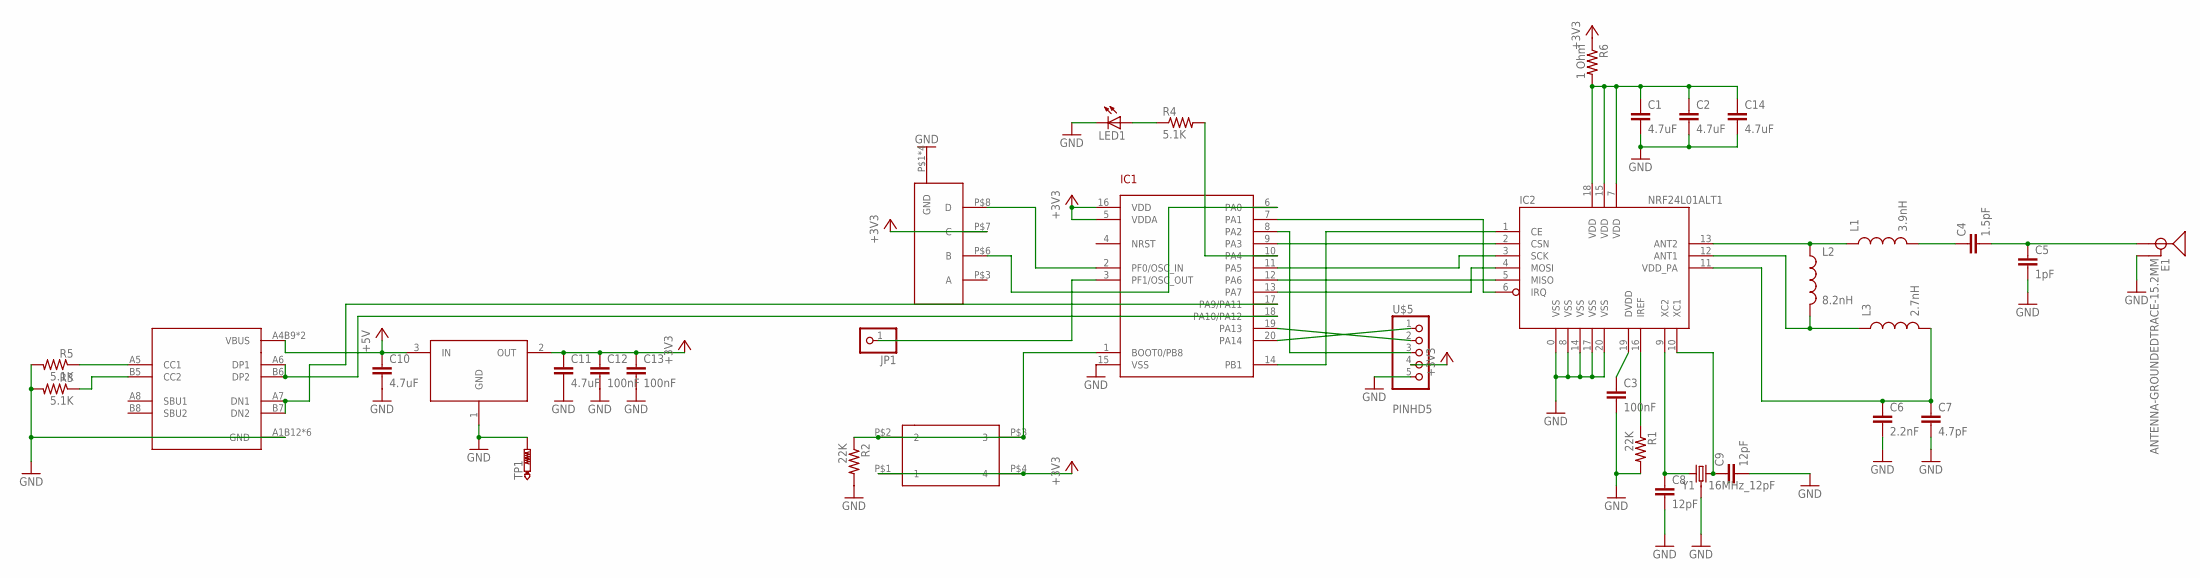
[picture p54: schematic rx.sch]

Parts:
C1, C2, C10, C11, C14: 4.7uF; 0805
C3, C12, C13: 100nF; 0805
C4: 1.5pF; 0805
C5: 1pF; 0805
C6: 2.2nF; 0805
C7: 4.7pF; 0805
C8, C9: 12pF; 0805
E1: ANTENNA-GROUNDEDTRACE-15.2MM; TRACE_ANTENNA_2.4GHZ_15.2MM
IC1: STM32F042F4; TSSOP20
IC2: NRF24L01ALT1; QFN20_ALT1
JP1: PINHD-1X1CB; 1X01-CLEANBIG
L1: 3.9nH; 0805
L2: 8.2nH; 0805
L3: 2.7nH; 0805
LED1: LEDCHIP-LED0805; CHIP-LED0805
R1, R2: 22K; 0805
R3, R4, R5: 5.1K; 0805
R6: 1 Ohm; 0805
SW1: SW_3POS_DEVSW_3POS_OFFICIAL; SW_3POS_FOOT_OFFICIAL
SW2: 324_SW324_SWITCH_FOOT_HOLE; 342_SWICH_FOOT_HOLE
TP1: PTR1TP18R; TP18R
U1: USBC_16P; USBC_16P_FOOT
U2: XC6206_DEV; SOT23R_INFINEON
U$5: PINHD5; 1X05
Y1: 16MHz_12pF; CRYSTAL-SMD-3.2X2.5MM

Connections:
+3V3: C11.1, C12.1, C13.1, IC1.5 (VDDA), IC1.16 (VDD), R6.1, SW1.P$7 (C), SW2.P$1 (1), SW2.P$4 (4), U2.2 (OUT), U$5.4
+5V: C10.1, U1.A4B9 (VBUS), U1.B4A9 (VBUS), U2.3 (IN)
GND: C1.2, C2.2, C3.2, C5.2, C6.2, C7.2, C8.2, C9.2, C10.2, C11.2, C12.2, C13.2, C14.2, E1.GND, IC1.15 (VSS), IC2.0 (VSS), IC2.8 (VSS), IC2.14 (VSS), IC2.17 (VSS), IC2.20 (VSS), LED1.C, R1.2, R2.2, R3.2, R5.2, SW1.P$1 (GND), SW1.P$2 (GND), SW1.P$4 (GND), SW1.P$5 (GND), TP1.TP, U1.A1B12 (GND), U1.B11A12 (GND), U1.P$13 (GND), U1.P$14 (GND), U1.P$15 (GND), U1.P$16 (GND), U2.1 (GND), U$5.5, Y1.2 (3), Y1.4 (3)
unnamed: C3.1, IC2.19 (DVDD)
unnamed: IC2.16 (IREF), R1.1
unnamed: IC2.13 (ANT2), L1.1, L2.1
unnamed: C4.1, L1.2
unnamed: C4.2, C5.1, E1.ANT (SIGNAL)
unnamed: IC2.12 (ANT1), L2.2, L3.1
unnamed: C8.1, IC2.9 (XC2), Y1.1
unnamed: C6.1, C7.1, IC2.11 (VDD_PA), L3.2
unnamed: C9.1, IC2.10 (XC1), Y1.3 (2)
unnamed: IC1.2 (PF0/OSC_IN), SW1.P$8 (D)
unnamed: IC1.1 (BOOT0/PB8), R2.1, SW2.P$2 (2), SW2.P$3 (3)
unnamed: IC1.17 (PA9/PA11), U1.A7 (DN1), U1.B7 (DN2)
unnamed: IC1.18 (PA10/PA12), U1.A6 (DP1), U1.B6 (DP2)
unnamed: IC1.12 (PA6), IC2.5 (MISO)
unnamed: IC1.13 (PA7), IC2.4 (MOSI)
unnamed: IC1.11 (PA5), IC2.3 (SCK)
unnamed: IC1.19 (PA13), U$5.2
unnamed: LED1.A, R4.1
unnamed: IC1.3 (PF1/OSC_OUT), JP1.1
unnamed: IC1.20 (PA14), U$5.1
unnamed: IC1.8 (PA2), U$5.3
unnamed: IC1.14 (PB1), IC2.1 (CE)
unnamed: IC1.10 (PA4), R4.2
unnamed: IC1.9 (PA3), IC2.2 (CSN)
unnamed: R3.1, U1.B5 (CC2)
unnamed: IC1.6 (PA0), SW1.P$6 (B)
unnamed: R5.1, U1.A5 (CC1)
unnamed: C1.1, C2.1, C14.1, IC2.7 (VDD), IC2.15 (VDD), IC2.18 (VDD), R6.2
unnamed: IC1.7 (PA1), IC2.6 (IRQ)

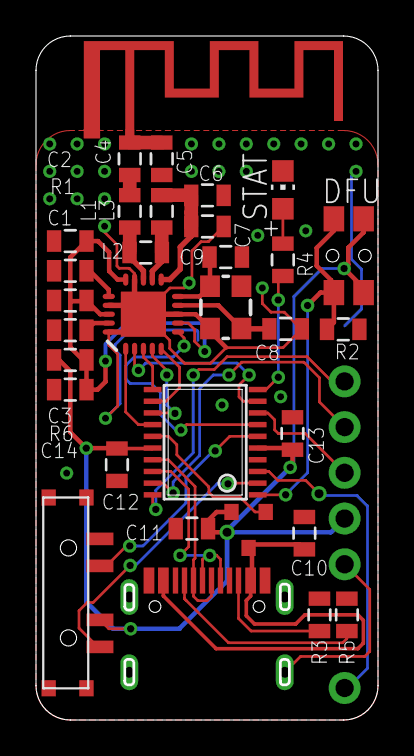
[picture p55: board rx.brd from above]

Board: 2 copper layers, 19.0 x 38.0 mm, 35 parts (1 on the bottom side), 32 nets.

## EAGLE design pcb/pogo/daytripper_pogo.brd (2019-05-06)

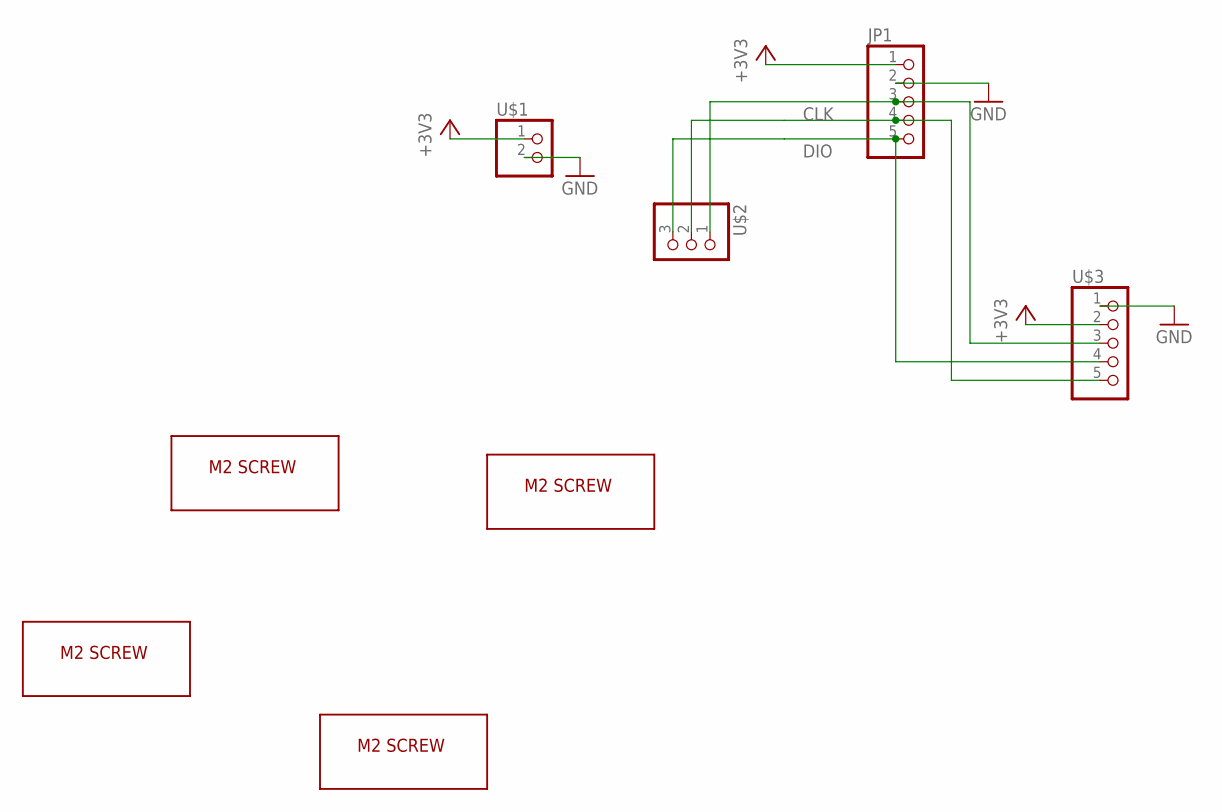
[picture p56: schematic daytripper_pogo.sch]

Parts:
JP1: PINHD-1X5; 1X05
U$1: POGO-1X2; 1X02
U$2: POGO-1X3; 1X03
U$3: POGO-1X5; 1X05
U$4, U$12, U$13, U$14: M2_SCREW_DEV; M2_SCREW_FOOT

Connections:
+3V3: JP1.1, U$1.1, U$3.2
CLK: JP1.4, U$2.2, U$3.5
DIO: JP1.5, U$2.3, U$3.4
GND: JP1.2, U$1.2, U$3.1
unnamed: JP1.3, U$2.1, U$3.3

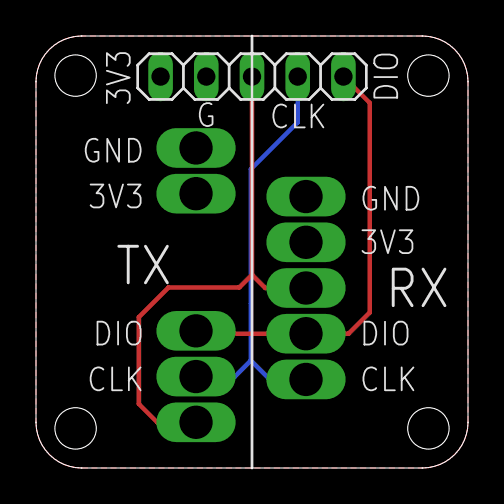
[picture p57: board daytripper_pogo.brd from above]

Board: 2 copper layers, 24.0 x 24.0 mm, 8 parts (0 on the bottom side), 5 nets.

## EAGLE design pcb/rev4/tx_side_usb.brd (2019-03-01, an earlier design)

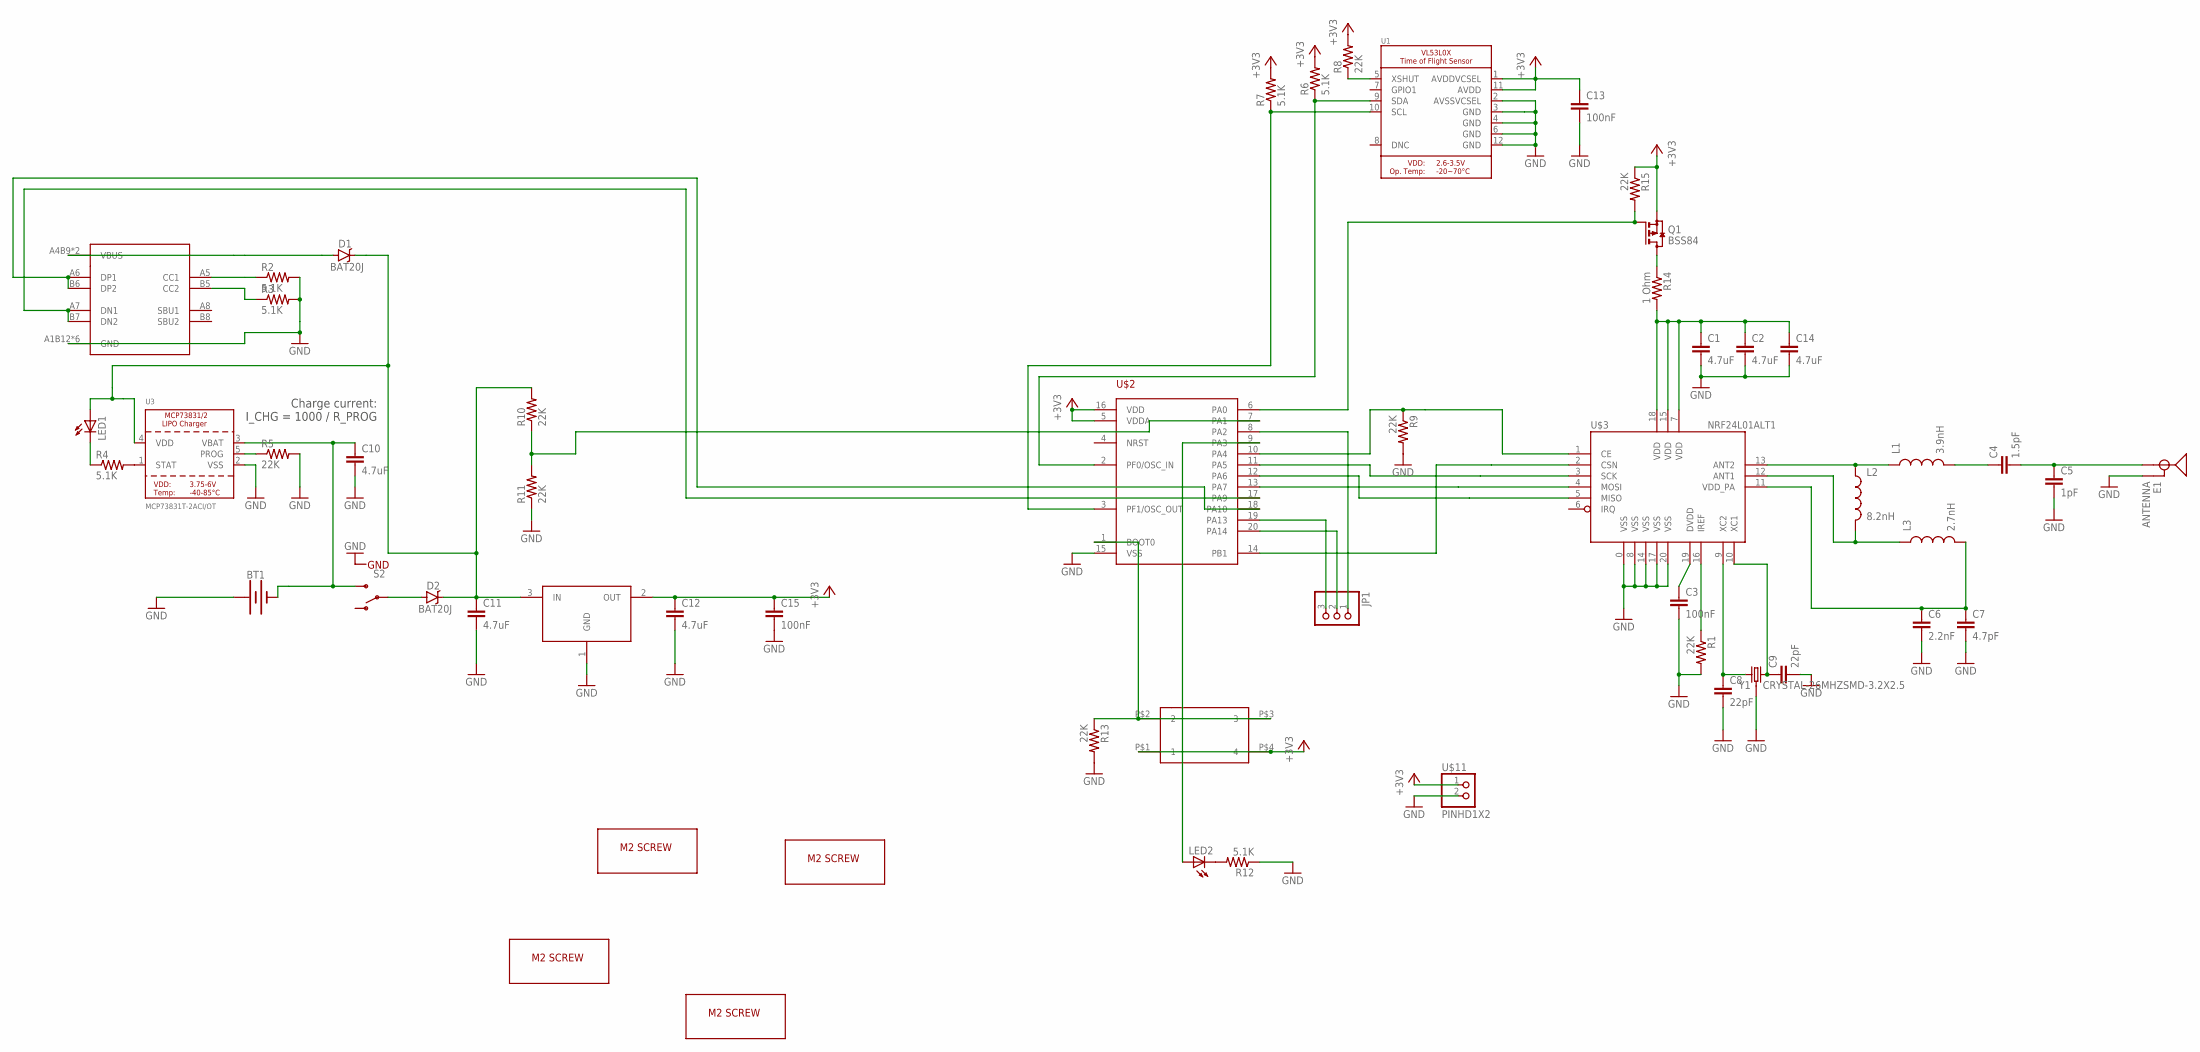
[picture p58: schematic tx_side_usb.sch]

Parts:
BT1: TX_SPARKFUN-BATTERIES_BATTERY-24.5MM_PTH; TX_SPARKFUN-BATTERIES_BATTCON_24.5MM_PTH
C1, C2, C10, C11, C12, C14: 4.7uF; 0805
C3, C13, C15: 100nF; 0805
C4: 1.5pF; 0805
C5: 1pF; 0805
C6: 2.2nF; 0805
C7: 4.7pF; 0805
C8, C9: 22pF; 0805
D1, D2: BAT20J; SOD-323
E1: ANTENNA; TRACE_ANTENNA_2.4GHZ_25.7MM_TUNED
JP1: PINHD-1X3CB; 1X03-CLEANBIG
L1: 3.9nH; 0805
L2: 8.2nH; 0805
L3: 2.7nH; 0805
LED1, LED2: LEDCHIP-LED0805; CHIP-LED0805
Q1: BSS84; SOT23
R1, R5, R8, R9, R10, R11, R13, R15: 22K; 0805
R2, R3, R4, R6, R7, R12: 5.1K; 0805
R14: 1 Ohm; 0805
S2: SWITCH-SPDTTDFGDFG; SWITCH-SPST-SMD-A
U1: VL53L0X; LGA12_ST
U3: MCP73831T-2ACI/OT; SOT23-5
U$1, U$12, U$13, U$14: M2_SCREW_DEV; M2_SCREW_FOOT
U$2: STM32F030F4; TSSOP20
U$3: NRF24L01ALT1; QFN20_ALT1
U$4: USBC_16P; USBC_16P_FOOT
U$9: XC6206_DEV; SOT23R_INFINEON
U$10: 324_SW324_SWITCH_FOOT_HOLE; 342_SWICH_FOOT_HOLE
U$11: PINHD1X2; 1X02
Y1: CRYSTAL-26MHZSMD-3.2X2.5; CRYSTAL-SMD-3.2X2.5MM

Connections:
+3V3: C12.1, C13.1, C15.1, Q1.2 (S), R6.2, R7.2, R8.2, R15.1, U1.1 (AVDDVCSEL), U1.11 (AVDD), U$2.5 (VDDA), U$2.16 (VDD), U$9.2 (OUT), U$10.P$1 (1), U$10.P$4 (4), U$11.1
GND: BT1.2 (+), C1.2, C2.2, C3.2, C5.2, C6.2, C7.2, C8.2, C9.2, C10.2, C11.2, C12.2, C13.2, C14.2, C15.2, E1.GND, E1.GND2 (GND), R1.2, R2.2, R3.2, R5.2, R9.2, R11.1, R12.1, R13.2, S2.G1 (GND), S2.G2 (GND), S2.G3 (GND), S2.G4 (GND), U1.2 (AVSSVCSEL), U1.3 (GND), U1.4 (GND), U1.6 (GND), U1.12 (GND), U3.2 (VSS), U$2.15 (VSS), U$3.0 (VSS), U$3.8 (VSS), U$3.14 (VSS), U$3.17 (VSS), U$3.20 (VSS), U$4.A1B12 (GND), U$4.B11A12 (GND), U$4.P$13 (GND), U$4.P$14 (GND), U$4.P$15 (GND), U$4.P$16 (GND), U$9.1 (GND), U$11.2, Y1.2 (3), Y1.4 (3)
unnamed: C3.1, U$3.19 (DVDD)
unnamed: R1.1, U$3.16 (IREF)
unnamed: L1.1, L2.1, U$3.13 (ANT2)
unnamed: C4.1, L1.2
unnamed: C4.2, C5.1, E1.ANT (SIGNAL)
unnamed: L2.2, L3.1, U$3.12 (ANT1)
unnamed: C8.1, U$3.9 (XC2), Y1.1
unnamed: C6.1, C7.1, L3.2, U$3.11 (VDD_PA)
unnamed: C9.1, U$3.10 (XC1), Y1.3 (2)
unnamed: R3.1, U$4.B5 (CC2)
unnamed: R2.1, U$4.A5 (CC1)
unnamed: LED1.C, R4.1
unnamed: R4.2, U3.1 (STAT)
unnamed: U$2.13 (PA7), U$3.4 (MOSI)
unnamed: U$2.12 (PA6), U$3.5 (MISO)
unnamed: U$2.11 (PA5), U$3.3 (SCK)
unnamed: R5.1, U3.5 (PROG)
unnamed: U$2.18 (PA10), U$4.A6 (DP1), U$4.B6 (DP2)
unnamed: D2.A, S2.2
unnamed: U$2.14 (PB1), U$3.2 (CSN)
unnamed: R9.1, U$2.10 (PA4), U$3.1 (CE)
unnamed: R7.1, U1.10 (SCL), U$2.3 (PF1/OSC_OUT)
unnamed: R6.1, U1.9 (SDA), U$2.2 (PF0/OSC_IN)
unnamed: R8.1, U1.5 (XSHUT)
unnamed: BT1.1 (-), C10.1, S2.3 (S), U3.3 (VBAT)
unnamed: D1.A, U$4.A4B9 (VBUS), U$4.B4A9 (VBUS)
unnamed: C11.1, D1.C, D2.C, LED1.A, R10.2, U3.4 (VDD), U$9.3 (IN)
unnamed: LED2.C, R12.2
unnamed: LED2.A, U$2.9 (PA3)
unnamed: R13.1, U$2.1 (BOOT0), U$10.P$2 (2), U$10.P$3 (3)
unnamed: JP1.3, U$2.19 (PA13)
unnamed: JP1.2, U$2.20 (PA14)
unnamed: JP1.1, U$2.8 (PA2)
unnamed: U$2.17 (PA9), U$4.A7 (DN1), U$4.B7 (DN2)
unnamed: R10.1, R11.2, U$2.7 (PA1)
unnamed: C1.1, C2.1, C14.1, R14.2, U$3.7 (VDD), U$3.15 (VDD), U$3.18 (VDD)
unnamed: Q1.3 (D), R14.1
unnamed: Q1.1 (G), R15.2, U$2.6 (PA0)

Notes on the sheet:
Charge current: I_CHG = 1000 / R_PROG

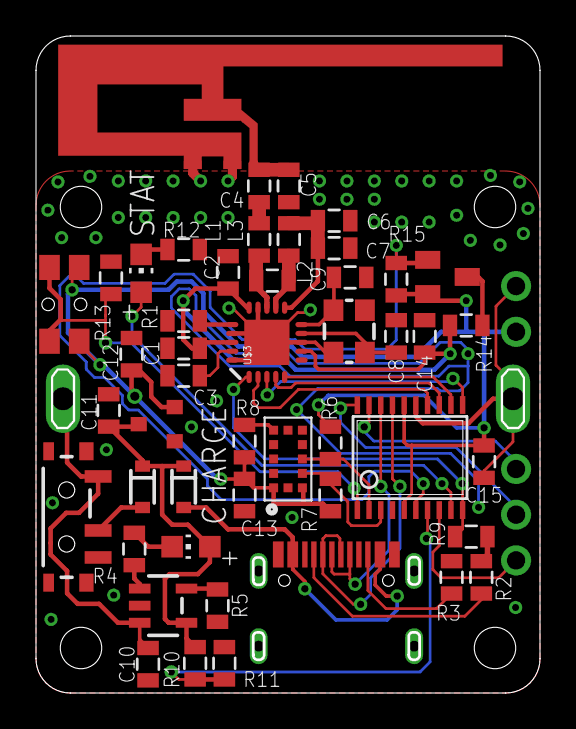
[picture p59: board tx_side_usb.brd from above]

Board: 2 copper layers, 28.0 x 36.5 mm, 55 parts (1 on the bottom side), 40 nets.

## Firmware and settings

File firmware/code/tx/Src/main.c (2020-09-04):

/**
  ******************************************************************************
  * @file           : main.c
  * @brief          : Main program body
  ******************************************************************************
  * This notice applies to any and all portions of this file
  * that are not between comment pairs USER CODE BEGIN and
  * USER CODE END. Other portions of this file, whether 
  * inserted by the user or by software development tools
  * are owned by their respective copyright owners.
  *
  * Copyright (c) 2020 STMicroelectronics International N.V. 
  * All rights reserved.
  *
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
  ******************************************************************************
  */
/* Includes ------------------------------------------------------------------*/
#include "main.h"
#include "stm32f0xx_hal.h"
#include "usb_device.h"

/* USER CODE BEGIN Includes */
#include <stdlib.h>
#include "shared.h"
#include "helpers.h"
#include "nrf24.h"
#include "VL53L0X.h"
#include "animation.h"
#include "ee.h"
#include "my_usb.h"

#define STATE_IDLE 0
#define STATE_TRIGGERED 1

#define CHARGING_VOLTAGE_THRESHOLD_MV 4000

/* USER CODE END Includes */

ADC_HandleTypeDef hadc;

I2C_HandleTypeDef hi2c1;

IWDG_HandleTypeDef hiwdg;

RTC_HandleTypeDef hrtc;

SPI_HandleTypeDef hspi1;

TIM_HandleTypeDef htim2;
TIM_HandleTypeDef htim17;

UART_HandleTypeDef huart2;

/* USER CODE BEGIN PV */
uint8_t data_array[NRF_PAYLOAD_SIZE];
uint8_t rx_address[5] = {0xBE,0xAD,0xA5,0xBA,0xBE};
uint8_t tx_address[5] = {0xDA,0xBB,0xED,0xC0,0x0C};

uint16_t baseline, this_reading;
uint8_t new_stat_packet = 1;
uint8_t current_state = STATE_IDLE;
uint16_t vbat_mV;
uint16_t vbat_mV_prev;
uint16_t power_on_time_5s;
uint16_t trigger_upper_threshold, trigger_lower_threshold;
uint8_t this_battery_adc_value;
/* USER CODE END PV */

void SystemClock_Config(void);
static void MX_GPIO_Init(void);
static void MX_USART2_UART_Init(void);
static void MX_I2C1_Init(void);
static void MX_SPI1_Init(void);
static void MX_RTC_Init(void);
static void MX_TIM2_Init(void);
static void MX_TIM17_Init(void);
static void MX_ADC_Init(void);
static void MX_IWDG_Init(void);

void HAL_TIM_MspPostInit(TIM_HandleTypeDef *htim);
                                

/* USER CODE BEGIN PFP */

/* USER CODE END PFP */

/* USER CODE BEGIN 0 */
int fputc(int ch, FILE *f)
{
  my_usb_putchar((uint8_t)ch);
  if(daytripper_config.print_debug_info)
    HAL_UART_Transmit(&huart2, (unsigned char *)&ch, 1, 10);
  return ch;
}

void HAL_TIM_PeriodElapsedCallback(TIM_HandleTypeDef *htim)
{
  if(htim->Instance == TIM17)
    animation_update();
}

void start_measurement(void)
{
  if(vbat_mV > CHARGING_VOLTAGE_THRESHOLD_MV)
    startContinuous(1);
  else
    startContinuous(1000/daytripper_config.refresh_rate_Hz);
  align_timing();
}

uint8_t is_rtc_calibrated;
uint32_t rtc_calib_temp;
uint8_t rct_calibration_value;
int8_t rtc_offset;

void HAL_RTC_AlarmAEventCallback(RTC_HandleTypeDef *hrtc)
{
  if(is_rtc_calibrated)
    return;
  rct_calibration_value = HAL_GetTick() - rtc_calib_temp;
}

const static uint8_t rtc_calib_lookup[32] = {0, 0, 0, 0, 1, 1, 2, 2, 3, 3, 3, 4, 4, 5, 5, 6, 6, 6, 7, 7, 8, 8, 9, 9, 9, 10, 10, 11, 11, 12, 12, 12};

void rtc_calibrate(void)
{
  rtc_calib_temp = HAL_GetTick();
  rtc_test(&hrtc, 200);
  HAL_Delay(300);
  is_rtc_calibrated = 1;
  if(rct_calibration_value < 184)
    rct_calibration_value = 184;
  else if(rct_calibration_value > 215)
    rct_calibration_value = 215;
  rtc_offset = rtc_calib_lookup[rct_calibration_value - 184];
}

uint8_t is_trigger(uint16_t thisss)
{
	// printf("%d (%d %d) (%d %d)\n", thisss, trigger_lower_threshold, trigger_upper_threshold, daytripper_config.range_max_mm, daytripper_config.range_min_mm);
	if(thisss > daytripper_config.range_max_mm || thisss < daytripper_config.range_min_mm)
		return 0;
	return thisss < trigger_lower_threshold || thisss > trigger_upper_threshold;
}

/* USER CODE END 0 */

/**
  * @brief  The application entry point.
  *
  * @retval None
  */
int main(void)
{
  /* MCU Configuration----------------------------------------------------------*/

  /* Reset of all peripherals, Initializes the Flash interface and the Systick. */
  HAL_Init();

  /* Configure the system clock */
  SystemClock_Config();

  /* Initialize all configured peripherals */
  MX_GPIO_Init();
  MX_USART2_UART_Init();
  MX_I2C1_Init();
  MX_SPI1_Init();
  MX_TIM2_Init();
  MX_TIM17_Init();
  MX_ADC_Init();
  MX_USB_DEVICE_Init();
  /* USER CODE BEGIN 2 */
  my_usb_init();
  MX_RTC_Init();
  HAL_RTC_DeactivateAlarm(&hrtc, RTC_ALARM_A);
  NRF_ON();
  VL53L0X_init();
  dt_conf_load_default(&daytripper_config);
  printf("\n\ndaytripper TX\ndekuNukem 2020\n\n");
  dt_conf_load(&daytripper_config);
  // dt_conf_print(&daytripper_config);
  animation_init(&htim17, &htim2);
  start_animation(ANIMATION_TYPE_BREATHING);
  HAL_Delay(2000);

  if(HAL_RTCEx_BKUPRead(&hrtc, 0) == RTC_BKUP_SLEEP)
  {
    // printf("rtc shutdown\n");
    sys_shutdown();
  }
  for (int i = 0; i < BATTERY_HISTORY_SIZE; ++i)
  {
    add_battery_history(get_battery_adc_reading());
    HAL_Delay(50);
  }
  if(is_low_battery())
    sys_shutdown();

  memset(battery_reading_history, 0, BATTERY_HISTORY_SIZE);
  vbat_mV = get_battery_adc_reading() * ADC_COEFFICIENT;
  vbat_mV_prev = vbat_mV;
  rtc_calibrate();
  // printf("rct_calibration_value: %d\n", rct_calibration_value);
  // printf("rtc_offset: %d\n", rtc_offset);
  // this should be behind get_battery_adc_reading, so it can completely shut down in low battery situation
  MX_IWDG_Init();
  /* USER CODE END 2 */

  /* Infinite loop */
  /* USER CODE BEGIN WHILE */
  setTimeout(500);
  // in microseconds, longer time better accruacy, but consumes more power
  setMeasurementTimingBudget((uint32_t)daytripper_config.tof_timing_budget_ms * 1000); // default 33000

  // printf("initializing NRF...");
  nrf24_init();
  nrf24_config(NRF_CHANNEL, NRF_PAYLOAD_SIZE);
  tx_address[4] = daytripper_config.tx_wireless_channel;
  nrf24_tx_address(tx_address);
  nrf24_rx_address(rx_address);
  HAL_GPIO_WritePin(NRF_CE_GPIO_Port, NRF_CE_Pin, GPIO_PIN_RESET);
  HAL_GPIO_WritePin(SPI1_CS_GPIO_Port, SPI1_CS_Pin, GPIO_PIN_SET);
  // printf(" done\n");
  tof_calibrate(&baseline, &trigger_upper_threshold, &trigger_lower_threshold);
  start_measurement();
  start_animation(ANIMATION_TYPE_CONST_OFF);
  while (1)
  {
    HAL_IWDG_Refresh(&hiwdg);
    parse_cmd(my_usb_readline());

    // every 5 seconds
    if(rtc_counter > 5000)
    {
      power_on_time_5s++; // update power-on counter
      if(power_on_time_5s % 180 == 0) // 5 * 180 = 900s = 15mins, send stat update every 15 minutes
        new_stat_packet = 1;
      this_battery_adc_value = get_battery_adc_reading();
      vbat_mV = this_battery_adc_value * ADC_COEFFICIENT;
      if(power_on_time_5s % 60 == 0)
      {
        add_battery_history(this_battery_adc_value);
        // printf("vbat_mV: %d\n", vbat_mV);
        if(is_low_battery())
        {
          // write to RTC register, kick dog then reset, check rtc register on startup, and go to sleep if needed
          HAL_RTCEx_BKUPWrite(&hrtc, 0, RTC_BKUP_SLEEP);
          // printf("HHHH\n");
          HAL_IWDG_Refresh(&hiwdg);
          NVIC_SystemReset();
        }
      }

      rtc_counter = 0;
    }

  /* USER CODE END WHILE */

  /* USER CODE BEGIN 3 */
    if(new_stat_packet)
    {
      build_packet_stat(data_array, vbat_mV, power_on_time_5s);
      // printf("sending stat... vbat_mV: %d\n", vbat_mV);
      send_packet(data_array);
      new_stat_packet = 0;
    }

    // get a new distance reading from laser ToF sensor
    this_reading = get_continuous_distance_reading(&is_reading_valid);
    if(is_reading_valid == 0)
      goto sleep;

    // if the change in distance is big enough...
    if(current_state == STATE_IDLE && is_trigger(this_reading))
    {
      uint8_t count = 0;
      uint16_t temp;
      printf(">> b:%d t0:%d ", baseline, this_reading);
      // .. take another reading back-to-back, to make sure it's not sensor noise
      while(count < daytripper_config.nr_sensitivity)
      {
        HAL_IWDG_Refresh(&hiwdg);
        temp = get_single_distance_reading(&is_reading_valid);
        printf("t%d:%d ", count+1, temp);
        if(is_reading_valid == 0)
          continue;
        if(is_trigger(temp) == 0)
        {
          printf("X\n");
          start_measurement();
          goto sleep;
        }
        count++;
      }
      printf("\n");
      build_packet_trig(data_array, baseline, this_reading);
      send_packet(data_array);
      if(daytripper_config.use_led)
        start_animation(ANIMATION_TYPE_CONST_ON);
      start_measurement();
      current_state = STATE_TRIGGERED;
    }
    else if(current_state == STATE_TRIGGERED && is_trigger(this_reading) == 0)
    {
      start_animation(ANIMATION_TYPE_CONST_OFF);
      current_state = STATE_IDLE;
      align_timing();
    }

    sleep:
    HAL_IWDG_Refresh(&hiwdg);
    nrf24_powerDown();
    
    if(vbat_mV > CHARGING_VOLTAGE_THRESHOLD_MV && vbat_mV_prev <= CHARGING_VOLTAGE_THRESHOLD_MV)
    {
      printf("charging\n");
      start_measurement();
    }
    if(vbat_mV <= CHARGING_VOLTAGE_THRESHOLD_MV && vbat_mV_prev > CHARGING_VOLTAGE_THRESHOLD_MV)
    {
      printf("unplugged\n");
      start_measurement();
    }
    vbat_mV_prev = vbat_mV;

    if(vbat_mV < CHARGING_VOLTAGE_THRESHOLD_MV) // only sleep while on battery, when charging go full speed
      rtc_sleep(&hrtc, 1000/daytripper_config.refresh_rate_Hz - rtc_offset);
    else
      run_time_update(24); // if charging, dont sleep, but still update the time count
  }
  /* USER CODE END 3 */

}

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


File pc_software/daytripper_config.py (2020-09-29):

import os
import time
import copy
import json
import datetime
import shutil
import pathlib
import dt_objs
import webbrowser
import check_update
from functools import partial
from tkinter import *
from tkinter import filedialog
from tkinter import simpledialog
from tkinter import messagebox
import serial.tools.list_ports
import serial
import urllib.request

THIS_VERSION_NUMBER = '0.2.0'
MAIN_WINDOW_WIDTH = 720
MAIN_WINDOW_HEIGHT = 470
PADDING = 10
HEIGHT_CONNECT_LF = 50
discord_link_url = "https://raw.githubusercontent.com/dekuNukem/daytripper/master/resources/discord_link.txt"

def open_user_manual_url():
    webbrowser.open('https://github.com/dekuNukem/daytripper/blob/master/quick_start_guide.md')

def open_discord_link():
    try:
        webbrowser.open(str(urllib.request.urlopen(discord_link_url).read().decode('utf-8')).split('\n')[0])
    except Exception as e:
        messagebox.showerror("Error", "Failed to open discord link!\n"+str(e))

def create_help_window():
    help_window = Toplevel(root)
    help_window.title("Daytripper help")
    help_window.geometry("280x130")
    help_window.resizable(width=FALSE, height=FALSE)

    user_manual_label = Label(master=help_window, text="Not sure what to do? Please read...")
    user_manual_label.place(x=35, y=5)
    user_manual_button = Button(help_window, text="User Manual", command=open_user_manual_url)
    user_manual_button.place(x=60, y=30, width=160)

    discord_label = Label(master=help_window, text="Questions or comments? Ask in...")
    discord_label.place(x=35, y=60)
    discord_button = Button(help_window, text="Official Discord Chatroom", command=open_discord_link)
    discord_button.place(x=50, y=85, width=180)

def ensure_dir(dir_path):
    if not os.path.exists(dir_path):
        os.mkdir(dir_path)

root = Tk()
root.title("Daytripper configurator v" + THIS_VERSION_NUMBER)
root.geometry(str(MAIN_WINDOW_WIDTH) + "x" + str(MAIN_WINDOW_HEIGHT))
root.resizable(width=FALSE, height=FALSE)
daytripper_config = dt_objs.dt_config()

# ------------- serial select -------------

connection_lf = LabelFrame(root, text="Connection", width=MAIN_WINDOW_WIDTH - PADDING*2, height=HEIGHT_CONNECT_LF)
connection_lf.place(x=PADDING, y=0)
root.update()

serial_var = StringVar()
serial_var.set(' ')
OptionList = ['']
serial_optlist = OptionMenu(connection_lf, serial_var, *OptionList)
serial_optlist.place(x=115, y=0, width=240)
ser = serial.Serial()
ser.baudrate = 115200
hwif_label_stringvar = StringVar()

def serial_setname(wtf):
    serial_var.set(wtf)

def serial_dropdown_refresh():
    serial_optlist['menu'].delete(0, 'end')
    port_list = serial.tools.list_ports.comports()
    for item in port_list:
        port_name = str(item.device)
        serial_optlist['menu'].add_command(label=port_name, command=partial(serial_setname, port_name))
    if serial_var.get() == ' ' or serial_var.get() not in [str(x.device) for x in port_list]:
        serial_var.set(str(port_list[0].device))
    usb_port_list = [str(x.device) for x in port_list if 'usb' in str(x.device).lower()]
    if len(usb_port_list) > 0:
        serial_var.set(usb_port_list[0])

MODELID_STDRANGE_VL53L0X = 0xee
MODELID_LONGRANGE_VL53L1X = 0xcc

def make_info_string():
    if daytripper_config.is_valid is False:
        return ''
    model_string = 'Unknown'
    if daytripper_config.daytripper_type == 'tx':
        model_string = "Daytripper TX"
    elif daytripper_config.daytripper_type == 'rx':
        model_string = "Daytripper RX"

    id_string = str(daytripper_config.hardware_id) + '(' + str(hex(daytripper_config.hardware_id)) + ')'
    fw_ver_string = str(daytripper_config.fw_version_major) + '.' + str(daytripper_config.fw_version_minor) + '.' + str(daytripper_config.fw_version_patch)
    tof_type_string = 'Unknown'
    if daytripper_config.tof_model_id == MODELID_STDRANGE_VL53L0X:
        tof_type_string = 'Standard Range (120cm)'
    elif daytripper_config.tof_model_id == MODELID_LONGRANGE_VL53L1X:
        tof_type_string = 'Long Range (400cm)'
    return "Type: " + model_string + '      Unique ID: ' + id_string + '      FW Version: ' + fw_ver_string + '      Laser Sensor: ' + tof_type_string

def get_max_range_cm():
    if daytripper_config.is_valid is False:
        return 0
    if daytripper_config.tof_model_id == MODELID_STDRANGE_VL53L0X:
        return 120
    elif daytripper_config.tof_model_id == MODELID_LONGRANGE_VL53L1X:
        return 400
    return 0

def fw_update_click(what):
    webbrowser.open('https://github.com/dekuNukem/daytripper/blob/master/advanced_usage.md#usb-firmware-updates')
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

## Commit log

2018-08-13 adding stuff in
    [Adafruit Feather M0 Adalogger.brd, Adafruit Feather M0 Adalogger.sch, Adafruit VL53L0X.brd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]
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2018-10-05 found antenna
    [CC2541_Breakout_Board.brd, CC2541_Breakout_Board.sch, MIFA.brd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]
2018-10-05 building it up
    [MIFA.brd, rxSD.brd, rxSD.sch]
2018-10-12 dt rx done
    [rx.brd, rx.sch, tx.brd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]
2018-10-13 before tx firmware test
    [tx.brd, tx.sch]
2018-10-13 i2c not working
2018-10-14 tx before cleanup
    [tx.brd, tx.sch]
2018-10-14 tx almost done
    [tx.brd, tx.sch]
2018-10-15 further cleanup
    [rx.brd, rx.sch, tx.brd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]
2018-10-15 thinking about switch to tssop20
    [rx.brd, rx.sch, tx.brd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]
2018-10-16 switched rx to tssop20
    [rx20.brd, rx20.sch, tx.brd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]
2018-10-17 ready for fab
    [rx.brd, rx.sch, rx20.brd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]
2018-10-26 adjust usbc connector paste layer
    [tx.brd, tx.sch]
2018-10-31 fix silkscreen error, added pogo board
    [daytripper_pogo.brd, daytripper_pogo.sch, rx.brd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]
2018-11-06 added holes to button
    [rx.brd, rx.sch, tx.brd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]
2018-11-07 laser works
    [tx.brd, tx.sch]
2018-11-07 txrx working, range limited
    [tx.brd]
2018-11-13 updated PCB, firmware sleep working
    [rx.brd, rx.sch, tx.brd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]
2018-11-14 triggering done, more pcb refine
    [tx.brd, tx.sch]
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2018-11-15 adc single channel working
    [tx.brd]
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2018-11-16 tx almost done, si24 broke?
    [helpers.c, main.c]
2019-02-18 usb on tx
    [tx.brd, tx.sch]
2019-02-19 txrx rev2 finished
    [rx_usba.brd, rx_usba.sch, tx.brd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]
2019-02-19 switched to chip antenna
    [rx.brd, rx.sch, tx.brd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]
2019-02-19 gerber added
    [rx_usba.brd, rx_usba.sch, tx.brd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]
2019-02-24 GND plane, trace antenna, clean up
    [Adafruit Feather M0 Adalogger.brd, Adafruit Feather M0 Adalogger.sch, rx.brd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]
2019-02-24 changed copyright date
    [rx.brd, tx.brd]
2019-02-25 added more power filtering, added RX interrupt
    [rx.brd, rx.sch, tx.brd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]
2019-02-25 adjusted silkscreen
    [rx.brd, tx.brd]
2019-02-25 adjusted RF section
    [rx.brd, rx.sch]
2019-02-25 rev3 done
    [rx.brd, tx.brd]
2019-02-25 added mounting plate
    [rx.brd, rx.sch, tx.brd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]
2019-02-26 rx led always on
2019-03-01 rev3 working
    [rx.brd, rx.sch, tx.brd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]
2019-03-01 tx added mosfet switch
    [tx.brd, tx.sch]
2019-03-01 rev4 cleanup, new plate
    [tx.brd, tx.sch]
2019-03-02 added mounting hole plating
    [tx.brd, tx_side_usb.brd, tx_side_usb.sch]
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2019-03-03 tx kb print, low bat warning, tx cleanup
2019-03-03 added battery life testing script
2019-03-04 vcc cutoff not working very well
    [VL53L0X.c, animation.c, helpers.c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]
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2019-05-06 redesigned pogo board
    [daytripper_pogo.brd, daytripper_pogo.sch]
2019-05-10 adjusted battery cutoff voltage
2019-05-15 tx board removed jumper
    [rx.brd, rx.sch]
2019-05-19 before trail run
    [rx.brd, rx.sch, tx.brd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]
2019-05-19 centered usbc footprint, adjusted board layout
    [rx.brd, rx.sch, tx.brd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]
2019-05-20 foodprint adjustment, coord file
    [rx.brd, rx.sch, tx.brd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]
2019-05-21 adjusted timing budget, distance under 15mm are now ignored
    [rx.brd, rx.sch, tx.brd]
2019-06-09 updated USBC connector, check_battery DBZ
    [rx.brd, rx.sch, tx.brd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]
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2019-06-13 before working on adc
2019-06-19 tx low battery flashing
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2019-08-11 added more clearance near battery terminal
    [tx.brd]
2019-08-11 added warnings about switches
2019-08-22 pcb cleanup
    [rx.brd, tx.brd, tx.sch]
2019-08-23 added notes about magnet
2019-10-05 added trig_out on RX, preparing for next production run
    [rx.brd, rx.sch, tx.brd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]
2019-10-11 added glitch doc
    [rx.brd, rx.sch, tx.brd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]
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2019-12-18 adjusted RX keypress duration, added firmware that disables blue LED, verified refresh rate, updated superfast firmware
2019-12-18 added link to no-LED firmware
2020-01-17 added a GND pad near trigger out on RX
    [rx.brd, rx.sch]
2020-05-24 trying out a new sensor
    [tx.brd, tx.sch]
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2020-07-09 running full speed while charging
2020-07-09 added option to disable printing debug info to UART
2020-08-07 added min distance in firmware, bug fixes
    [helpers.c, helpers.h, main.c]
2020-08-07 clean up debug print
2020-08-13 added charging detection in continuous mode
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2020-08-13 pcb revision no transisitor
    [tx.brd, tx.sch]
2020-08-13 added a testpad
    [tx.brd, tx.sch]
2020-08-13 rearranged files
    [tx_no_transistor.brd, tx_no_transistor.sch]
2020-08-17 switched to split threshold triggering
2020-08-19 fixed flash overwrite bug
    [helpers.c, main.c]
2020-08-20 adjust default value of debug print in pc app
2020-08-20 enabled battery voltage debug message
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2020-08-23 adjust low-batter shutoff voltage
2020-08-24 added adjustable charging current select
    [tx_no_transistor_adjustable_charging_current.brd, tx_no_transistor_adjustable_charging_current.sch]
2020-08-24 changed default scan rate to 6Hz
2020-08-25 adjusted low battery shutoff voltage threshold
2020-08-29 refined battery monitoring, added battery life table
2020-09-04 improved rx debug print
2020-09-04 rx debug printout fix
    [main.c]
2020-09-05 added instruction about DFU driver install
2020-09-29 updated build script, fixed update text bug
    [daytripper_config.py, helpers.c]
2021-02-14 added battery socket
    [tx_no_transistor_adjustable_charging_current_hotswap.brd, tx_no_transistor_adjustable_charging_current_hotswap.sch]
2021-02-14 new TX header with extra pin
    [tx.brd, tx.sch, tx_no_transistor.brd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]
2021-02-17 hooked up new MCU
    [tx_v2.brd, tx_v2.sch]
2021-02-17 added switch cutout and testpads
    [tx_v2.brd, tx_v2.sch]
2021-02-17 cleaned up
    [tx_v2.brd]
2021-02-20 updated new pogo board
    [v2_pogo.brd, v2_pogo.sch, v2_tx.brd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]
2021-03-17 updated pogo board
    [v2_pogo.brd, v2_pogo.sch]
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2021-07-17 ADC working with vrefint
2021-07-18 tof gpio interrupt working, stop mode not working
    [main.c, main.h]
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2021-07-21 EXTI wakeup working, needs to adjust UART speed
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

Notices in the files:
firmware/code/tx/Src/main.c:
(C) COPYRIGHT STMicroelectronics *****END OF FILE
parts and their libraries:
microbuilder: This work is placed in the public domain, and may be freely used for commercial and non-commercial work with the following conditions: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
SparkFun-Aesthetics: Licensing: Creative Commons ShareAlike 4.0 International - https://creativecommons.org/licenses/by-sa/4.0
